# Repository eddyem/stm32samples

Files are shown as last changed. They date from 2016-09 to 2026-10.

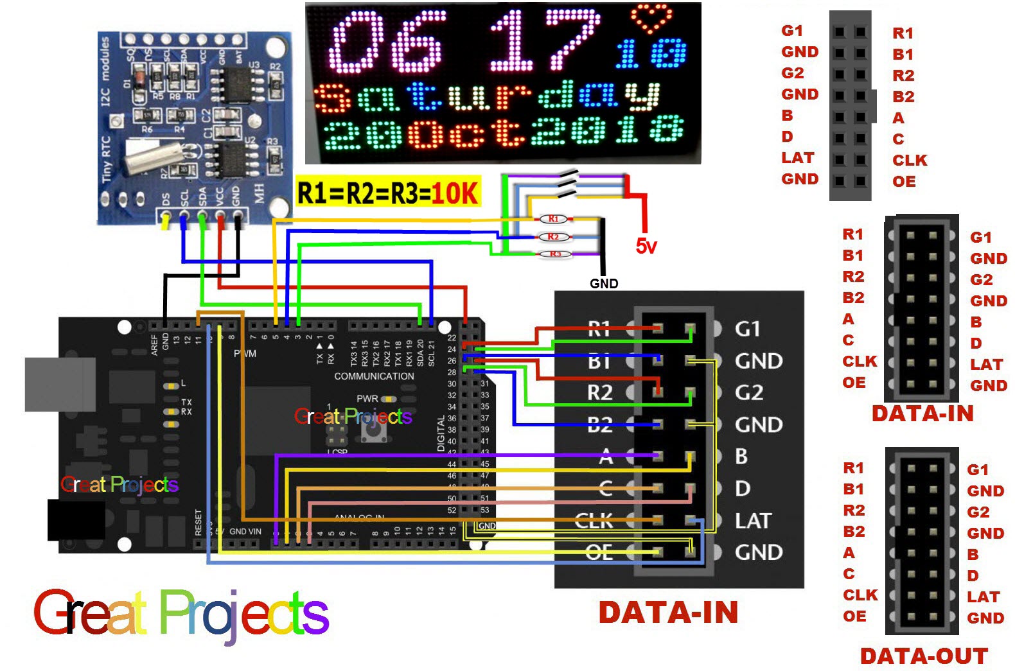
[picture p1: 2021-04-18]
F1:F103/RGB_LED_Screen/img/P4RGBmatrix.jpg

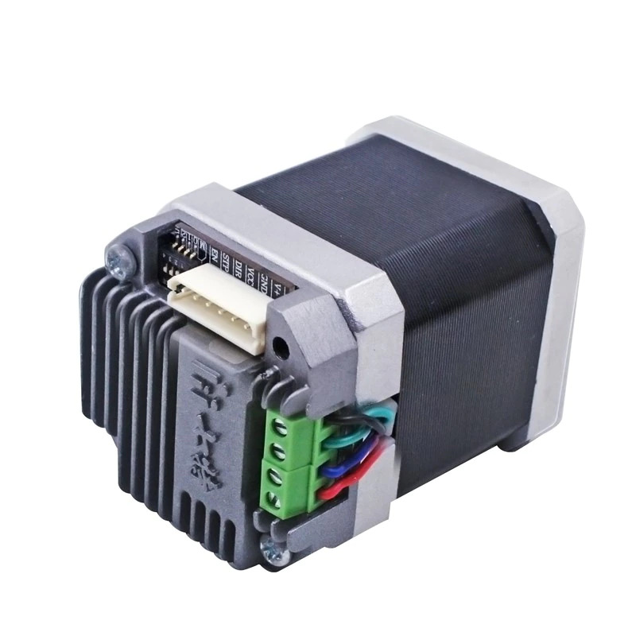
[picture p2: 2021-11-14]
F0:F030,F042,F072/3steppersLB/stepper_driver/08.jpg

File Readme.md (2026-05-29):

# Repository Overview

The `stm32samples` repository is a collection of low-level, bare-metal code examples and complete
projects for various STM32 microcontroller series (F0, F1, F3, F4, G0). It uses CMSIS header files
from `modm-io/cmsis-header-stm32` for register definitions.

## Project Structure by MCU Series

### STM32F0 (F030, F042, F072)
- **3steppersLB** – Controls 3 stepper motors with encoders via USB/CAN bus
- **blink** – Simple LED toggling
- **CANbus4BTA** – CAN replacement for PEP-CAN
- **CANBUS_SSI** – Works with BTA SSI azimuth encoder
- **Chiller** – Basic chiller temperature controller
- **F0_testbrd** – Tests STM32F0x2 on custom board
- **htu21d_nucleo** – Reads HTU-21D sensor on Nucleo-F042K
- **morze** – Echoes USART1 data as Morse code on TIM3CH1 (PA6)
- **NUCLEO_SPI** – SSI over SPI on Nucleo-F042K
- **PL2303_ringbuffer** – USB CDC ACM with ring buffers
- **QuadEncoder** – Quadrature encoder via timer
- **Servo** – Controls SG-90 style servos
- **Socket_fans** – Manages multiple fans
- **TM1637** – Drives 7‑segment displays
- **tsys01_nucleo** – Reads two TSYS01 sensors
- **uart_blink & uart_blink_dma** – USART echo with DMA
- **usbcan_relay** – Relay board over CAN bus
- **usbcan_ringbuffer** – USB‑CAN adapter with ring buffers
- **USBHID** – USB HID keyboard + mouse

### STM32F1 (F103) 
- **BMP180, BMP280** – I²C temperature/pressure sensors
- **Canon_managing_device** – Controls Canon lenses
- **canUART** – UART‑CAN bridge
- **DHT22_DHT11** – Humidity sensors using timer+DMA
- **DS18** – DS18x20 temperature sensors
- **F1_testbrd** – Test board for LQFP48 packages
- **I2Cscan** – I²C scanner with register R/W
- **LED_Screen** – Drives 32×16 LED matrices (P10)
- **MAX7219_screen** – Controls 8×8 LED matrices
- **RGB_LED_Screen** – HUB75E RGB panel with 8.8.4 color
- **SevenCDCs** – Seven USB‑CDC ACM instances on one MCU (joke project)
- **shutter** – Bistable shutter via USB/external signal
- **Tetris** – Tetris on HUB75E panel
- **USB_HID** – USB HID mouse+keyboard
- **ws2815** – Rainbow effect on WS2815 strips

### STM32F3 (F303)
- **ADC** – Works with ADC peripheral
- **blink** – Toggles LEDs on PB0/PB1
- **CANusb** – USB‑CAN adapter
- **floatPrintf** – Converts floats to strings
- **Multistepper** – Controls up to 64 multiplexed steppers
- **NitrogenFlooding** – Automatic nitrogen flooding
- **PL2303** – PL2303 emulator (old)
- **Seven_CDCs** – Seven USB CDC ACM interfaces
- **usart1fullDMA** – USART1 Rx/Tx DMA with match detection
- **USB_template_CDC** – USB‑CDC template

### STM32F4 (F401)
- **blink** – Simple LED toggling

### STM32G0 (G070, G0B1)
- **blink** – Basic LED blink
- **RTC** – Real‑time clock
- **flash** – Flash memory operations
- **g0b1** – USB‑CDC working on G0B1
- **i2c** – I²C operations
- **usart** – USART communication

### Other Directories
- **deprecated** – Archive of older, no‑longer‑maintained code
- **snippets** – Small reusable code fragments
- **testboard** – KiCad 8 design files

## Development Environment

- **Toolchain**: arm-none-eabi‑gcc with `-flto` optimisations
- **Build**: Structured Makefiles per series
- **Debug**: OpenOCD configuration files provided
- **Libraries**: No third‑party libraries; only CMSIS‑SVD headers

## Project Maturity

- **Alpha**: USB template for F303, MLX90640 all‑sky camera
- **Stable**: LED blink, UART echo, sensor interfaces, USB‑CDC
- **Draft**: CANbus4BTA, MLX90640multi
- **Deprecated**: Older code in `deprecated/`

## Summary

This repository is a valuable resource for learning low‑level STM32 programming without vendor
libraries. It covers practical applications:
- **Industrial control**: Stepper motors, CAN bus, relay boards
- **Sensor interfacing**: Temperature, pressure, humidity, encoders
- **Human‑machine interfaces**: LED matrices, 7‑segment displays, USB HID
- **Communication**: UART, SPI, I²C, USB‑CDC, USB‑HID, CAN
- **Prototyping**: Test boards for F0, F1, F3, G0

For the latest updates, check the repository on GitHub.

## License

This repository is provided under the GNU General Public License v3 or later.
Full text of the GPLv3 is available at <https://www.gnu.org/licenses/gpl-3.0.html>.

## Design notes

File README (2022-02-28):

These are my simple snippets for STM32 (compiled with libopencm3)
Be carefull: due to API changes these projects will compile only with opencm3 from archive libopencm3.ori.tgz

F0 - for STM32F042 and STM32F030
F1 - for STM32F103
F303 - for STM32F303

WARNING!!!
arm-none-eabi-gcc from gentoo have a bug with division on F0. 
Use toolchain from https://developer.arm.com/open-source/gnu-toolchain/gnu-rm/downloads instead!

CMSIS-headers:
https://github.com/modm-io/cmsis-header-stm32

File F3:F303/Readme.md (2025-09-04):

Samples for STM32F303 
=================================

Some simplest of these samples works with [my non-solder devboard](https://github.com/eddyem/stm32samples/tree/master/F0_F1_F3-LQFP48_testboard)

- **ADC** - work with ADC
- **blink** - simple LEDs blink on PB0 and PB1
- **CANusb** - USB-CAN adapter
- **floatPrintf** - work with floats, convert floating point number into a string
- **I2C_scan** - simple I2C scanner
- **Multistepper** - stepper motor controller (8 independend motors or up to 64 multiplexed)
- **NitrogenFlooding** - automatic nitrogen flooding
- **PL2303** - emulates PL2303 (old concept)
- **Seven_CDCs** - 7 CDCs in one device
- **usart1** - read data from USART1 and send it back (blocking sending)
- **usart1fullDMA** - USART1 Rx and Tx DMA access (Rx terminated by character match of '\n' or buffer overflow).
- **usarts** - work with all three USARTs with Tx DMA, send to USART1 data read from other, you can send "2\n" or "3\n" to USART1 for tests of USART2/USART3
- **USB_template** - old USB PL2303 template
- **USB_template_CDC** - new USB-CDC template

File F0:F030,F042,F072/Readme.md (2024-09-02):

Samples for STM32F042-nucleo and chinese STM32F030-based devboard
=================================

This directory contains examples for F0 without any library

- **3steppersLB** - control independent moving of 3 stepper motors with encoders (by USB and CAN bus)
- **blink** - simple LED blink
- **CANbus4BTA** - (under development) device to replace old PEP-CAN @BTA
- **CANBUS_SSI** - work with BTA SSI azimutal encoder
- **Chiller** - simplest chiller controller
- **F0_testbrd** - sample code for STM32F0x2 checking via test board
- **htu21d_nucleo** - operaing with HTU-21D in STM32F042-nucleo
- **inc** - all encludes need
- **morze** - for STM32F030, echo data from USART1 on TIM3CH1 (PA6) as Morze code
- **NUCLEO_SPI** - tests of SSI over SPI
- **PL2303_ringbuffer** - emulation of PL2303 with ring buffers on USB Rx/Tx 
- **QuadEncoder** - sample code for working with quadrature encoder (via timer)
- **Servo** - simple servo (like SG-90) controller
- **Snippets** - some small code snippets
- **Socket_fans** - fan manager
- **TM1637** - work with 7-segment LED indicators based on TM1637
- **tsys01_nucleo** - read two TSYS01 sensors using STM32F042
- **uart_blink** - code for STM32F030F4, echo data on USART1 and blink LEDS on PA4 and PA5
- **uart_blink_dma** - USART over DMA
- **uart_nucleo** - USART over DMA for STM32F042-nucleo
- **usbcan_relay** - relay and some other management board over CAN bus
- **usbcan_ringbuffer** - USB--CAN adapter
- **USBHID** - USB HID keyboard + mouse

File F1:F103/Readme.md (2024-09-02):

- **BMP180** - I2C temperature/pressure sensor BMP180
- **BMP280** - I2C temperature/pressure sensor BMP280 and temp/pres/humidity sensor BME280
- **Canon_managing_device** - device for independent managing of some Canon lens
- **canUART** - UART-CAN bridge
- **chronometer_v3** - chrono-3
- **DHT22_DHT11** - DHT11 and DHT22 humidity/temperature sensors management based on timer+DMA
- **DS18** - DS18x20 temperature sensor management
- **F1_testbrd** - code for universal testboard for STM32 in LQFP48 package
- **I2Cscan** - simplest I2C scanner, can read and write registers
- **inc** - base includes
- **led_blink** - simple blink
- **LED_Screen** - management with matrixes of LED screens 32x16 (or another size) pixels (P10)
- **MAX7219_screen** - work with N LED matrices 8x8
- **PL2303_rb_strip** - "naked" PL2303 (without UART)
- **PL2303_ringbuffer** - PL2303 with ringbuffer 
- **pwmdmatest** - generate signals on PA8 by PWM through DMA @ TIM1_CC1 (awfull code)
- **pwmtest** - generate signals on PA8 by PWM @ TIM1_CC1
- **RGB_LED_Screen** - HUB75E-based RGB LED panel management, 8.8.4 color (RRRGGGBB)
- **SevenCDCs** - a joke - 7 CDCs @ one STM32F103
- **shutter** - bistable shutter management (via USB and external signal)
- **SI7005_HTU21D** - work with I2C humidity/temperature sensors SI7005 & HTU21D
- **SPI** - SPI over DMA for "bluepill"
- **Tetris** - some games @ HUB75E-based RGB LED panel: snake, balls and tetris
- **uart** - simplest UART snippet
- **USB_HID** - USB HID (mouse + keyboard)
- **USB_SPI** - work with SPI over USB
- **ws2815** - running rainbow on LED strip WS2815

- **STM32F103C.md** - markdown table for 48-pin STM32F103, use it as template in Readme.md, to format 
pretty looking table [use](https://josh.fail/2022/pure-bash-markdown-table-generator/) `markdown-table -5 -s"|" < STM32F103C.md >> Readme.md` 
after filling it with your data.

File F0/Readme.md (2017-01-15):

Samples for STM32F042-nucleo and chinese STM32F030-based devboard
=================================

- blink - simple LED blink
- uart - USART over DMA with hardware end-of-string detection

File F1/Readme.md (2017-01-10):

These are my simple snippets for STM32F103-based chinese devboards

- 1_wire - pseudo-hardware realisation of 1-wire protocol
- canon_lens - Canon EF lens management
- client-term is terminal client used instead of "com"
- distance_meters - Distance meter based on ultrasonic sensor HC-SR04 & Sharp 2Y0A02 IR sensor
- DMA_GPIO - simple 8-bit FSMC emulation with DMA
- GPIO_TIM - simple FSMC emulation by timer interrupts
- GPS - first approximation to GPS clock
- GPS+ultrasonic - GPS-based timelapse tool allows to get precision (milliseconds) time for four types of sensors 
- hid_mouse_keyboard - a very simple example of simultaneous STM32 work as compound USB-HID device: usb & mouse
- Jeep_generator - krancshaft signal emulator for Jeep
- keyboard_snippet - This snippet allows to emulate USB keyboard
- matrix_keyboard - connect simple matrix keyboard 3x3 or 4x4 to computer as regular USB keyboard
- nokia5110 - print on a nokia5110 display text sent by terminal  
- simple_cdc - simplest USB-CDC working in char-mode, press H for help (another commands are for LEDs switching and test of integer input)
- stepper_motion - move stepper motor 
- Timelapse_keyboard - USB-keyboard emulator that prints precision time of different sensors and switches (for sport competitions)
- ultrasonic - Distance meter based on ultrasonic sensor HC-SR04 & Sharp 2Y0A02 IR sensor
- USBCDC_template - Template of USB-CDC

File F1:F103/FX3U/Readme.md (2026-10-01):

# A useful thing made of a Chinese FX3U clone

Device works over RS-232 (default 115200 8N1), CAN bus (default 250 kbit/s), or MODBUS-RTU (default
9600 8N1).

Full pinout table is available in `hardware.c`.

The firmware help output also prints the build number and build date from `version.inc`.

## Startup diagnostics

On power-up or reset the firmware prints a startup banner over USART1:

```
START
IWDGRSTF=1    # reset occurred due to independent watchdog
SFTRSTF=1     # software reset (NVIC_SystemReset)
PORRSTF=1     # power-on / power-down reset
PINRSTF=1     # reset via NRST pin
```

Only the flags that were actually set are printed. After printing, all reset flags are cleared.

## Hardware notes

### Inputs (X)

X8 is not a screw terminal — it is the on-board "Prog" pushbutton (PB2).
X9 is absent. Bits of the `inchannels` mask correspond to these positions.

| Ch  | Pin  | Notes |
|-----|---|---|
| X0  | PB13 | |
| X1  | PB14 | |
| X2  | PB11 | |
| X3  | PB12 | |
| X4  | PE15 | |
| X5  | PB10 | |
| X6  | PE13 | |
| X7  | PE14 | |
| X8  | PB2  | on-board "Prog" button |
| X9  | — | absent |
| X10 | PE11 | |
| X11 | PE12 | |
| X12 | PE9  | |
| X13 | PE10 | |
| X14 | PE7  | |
| X15 | PE8  | |

### Outputs (Y)

Y8 and Y9 are absent.

| Ch  | Pin  |
|-----|---|
| Y0  | PC9  |
| Y1  | PC8  |
| Y2  | PA8  |
| Y3  | PA0  |
| Y4  | PB3  |
| Y5  | PD12 |
| Y6  | PB15 |
| Y7  | PA7  |
| Y8  | — |
| Y9  | — |
| Y10 | PA6  |
| Y11 | PA2  |

### On-board LED

"RUN" LED is on PD10. **Active low**: `led` returns the logical state (`1` when the LED is on,
`0` when off).

### ADC channels

| № | Enum | Pin / source | Meaning |
|---|---|---|---|
| 0 | `ADC_CH_0` | PA1 / adc1 | voltage input, up to 11 V |
| 1 | `ADC_CH_1` | PA3 / adc3 | voltage input, up to 11 V |
| 2 | `ADC_CH_2` | PC4 / adc14  | voltage input |
| 3 | `ADC_CH_3` | PC5 / adc15  | current input |
| 4 | `ADC_CH_4` | PC0 / adc10  | current input, 0..20 mA |
| 5 | `ADC_CH_5` | PC1 / adc11  | current input |
| 6 | `ADC_POT0` | PC2 / adc12  | right on-board potentiometer |
| 7 | `ADC_POT1` | PC3 / adc13  | left on-board potentiometer |
| 8 | `ADC_CH_TSEN`| internal | MCU temperature sensor |
| 9 | `ADC_CH_VDD` | internal | Vdd reference |

Each channel is sampled continuously in scan mode via DMA into a circular buffer of `9 ×
ADC_CHANNELS` values. The getter returns the median of the last 9 samples per channel. Reported raw
values are 12-bit (0..4095).

The `mcutemp` command returns MCU temperature in `°C × 10` (as `int32_t`).

## Runtime parameters

### Watchdog

IWDG prescaler `/4` (LSI ≈ 40 kHz) with reload 1250 → about **125 ms** watchdog timeout. Refreshed
in every main-loop iteration, in DMA/send wait loops and during flash writes. Any hang longer than
that triggers a reset.

### CAN timeouts

- Mailbox wait inside `CAN_send()`: `SEND_TIMEOUT_MS / 10` = **10 ms**.
- High-level send loops (command reply, ESW notifications): up to `SEND_TIMEOUT_MS` = **100 ms**.
If a message cannot be queued, `error=canbusy` is printed to USART.

### Buffer sizes

| Subsystem | Macro | Value | Notes |
|---|---|---|---|
| USART input  | `UARTBUFSZI` | 196 | longer lines are dropped; firmware prints `USART IN buffer overflow!` |
| USART output | `UARTBUFSZO` | 256 | |
| CAN RX queue | `CAN_INMESSAGE_SIZE` | 8 | extra messages are dropped silently |
| Modbus RX | `MODBUSBUFSZI` | 68 | |
| Modbus TX | `MODBUSBUFSZO` | 64 | |

## Serial protocol

Every command is a string terminated by `\n`. General syntax:

```
command[number][=value]
```

- `command` — command name (letters/digits);
- `number` — optional parameter number, 0..127;
- `=value` — optional setter value.

Numbers are parsed by `getnum()` and accept decimal (`123`), hexadecimal (`0x7B`), octal (`0173`)
and binary (`0b1111011`). Signed values (`getint()`) allow a leading `-`.

Values in parentheses after a flag command is its bit number in the whole `uint32_t`. E.g. to reset
flag `f_relay_inverted` you can call `f_relay_inverted=0` or `flags2=0`.

```
commands format: parameter[number][=setter]
parameter [CAN idx] - help
--------------------------

CAN bus commands:
canbuserr - print all CAN bus errors (a lot of if not connected)
cansniff - switch CAN sniffer mode
s - send CAN message: ID 0..8 data bytes

Configuration:
bounce [14] - set/get anti-bounce timeout (ms, max: 1000)
canid [6] - set both (in/out) CAN ID / get in CAN ID
canidin [7] - get/set input CAN ID
canidout [8] - get/set output CAN ID
canspeed [5] - get/set CAN speed (bps)
dumpconf - dump current configuration
eraseflash [10] - erase all flash storage
f_relay_inverted (2) - inverted state between relay and inputs
f_send_esw_can (0) - change of IN will send status over CAN with `canidin`
f_send_relay_can (1) - change of IN will send also CAN command to change OUT with `canidout`
f_send_relay_modbus (3) - change of IN will send also MODBUS command to change OUT with `modbusidout` (only for master!)
flags [17] - set/get configuration flags (as one U32 without parameter or Nth bit with)
modbusid [20] - set/get modbus slave ID (1..247) or set it master (0)
modbusidout [21] - set/get modbus slave ID (0..247) to send relay commands
modbusspeed [22] - set/get modbus speed (1200..115200)
saveconf [9] - save configuration
usartspeed [15] - get/set USART1 speed

IN/OUT:
adc [4] - get raw ADC value for the given channel (0..9)
esw [12] - anti-bounce read inputs
eswnow [13] - read current inputs' state
led [16] - work with onboard LED
relay [11] - get/set relay state (0 - off, 1 - on)

Other commands:
inchannels [18] - get u32 with bits set on supported IN channels
mcutemp [3] - get MCU temperature (*10degrC)
modbus - send modbus request with format "slaveID fcode regaddr nregs [N data]", to send zeros you can omit rest of 'data'
modbusraw - send RAW modbus request (will send up to 62 bytes + calculated CRC)
outchannels [19] - get u32 with bits set on supported OUT channels
reset [1] - reset MCU
time [2] - get/set time (1ms, 32bit)
wdtest - test watchdog
```

Value in square brackets is the CAN bus command code (see below).

### Notes on specific commands

#### `bounce`

`bouncetime` (default 50 ms) is not a classical debounce delay — it is the **per-input sampling
interval**. Once an input has been sampled, it will not be re-read until `bouncetime` milliseconds
have elapsed. Worst-case reaction time for an input change is therefore up to `bouncetime` ms;
changes within that window are ignored (which is the debounce behaviour itself).

#### `s`

Send a CAN message. All numbers are space-separated; the first is the CAN ID (0..0x7FF), the
remaining 0..8 numbers are data bytes. Numbers may be given in any format accepted by `getnum()`.

```
s 0x123 0x11 0x22 0x33
s 291 1 2 3 4
```

On invalid arguments the firmware prints `error=badpar` / `error=badval` / `error=wronglen` and
sends nothing.

#### `cansniff`

When enabled, every received CAN frame is printed to USART in the format:

```
<time_ms> #<ID> <b0> <b1> ...
```

All fields are hexadecimal except `<time_ms>`. While messages are being received, the regular
periodic USART keep-alive is suppressed.

#### `adc`

Accepts a parameter number 0..9 (`ADC_CHANNELS - 1`). Numbers outside this range return
`error=badpar`.

#### `flags`

With a parameter number (0..`MAX_FLAG_BITNO` = 0..3): sets/reads the Nth bit only. Without a
parameter ("no par", 0x7F): operates on the whole `uint32_t`. Bits above `MAX_FLAG_BITNO` return
`error=badpar`.

### Default configuration

Flash storage is empty after flashing; on first boot `flashstorage_init()` returns `currentconfidx
= -1` and the firmware uses `USERCONF_INITIALIZER` from `flash.c`:

```
CANspeed    = 250000
CANIDin     = 1
CANIDout    = 2
usartspeed  = 115200
bouncetime  = 50
modbusID    = 1
modbusIDout = 2
modbusspeed = 9600
flags       = { sw_send_relay_inv = 1 }
```

After the first `saveconf`, these defaults are replaced by the stored record.

## CAN bus protocol

Default speed is 250 kbit/s. Default CAN IDs are 1 (input) and 2 (output) for a slave. **All
multi-byte data is little-endian.**

| Byte(s) | Meaning |
|---|---|
| 0, 1 | `uint16_t` command code (see table below) |
| 2 | `uint8_t` parameter number: 0..126, ORed with 0x80 for setter, 127 = "no parameter" |
| 3 | `uint8_t` error code (only in device answers) |
| 4..7 | `int32_t` data |

When the device receives a CAN packet addressed to its own ID or to ID = 0 ("broadcast"), it
performs the requested action and sends an answer (usually a getter reply). If the command cannot
be executed or carries bad data, the device returns the same packet with the error code inserted
into byte 3.

Getters may be requested by a 3-byte packet (command code + parameter). "No parameter" (0x7F) in
some commands means "all data" — e.g. get/set all relays or get all inputs.

### CAN bus error codes (byte 3 of the answer)

| Code | Name | Meaning |
|---|---|---|
| 0 | `ERR_OK` | all OK |
| 1 | `ERR_BADPAR` | wrong parameter |
| 2 | `ERR_BADVAL` | value out of range |
| 3 | `ERR_WRONGLEN` | wrong message length (for setter or where a parameter is required) |
| 4 | `ERR_BADCMD` | unknown command code |
| 5 | `ERR_CANTRUN` | cannot run the command (bad parameters or other reason) |

Bus-level errors (stuff/form/ack/bit/CRC, bus-off, error-passive, error-warning) are not reported
in byte 3. They are printed over USART by `CAN_printerr()` when the `canbuserr` printer is enabled:

```
Receive error counter: <n>
Transmit error counter: <n>
Last error code: <name>
[Bus off] [Passive error limit] [Error counter limit]
```

### CAN command codes

| Code | Enum | Text command |
|---|---|---|
| 0  | `CMD_PING` | (ping) |
| 1  | `CMD_RESET` | `reset` |
| 2  | `CMD_TIME` | `time` |
| 3  | `CMD_MCUTEMP` | `mcutemp` |
| 4  | `CMD_ADCRAW` | `adc` |
| 5  | `CMD_CANSPEED` | `canspeed` |
| 6  | `CMD_CANID` | `canid` |
| 7  | `CMD_CANIDin` | `canidin` |
| 8  | `CMD_CANIDout` | `canidout` |
| 9  | `CMD_SAVECONF` | `saveconf` |
| 10 | `CMD_ERASESTOR` | `eraseflash` |
| 11 | `CMD_RELAY` | `relay` |
| 12 | `CMD_GETESW` | `esw` |
| 13 | `CMD_GETESWNOW` | `eswnow` |
| 14 | `CMD_BOUNCE` | `bounce` |
| 15 | `CMD_USARTSPEED` | `usartspeed` |
| 16 | `CMD_LED` | `led` |
| 17 | `CMD_FLAGS` | `flags` |
| 18 | `CMD_INCHNLS` | `inchannels` |
| 19 | `CMD_OUTCHNLS` | `outchannels` |
| 20 | `CMD_MODBUSID` | `modbusid` |
| 21 | `CMD_MODBUSIDOUT`  | `modbusidout` |
| 22 | `CMD_MODBUSSPEED`  | `modbusspeed` |

### Examples

All data in hex. Slave ID is omitted.

Get current time:
- request: `02 00 00`
- answer: `02 00 00 00 de ad be ef` — last four bytes are time in ms since power-up.

Set relay number 5:
- request: `0b 00 85 00 01 00 00 00`
- answer: `0b 00 05 00 01 00 00 00`

Set relays 0..3, reset the rest:
- request: `0b 00 ff 00 07 00 00 00`
- answer: `0b 00 7f 00 07 00 00 00`

Changing flags works like the text command: with a parameter number the Nth bit is changed, without
a parameter the whole `uint32_t` is replaced.

## MODBUS-RTU protocol

The device can operate as master or slave. Default format is 9600-8N1. **Big-endian**, as the
standard requires. Default slave ID is 1, and the "relay command" target ID is 2.

Set `modbusid=0` to enter master mode. In master mode the device no longer answers incoming modbus
requests, but instead parses incoming **responses** and prints them to USART.

The `modbus` command sends a formal modbus request in the format:

```
modbus = slaveID fcode regaddr nregs [N data]
```

All numbers are space-separated and parsed by `getnum()` (decimal / hex / octal / binary).
`slaveID` and `fcode` are one byte each; `regaddr` and `nregs` are two bytes little-endian; `N` is
one byte; `data` is N bytes. Optional data bytes are allowed only for "multiple" functions (0x0F,
0x10). For simple setters (0x05, 0x06) `nregs` is the two-byte value written to the slave.

```
modbus = 1 6 2 1             # slave 1, write register, register 2 (MR_LED), value 1
modbus = 1 0x0f 0 8 1 0xff   # slave 1, write coils, 8 coils, 1 byte of data
```

`modbusraw` does not validate the fields; it just sends the data (user should add CRC by himself).
Useful for testing unusual requests.

In master mode, flag `f_send_relay_modbus` makes the device send an "write coils" command with ID =
`modbusidout` every time the IN state changes. This lets you bind several devices: inputs of one
drive the outputs of another. If `modbusidout` is zero, a broadcast is sent (slaves do not reply to
broadcasts, they just perform the action).

### Implementation notes

- Modbus uses UART4 with DMA for both RX and TX. End of frame is detected by the IDLE interrupt.
- There is no 3.5-character silent-interval handling — any IDLE marks the end of a packet.
- Input buffer is 68 bytes (up to 67 data bytes), output buffer is 64 bytes (up to 64 bytes).
Enlarge `MODBUSBUFSZI` / `MODBUSBUFSZO` in `modbusrtu.h` if needed.
- Maximal modbus slave ID is 247.
- The device does **not reply** to broadcast requests (ID = 0).

### Slave registers

Holding registers: `[R]` = read-only, `[W]` = write-only, `[RW]` = read/write.

| № | Symbol | Access | Meaning |
|---|---|---|---|
| 0 | `MR_RESET` | W | reset MCU |
| 1 | `MR_TIME` | RW | MCU time in ms (`uint32_t`) |
| 2 | `MR_LED` | RW | on-board LED state |
| 3 | `MR_INCHANNELS` | R | `uint32_t` of available IN channels |
| 4 | `MR_OUTCHANNELS`  | R | `uint32_t` of available OUT channels |

### Supported function codes

#### 01 — read coils
Read state of all relays. `regaddr` must be 0, `nregs` must be a multiple of 8 (in this hardware: 8 or 16). Answer contains `nregs / 8` bytes; bit 0 of the first data byte is relay 0.

Example — read all relays; only relay 10 active:
- request: `01 01 00 00 00 10`
- answer: `01 01 02 00 04`

Errors: `02` — non-zero `regaddr`; `03` — `nregs` not a multiple of 8 or too large.

#### 02 — read discrete inputs
Same semantics as "read coils", but for the IN channels.

Example — read first 8 INs; all 4 low-order inputs active:
- request: `01 02 00 00 00 08`
- answer: `01 02 01 0f`

#### 03 — read holding register
Reads one register at a time.

Example — read time:
- request: `01 03 00 01 00 01`
- answer: `01 03 04 01 53 15 00` — value `0x00155301` = 1397505 ms ≈ 1397.5 s.

Errors: `02` — bad `regaddr`; `03` — `regno != 1`.

#### 04 — read input register
Read `nregs` ADC channels starting at `regaddr`.

Example — read channels 5..8:
- request: `01 04 00 05 00 04`
- answer: `01 04 08 6c 08 21 00 33 00 41 00` — `0x086c` (2156) for channel 5, etc.

Errors: `02` — bad start channel; `03` — bad amount (zero or beyond last channel).

#### 05 — write coil
Changes a single relay state. `regaddr` — relay number, `nregs` — value (0 = off, non-zero = on).

Example - turn on coil 3:
- request: `01 05 00 03 00 01`
- answer: `01 05 00 03 00 01`

Errors: `02` — bad relay number.

#### 06 — write holding register
Writes to one register (`MR_RESET`, `MR_TIME` or `MR_LED`).

Example — turn LED on:
- request: `01 06 00 02 00 01`
- answer: `01 06 00 02 00 01`

Errors: `02` — bad register.

#### 0F — write multiple coils
Changes all relays at once. `regaddr` must be 0, `nregs` a multiple of 8, `N` = `(nregs + 7) / 8`.
Each data bit is a relay state.

Example — turn on relays 0..7:
- request: `01 0f 00 00 00 08 01 ff`
- answer: `01 0f 00 00 00 08`

Turn on all relays (0..7 and 10, 11):
- request: `01 0f 00 00 00 10 02 ff 0f`
- answer: `01 0f 00 00 00 10 56 c2`

Errors: `02` — non-zero `regaddr`; `03` — wrong amount; `07` — cannot change relays.

#### 10 — write multiple registers
Only `MR_TIME` can be written this way; `nregs` must be 1 and the data length 4 bytes.

Example — clear `Tms`:
- request: `01 10 00 01 00 01 04 00 00 00 00`
- answer: `01 10 00 01 00 01`

Errors: `02` — wrong register.

### Modbus exception codes

| Code | Name | Meaning |
|---|---|---|
| 01 | `ME_ILLEGAL_FUNCION` | function code is not authorized for the slave |
| 02 | `ME_ILLEGAL_ADDRESS` | data address is not authorized |
| 03 | `ME_ILLEGAL_VALUE` | data field value is not authorized |
| 04 | `ME_SLAVE_FAILURE` | unrecoverable error |
| 05 | `ME_ACK` | accepted, but processing takes a long time |
| 06 | `ME_SLAVE_BUSY` | slave is busy |
| 07 | `ME_NACK` | programming request cannot be performed |
| 08 | `ME_PARITY_ERROR` | memory parity error |

## Limitations

- CAN RX queue holds 8 messages; extras are dropped silently.
- USART RX buffer holds 196 bytes; longer lines are discarded with an error message.
- Modbus does not implement the 3.5-character silent interval. Buffers are 67/64 bytes.
- The Modbus master does not implement retries, timeouts or a transaction queue — it just prints
incoming responses. Reliable exchange should be arranged by the host.
- CAN filters accept only the configured `CANIDin` plus ID 0 (broadcast); the "monitor" mode adds a
second, match-all filter.
- The IWDG is enabled in release builds. Any hang longer than ~125 ms triggers a reset.
- The `EBUG` build disables the IWDG and enables verbose `DBG(...)` messages.

## Short programming guide

### Adding a new value to flash storage

All stored values are described in `struct user_conf` (`flash.h`). You can add new fields, but keep
32-bit alignment in mind. Bit flags live in `union confflags_t`, which combines 32-bit and per-bit
access.

After adding a field:
1. Add a setter/getter (usually via `u32setget` or `flagsetget`).
2. Add a line in `dumpconf()` (`proto.c`).

The text protocol allows working with flags by their semantic name. To add a flag, edit `proto.c`:
- add a `static const char* S_f_...` constant with the flag name;
- add its address to the `bitfields[]` array **in the same order as the bits are defined in
`confflags_t`** (critical: `dumpconf` and `confflags` index this array by bit number);
- add an entry to the `text_cmd` enum;
- add a `funcdescr` entry to `funclist`;
- modify `confflags()` for setter/getter handling.

### Adding a new command

Base commands are processed in `canproto.c` and `proto.c`. `modbusproto.c` handles modbus-specific
commands.

To add a CAN/serial command:

1. Add an enum member in `canproto.h` (`CMD_...`). **This value is the numeric command code** on
the wire.
2. Add a string constant with the text command name in `proto.c`.
3. Add a `funcdescr` entry to `funclist`.
4. Implement the handler in `canproto.c` (returns one of `errcodes`, receives a `CAN_message *`).

**Important:** the `funclist[]` array in `canproto.c` is indexed by enum value — the entry for
`CMD_X` must be at array position `CMD_X`. Use designated initializers (`[CMD_X] = {...}`) as the
existing code does.

The `commonfunction` struct has fields `{fn, minval, maxval, datalen}`:
- `minval == maxval` disables range checking of the value (bytes 4..7) for setter commands;
- `datalen` is the minimal packet length in bytes that the handler requires.

The handler only sees a `CAN_message *`. The serial parser builds an equivalent packet from user
input: `[C C P 0 V0 V1 V2 V3]`, where `C` = command code (little-endian); `P` = parameter number
(or 0x7F if not specified), ORed with 0x80 in case of a setter; `Vx` = bytes of the user value
(little-endian).

For `uint32_t` configuration values use `u32setget`; for bit flags — `flagsetget`.

### Adding a serial-only command

If the command has no CAN equivalent, work purely in `proto.c`:
- add an entry to the `text_cmd` enum (negative indices are used in `funclist`);
- add a string constant and a `funcdescr` entry;
- implement the handler with signature `errcodes fn(const char *str, text_cmd cmd)`;
- register it in the `textfunctions[]` array.

### Working with modbus

Modbus-specific enums (`modbus_fcode`, `modbus_exceptions`) and structs (`modbus_request`,
`modbus_response`) are declared in `modbusrtu.h`. `data` fields hold bytes in wire order. For
requests without data (Fcode ≤ 6), `data` may be `NULL`.

High-level modbus slave handlers live in `modbusproto.c`. To add a new register, extend the
`modbus_registers` enum in `modbusproto.h` and handle the new value in `readreg()`, `writereg()` or
`writeregs()`. The main dispatch point is `parse_modbus_request()`.

---

## License

All source files are licensed under **GNU General Public License v3.0** unless stated otherwise.

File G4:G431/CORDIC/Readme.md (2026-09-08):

# STM32 Astronomy & CORDIC Test Project

## Introduction

This project is designed for **STM32G4** microcontrollers (specifically the STM32G431) and provides a
framework for:

- **Astronomical coordinate transformations** (Alt-Az vs HA-Dec, RA/HA, Local Sidereal Time).
- **Atmospheric refraction** modelling using a single-precision adaptation of SOFA/ERFA algorithms.
- **Performance comparison** between standard `math.h` functions and the hardware-accelerated **CORDIC** unit 
  built into the STM32G4.
- **Interactive control** via a serial (UART) command interface.
- **Precise timing** measurements using a 32-bit timer.

All calculations are performed in **single-precision floating-point** for speed on microcontrollers without 
hardware double-precision support.

---

## Hardware Platform

- **MCU**: STM32G431 (or any STM32G4 with CORDIC).
- **Clock**: HSE oscillator, system frequency defined by `SysFreq` (usually 170 MHz).
- **GPIO**:
  - **PC6** - LED (active high).
  - **PC13** - User button (pull-down, pressed = high).
- **USART1**:
  - **PA9** - TX (alternate function 7).
  - **PA10** - RX (alternate function 7).
- **Timers**:
  - **SysTick** - 1-ms system tick (`Tms`).
  - **TIM2** - 32-bit counter running at 1-MHz for microsecond measurements.

---

## Building and Flashing

The project is intended for use with **GCC ARM** toolchain. Key build definitions:

- `SysFreq` - system clock frequency in Hz (e.g., 170000000).
- `BUILD_NUMBER` and `BUILD_DATE` are defined in `version.inc` (generated by `make`).

Flashing can be done via SWD using st-link (`make flash`), via DFU (`make dfuboot`) or via USART1 bootloader
(`make boot`).

---

## Software Architecture

The system runs an infinite loop in `main()` that:
- Services the UART (receiving and sending data).
- Parses incoming commands via `parse_cmd()`.
- Blinks the LED every 500 ms.
- Detects button presses and measures press/release duration using TIM2.

---

## Module Descriptions

### 1. `hardware.c/h` - Low-level initialisation

- `gpio_setup()`: configures GPIOs, enables SysTick (1 ms interrupt), and initialises TIM2 for microsecond counting.
- Provides macros for LED and key handling:
  - `LED_ON()`, `LED_OFF()`, `LED_TOGG()`
  - `KEY_PRESSED()` - returns true if PC13 is high.
- `timer_start()`, `timer_stop()`, `timer_read()` - control TIM2 for precise time measurements.

### 2. `usart.c/h` - UART1 with DMA and ring buffers

- Uses **circular DMA** for RX and **normal DMA** for TX.
- RX buffer size: 256 bytes (DMA) + 512 bytes (ring buffer).
- TX buffer size: 512 bytes (ring buffer) + 256 bytes (DMA).
- Interrupts:
  - USART1 interrupt - detects end-of-line (`\n`) and triggers line processing.
  - DMA1 Channel 1 (RX) - handles receive error (buffer overflow).
  - DMA1 Channel 2 (TX) - signals transmit completion.
- Functions:
  - `usart_setup(uint32_t baud)` - initialises UART at the given baud rate.
  - `usart_sendstr(const char*)` - queues a string for transmission.
  - `usart_getline()` - returns a pointer to a null-terminated buffer containing one line (ends with `\n`), or `NULL` if no complete line.
  - `usart_process()` - must be called frequently to feed the TX buffer and move RX data from DMA to the ring buffer; returns status flags.

### 3. `commproto.cpp` - Command protocol

- Parses commands of the form:
  ```
  command [args] [= value]
  ```
- Built-in commands and variables (see **Usage** below).
- Uses a **hash table** (compile-time hashing) to dispatch commands efficiently.
- Supports **getter** and **setter** for floating-point variables (az, dec, ha, ra, zd, humid, press, temp).
- Command results are sent back via the UART send function.
- Error codes are defined in `commproto.h`.

### 4. `astro.c/h` - Astronomical calculations

All angles are in **degrees** unless otherwise noted.

- **Time**:
  - `MJD_from_unix(uint32_t t)` - converts Unix time (seconds since 1970-01-01) to Modified Julian Date (MJD).
  - `LST_from_unix(uint32_t t)` - computes Local Sidereal Time (in hours) for the observer's longitude (`long_hrs`).
- **Coordinate transformations**:
  - `altaz_to_hadec()` - convert Alt-Az to HA-Dec.
  - `hadec_to_altaz()` - convert HA-Dec to Alt-Az.
  - `ha_to_ra()` and `ra_to_ha()` - convert between Hour Angle and Right Ascension given LST.
- **Refraction** (single-precision adaptation of ERFA `eraRefco`):
  - `refco_f32(float P, float T, float RH, float wavelength, float *refa, float *refb)` - computes A and B coefficients for the refraction model:  
    `dz = A*tan(z) + B*tan(z)^3` (z = zenith distance).
  - `refraction(float P, float T, float RH, float zd)` - returns the refraction correction in degrees.
- The observer's **latitude** and **longitude** are fixed in the code (`lat_rad` and `long_hrs`). They may be changed by editing `astro.c`.

### 5. `cordic.c/h` - Hardware CORDIC wrappers

- Interfaces with the STM32G4 CORDIC coprocessor.
- Functions:
  - `cordic_sincos(float angle, float *sin, float *cos)` - computes sine and cosine in one call.
  - `cordic_sin(float angle)`, `cordic_cos(float angle)` - individual functions.
  - `cordic_atan(float x)` - returns atan(x), x in [-1,1].
  - `cordic_sqrt(float x)` - returns sqrt(x) for x > 0.
  - `cordic_log(float x)` - returns natural logarithm of x (x > 0).
- **Precision**: Q1.31 fixed-point (32-bit) with 5 iterations (`CORDIC_CSR_PRECISION = 5`).
- Input scaling and normalisation are handled inside each function.

### 6. `strfunc.c/h` - String utilities

- Number formatting:
  - `u2str()`, `i2str()`, `uhex2str()` - convert integers to strings.
  - `float2str(float x, uint8_t prec)` - convert float to a compact string with optional scientific notation.
- Number parsing:
  - `getnum()`, `getint()`, `getfloat()` - parse numbers (decimal, hex, binary, signed, floating with exponent).
- `omit_spaces()` - skip leading whitespace.

### 7. `ringbuffer.c/h` - Circular buffer

- Generic ring buffer for arbitrary data.
- Functions:
  - `RB_write()`, `RB_read()`, `RB_readto()` (read until a delimiter), `RB_hasbyte()`, `RB_datalen()`, `RB_clearbuf()`.

### 8. `test.c/h` - Performance tests

- Runs a fixed number of iterations (`N_TESTS = 1000`) on random data.
- Measures execution time using TIM2 (microseconds).
- Tests available:
  - `math` functions: `sinf`, `cosf`, `atanf`, `sqrtf`, `logf`.
  - `CORDIC` functions: `sincos`, `sin`, `cos`, `atan`, `sqrt`, `log`.
  - **Astronomy** tests:
    - Coordinate transformations (Alt-Az vs HA-Dec) - measures time per conversion.
    - Refraction cycle (ha-dec to alt-az, apply refraction and convert back) - includes `refraction()`.
    - LST calculation - measures time per LST computation.

---

## Usage: UART Commands

Connect to the USART1 (default baud rate **115200**, 8N1) using a terminal program. The device echoes
responses to commands.

General syntax:
```
command [args] [= value]
```
- Without `= value`, the command acts as a **getter** (prints current value) or command that don't needs
  argument.
- With `= value`, it acts as a **setter**.

All floating-point values are printed with 7 decimal places.

### Available Commands

| Command | Description |
|---|---|
| `help` | Show this help message. |
| `testtimer` | Test the microsecond timer for 1 second (prints elapsed us). |
| `testc = <func>` | Test CORDIC function: `sincos`, `sin`, `cos`, `atan`, `sqrt`, `log`. Prints time in us. |
| `testm = <func>` | Test `math.h` function: `sin`, `cos`, `atan`, `sqrt`, `log`. Prints time in us. |
| `sincos = <angle>` | Compute sin/cos for given angle (degrees) using both `math.h` and CORDIC, print results. |
| `testastro = <func>` | Test astronomy functions: `coords` (transform cycle), `lst` (LST calculation), `refr` (refraction cycle). Prints time in us and ms. |
| `sets [= 0/1]` | Choose sine/cos implementation: `0` = `math.h`, `1` = CORDIC. |
| `time [= unix_sec]` | Show current Unix time, MJD, and LST. If `= unix_sec` is given, sets the system time. |
| `az [= value]` | Azimuth (degrees, -180..180). |
| `dec [= value]` | Declination (degrees, -90..90). |
| `ha [= value]` | Hour Angle (degrees, -180..180). |
| `ra [= value]` | Right Ascension (degrees, 0..360). |
| `zd [= value]` | Zenith Distance (degrees, 0..90). |
| `humid [= value]` | Relative humidity (0..1). |
| `press [= value]` | Atmospheric pressure (hPa, 0..1200). |
| `temp [= value]` | Temperature (degC, -273.15..100). |
| `hara = 0/1` | Convert HA to RA (`0`) or RA to HA (`1`) using current LST. Updates the corresponding variable. |
| `azhd = 0/1` | Convert Alt-Az to HA-Dec (`0`) or HA-Dec to Alt-Az (`1`). Updates relevant variables (az, zd or ha, dec, ra). |
| `refr` | Compute refraction (arcseconds) for current `zd`, pressure, temperature, humidity. Also prints A/B coefficients. |

**Note**: The `azhd` and `hara` commands automatically use the current system time (from the last `time` setter) to compute LST.

---

## Testing and Performance

The test commands (`testc`, `testm`, `testastro`) measure execution time over 1000 iterations on random input
data. This allows you to compare the speed of hardware CORDIC against software `math.h` and evaluate the
overall efficiency of the astronomical pipeline.

Example outputs (typical for STM32G4 @ 170 MHz):

```
testc = sincos
TIMEus=425
```

```
testm = sin
TIMEus=884
```

```
testastro = coords
TIMEus=159680
TIMEms=159
```

These numbers help in optimising real-time applications such as telescope control.

---

## Notes and Customisation

- **Observer coordinates**: The latitude (43.6535278deg) and longitude (41.44143375deg) are hard-coded in
  `astro.c` as `lat_rad` and `long_hrs`. Modify these for your location.
- **CORDIC precision**: The number of iterations is set to 5 (`CORDIC_CSR_DEF`). You can increase it for 
  better accuracy at the cost of speed.
- **Refraction model**: The model works best for zenith distances up to ~80deg. It uses a wavelength of 
  0.55um (optical) by default.
- **Baud rate**: Default is 115200. Change the argument to `usart_setup()` in `main()` if needed.
- **DMA buffers**: Sizes are defined in `usart.h`. Adjust if you experience overruns.

---

## License

This project is released under the **GNU General Public License v3**. See the header of each source file for 
details.

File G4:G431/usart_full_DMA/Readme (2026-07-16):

Simplest example of working with USART1 fully by DMA (both Rx and Tx).
To detect end of line I use interrupt by symbol '\n' in RXD.
Events of pressing/releasing button on PC13 are written onto terminal.

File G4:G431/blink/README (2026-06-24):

Toggle LED on STM32G431-pill depending on user button:
- pressed - 'SOS' in Morze
- not pressed - blink with period of 1 second

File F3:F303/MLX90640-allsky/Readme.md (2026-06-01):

# IR All-Sky Camera Documentation

## Project Overview

This firmware implements an **infrared all-sky camera system** based on up to five **MLX90640**
thermal imaging sensors (32×24 pixels each), designed for **cloud monitoring** at the Special
Astrophysical Observatory of the Russian Academy of Sciences. The system automates sky quality
assessment for 0.5-meter telescopes of the "Astro-M" complex.

The device continuously captures thermal images from multiple sensors (Zenith, East, South, West,
North), processes environmental data from a **BMP280** pressure/humidity/temperature sensor, and
controls **PWM heaters** to prevent dew formation on optics.

**Repository:** [https://github.com/eddyem/stm32samples/tree/master/F3%3AF303/MLX90640-allsky](https://github.com/eddyem/stm32samples/tree/master/F3%3AF303/MLX90640-allsky)

---

## Hardware Requirements

### Microcontroller
- **STM32F303** series (tested on F303)
- 72 MHz system clock (HSE) or 48 MHz (HSI)

### Sensors
| Sensor | Interface | Purpose |
|---|---|---|
| MLX90640 (up to 5) | I²C (400 kHz) | Thermal imaging (32×24 pixels, -40..+300°C) |
| BMP280 / BME280 | SPI | Ambient temperature, pressure, humidity |
| NTC thermistors (4) | ADC (12-bit) | Heater feedback / backup temperature |

### Outputs
- **DAC output** (PA5) – Onboard heater control (0–3.3V)
- **PWM channels** (TIM3) – External heaters (PA6, PA7, PB0, PB1)
- **UART1** – Main debug/auxiliary interface
- **USB** (CDC class) – Secondary interface

### Pin Assignment (STM32F303)

| Pin | Function | Notes |
|-----|---|---|
| PA0–PA3 | NTC1–NTC4 | ADC inputs |
| PA4 | DAC_OUT1 | Onboard heater |
| PA5 | ADC_IN2 | DAC feedback |
| PA6, PA7 | PWM CH1, CH2 | TIM3_CH1, TIM3_CH2 (external heaters) |
| PA9, PA10 | UART1 TX/RX | Controlling interface |
| PA11, PA12 | USB DP/DM | CDC virtual COM |
| PA13, PA14 | SWD | Programming/debug |
| PA15 | USB DP pullup | USB pullup management for development board |
| PB0, PB1 | PWM CH3, CH4 | TIM3_CH3, CH4 (sky-quality + T-proportional) |
| PB3, PB4, PB5 | SPI SCK, MISO, MOSI | BMP280 interface |
| PB6, PB7 | I²C1 SCL/SDA | MLX90640 bus |
| PB9 | SPI CS | BMP280 chip select |

---

## Firmware Architecture

The firmware is **event-driven** with a **state machine** for MLX90640 data acquisition and a
**command parser** for bidirectional communication over USB and UART.

### Core Modules

| File | Responsibility |
|---|---|
| `main.c` | Main loop, SysTick, initialization, state machine orchestration |
| `adc.c/h` | ADC setup (DMA, median filtering), NTC reading, Vdd measurement |
| `i2c.c/h` | I²C low-level + DMA, multi-word transfers, bus scanning |
| `mlxproc.c/h` | MLX90640 state machine (5 sensors), parameter caching, image processing |
| `mlx90640.c/h` | MLX90640 calibration math (from Melexis datasheet) |
| `BMP280.c/h` | SPI-based BMP280/BME280 driver |
| `heater.c/h` | PWM heater control, dew-point avoidance logic |
| `commproto.cpp/h` | Command parser (USB/UART), ASCII maps, binary image export |
| `usb_dev.c/h` | USB CDC stack (bulk endpoints, ring buffers) |
| `usart.c/h` | UART driver with DMA and ring buffers |
| `spi.c/h` | SPI driver for BMP280 |
| `ringbuffer.c/h` | Circular buffers |
| `strfunc.c/h` | Number/string conversions, hexdumps |

### Data Flow

```
MLX90640 sensors (I²C DMA)
       ↓
mlxproc.c (state machine, 5× parameter loading)
       ↓
mlx90640.c (pixel-by-pixel temperature calculation)
       ↓
user requests via USB/UART (ASCII map, binary, temperature map)

BMP280 (SPI)
       ↓
Temperature, Pressure, Humidity, Dew point
       ↓
Heater logic (auto or setpoint) → PWM outputs

ADC (DMA + median filter)
       ↓
NTC temperatures, MCU temperature, Vdd
```

---

## MLX90640 Processing

### State Machine (`mlxproc.c`)

The firmware manages up to **5 sensors** (addresses 0x10..0x14 left-shifted for I²C). The state
machine cycles through:

1. **NOTINIT** – Read calibration parameters (832 words) from each sensor over I²C DMA.
2. **WAITPARAMS** – Wait for DMA completion, calculate parameters via `get_parameters()`.
3. **WAITSUBPAGE** – Poll `REG_STATUS` for `NEWDATA` flag, skip subpage 0.
4. **READSUBPAGE** – Read image data (832 words) via DMA, process with `process_image()`.

**Key features:**
- Automatic sensor exclusion after `MLX_MAX_ERRORS` (default 11) consecutive errors.
- `Tlastimage[]` timestamps for each sensor (used by "cartoon mode" and timeout recovery).
- Supports changing sensor I²C addresses at runtime (`mlx_sethwaddr()`).

### Temperature Calculation (`mlx90640.c`)

Implementation follows **Melexis MLX90640 Datasheet (Section 11)**:
- Supply voltage compensation (`kVdd`, `vdd25`)
- Ambient temperature (`KvPTAT`, `KtPTAT`, `vPTAT25`)
- Gain normalization
- Offset correction (per-pixel `offset[]`, `kta[]`, `kv[]`)
- TGC (temperature gradient compensation)
- Pixel sensitivity (`alpha[]`) + KsTa, KsTo, range detection (CT3, CT4)
- **Extended temperature range** (up to 400°C) via `alphacorr[]`

Output: **float array of 768 temperatures** (°C) per sensor.

---

## Environmental & Heater Control

### BMP280/BME280 Readings
- **Temperature** (°C)
- **Pressure** (Pa, also converted to hPa and mmHg)
- **Humidity** (%)
- **Dew point** (°C) – calculated via Magnus formula.

Measurements are triggered every `ENV_MEAS_PERIOD` (10 seconds) in forced mode.

### Heater Modes

| Mode | Activation | Behavior |
|---|---|---|
| **Auto** (`autoheater=1`) | Humidity > 90% | Sets holding temperature = ambient + dew_over_delta (7°C) + 0.5°C (min 5°C) |
| **Hold** (`setheater N`) | Manual command | Maintains N°C ±5°C hysteresis using PWM |
| **Off** | Default | All heaters disabled |

**PWM channels:**
- `ch0`, `ch1` – External heaters (controlled identically for symmetry)
- `ch2` – Proportional to ambient temperature: `(T_ambient + 20) × 2` %, clamped 0–100
- `ch3` – Proportional to `(35°C – T_ambient + T_sky) × 2.5` %, clamped 0–100

**Anti-overheating:** If any NTC exceeds setpoint by >5°C, PWM is reduced to `PWM_HOLD_VAL` (10%).

---

## Command Protocol

The device presents a **virtual COM port** (CDC) over USB and a second UART interface. Both share
the same command set.

### Command Syntax
```
<command> [parameter] [= value]
```
- Commands are **case-sensitive** (lowercase).
- Parameters are **decimal** (or hex with `0x`, binary with `b`).
- Use `help` for full list.
- Lines end with `\n` (newline).

### Core Commands

#### MLX90640 Image Commands

| Command | Description | Example |
|---|---|---|
| `ascii n` | Draw ASCII-art thermal map (16 grayscale levels) | `ascii 0` |
| `tempmap n` | Print numeric temperature grid (°C) | `tempmap 1` |
| `binary n` | Dump raw float array (768×4 bytes) | `binary 2` |
| `acqtime n` | Show last image acquisition timestamp (ms) | `acqtime 3` |
| `cartoon` | Toggle live ASCII animation over USB | `cartoon` |

#### Sensor Management

| Command | Description | Example |
|---|---|---|
| `listids` | List active I²C addresses of all sensors | `listids` |
| `mlxaddr n [= addr]` | Get/set I²C address for sensor n (0–4) | `mlxaddr 2 = 0x15` |
| `mlxdump n` | Dump all calibration parameters for sensor n | `mlxdump 0` |
| `state` | Show MLX90640 state machine status | `state` |
| `mlxpause` / `mlxcont` / `mlxstop` | Control acquisition | – |

#### Environment

| Command | Description | Example |
|---|---|---|
| `environ` | Print T, P, H, dew point, Tsky | `environ` |
| `bmereinit` | Reinitialize BMP280 | – |
| `ntc [n]` | Get NTC temperature (°C) for channel n (0–3) | `ntc 1` |

#### Heater Control

| Command | Description | Example |
|---|---|---|
| `autoheater [= 0/1]` | Enable/disable automatic dew avoidance | `autoheater = 1` |
| `setheater [= N]` | Set holding temperature (°C) | `setheater = 25` |
| `clearheater` | Disable holding, turn off heaters | – |
| `pwm [n] [= val]` | Get/set PWM duty cycle (0–100%) for channel n | `pwm 0 = 50` |

#### System & Debug

| Command | Description | Example |
|---|---|---|
| `adc [n]` | Get raw ADC value (0–4095) for channel n | `adc 4` |
| `dac [= val]` | Get/set DAC output (0–4095) | `dac = 2048` |
| `mcutemp` | Show MCU internal temperature (°C) | – |
| `mcuvdd` | Show Vdd (V) | – |
| `time` | Show SysTick counter (ms) | – |
| `reset` | Software reset | – |
| `sendstr = text` | Forward string to other interface | `sendstr = "hello"` |

#### Raw I²C (for debugging)

| Command | Description | Example |
|---|---|---|
| `iicscan` | Scan I²C bus, report found addresses | – |
| `iicaddr [= addr]` | Get/set current I²C target address (non-shifted) | `iicaddr = 0x33` |
| `iicspeed [= n]` | Set I²C speed: 0=10k,1=100k,2=400k,3=1M,4=2M | – |
| `readreg reg [= n]` | Read n 16-bit registers | `readreg 0x8000` |
| `writedata = v1 v2 ...` | Write 16-bit values | `writedata = 0x1234 0x5678` |
| `hwaddr addr` | Change hardware I²C address of MLX90640 (non-shifted) | `hwaddr 0x15` |

### Output Formats

#### ASCII Thermal Map (`ascii`)
```
RANGE=12.345
MIN=-5.67
MAX=6.78
 .':;+*oxX#&%B$@
 .':;+*oxX#&%B$@
 ...
```
Uses 16‑character grayscale ramp: space (coldest) → `@` (hottest).

#### Numeric Map (`tempmap`)
```
-2.3 1.2 3.4 ...
 5.6 7.8 9.0 ...
...
```

#### Binary Image (`binary n`)
```
BINARY0=<768×4 bytes raw float array>ENDIMAGE\n
```
Little-endian IEEE 754 `float` values. Exact size: 3072 bytes per image.

#### Environment Output
```
TEMPERATURE=22.34
SKYTEMPERATURE=-15.67
PRESSURE_HPA=1013.25
PRESSURE_MM=759.98
HUMIDITY=65.20
TEMP_DEW=15.60
T_MEASUREMENT=12345678
```

### Sensors location

| N | ID | Cardinal direction |
|---|---|---|
| 0 | 0x10 | Zenith |
| 1 | 0x11 | East |
| 2 | 0x12 | South |
| 3 | 0x13 | West |
| 4 | 0x14 | North |
---------------------------------

---

## Building & Flashing

### Prerequisites
- ARM GCC toolchain (`arm-none-eabi-gcc`)
- Make
- [st-flash](https://github.com/texane/stlink),
       [stm32flash](https://sourceforge.net/projects/stm32flash/) or
       [OpenOCD](https://openocd.sourceforge.io) (for flashing MCU)

### Build
```bash
git clone --depth=1 https://github.com/eddyem/stm32samples.git
cd stm32samples/F3:F303/MLX90640-allsky
make
```

### Configuration
- `EBUG` flag in Makefile enables debug output (slower, but verbose).
- `NOCAN` – define if CAN peripheral not used (increases USB buffer).
- `BUILD_NUMBER` and `BUILD_DATE` in `version.inc` are auto-generated.

### Flashing
```bash
make flash # for flashing over st-link
# make boot - for flashing over USART1 bootloader
# make dfuboot - for flashing over USB-DFU
```
or manually (over st-link):
```bash
openocd -f interface/stlink.cfg -f target/stm32f3x.cfg -c "program build/firmware.elf verify reset exit"
```

### udev Rule (Linux)
Create `/etc/udev/rules.d/99-USBiinterface.rules`:
```
ACTION=="add", ENV{USB_IDS}=="0483:5740", ATTRS{interface}=="?*", PROGRAM="/bin/bash -c \"ls /dev | grep $attr{interface} | wc -l \"", SYMLINK+="$attr{interface}%c", MODE="0666", GROUP="tty"
```
After replug, device appears as `/dev/ir-allsky0`.

---

## Calibration & Tuning

### NTC Thermistors
The firmware includes a **lookup table (LUT)** for NTC with B=3950, R25=1000Ω, covering -10..+59°C.
If a sensor reads `<5 ADC` → short circuit; `>4090 ADC` → open circuit.

To calibrate your NTCs, modify `Rlut[]` in `adc.c`.

### MLX90640
Calibration data is **per-sensor** and stored in EEPROM. The firmware reads it automatically on
startup.
No user calibration is required – the factory data is used.

### Vdd Measurement
Internal Vrefint (1.2V typical) and factory calibration value `*VREFINT_CAL_ADDR` are used:
```
Vdd = (VREFINT_CAL * 3.3) / ADC_VREF
```

### MCU Temperature
Internal sensor (ADC1_IN16) uses factory calibration `TEMP30_CAL_ADDR` and `TEMP110_CAL_ADDR`.

---

## Troubleshooting

### No USB device detected
- Check `USBPU_ON()` in `main.c` – some boards need pull-up control, others constant.
- Verify PA11/PA12 are configured as AF14.
- Try different USB cable / port.

### I²C communication errors
- Reduce speed: `iicspeed = 1` (100 kHz).
- Check pull-up resistors (2.2k–10kΩ on SCL/SDA).
- Use `iicscan` to verify sensor addresses.

### BMP280 not responding
- Check SPI wiring (PB3–PB5, PB9 CS).
- Try software reset: `bmereinit`.
- Verify chip ID: should be 0x58 (BMP280) or 0x60 (BME280).

### Heater not working
- Check `autoheater` status: `autoheater`.
- Verify NTC readings: `ntc`.
- For manual mode: `setheater = 25`, observe `pwm`.

### Cartoon mode stops updating
- Cartoon mode works **only over USB**, not UART.
- If no new images, check `state` – may be paused or in error.

### Watchdog resets
- IWDG period is 2 seconds. Long operations (e.g., full calibration dump) may trigger reset.  
- Disable in debug builds (remove `IWDG_REFRESH` calls or undefine `EBUG`).

---

## Performance & Limitations

| Parameter | Value |
|---|---|
| Image update rate (5 sensors) | ~1–2 Hz (depends on I²C speed) |
| RAM usage | ~39 kB (image buffers + parameters) |
| Flash usage | ~26 kB |
| Maximum sensors | 5 (limited by I²C address space 0x10–0x14) |
| Temperature range | -40..+300°C (MLX90640) |
| Accuracy | ±1°C (typical after calibration) |

---

## License

All source files are licensed under **GNU General Public License v3.0** unless stated otherwise.  
The BMP280 driver includes MIT-licensed code from sheinz (2016).

---

## Credits & References

- **Author:** Edward V. Emelianov <edward.emelianoff@gmail.com>
- **MLX90640 Datasheet:** Melexis (Document REV 10)
- **BMP280 Datasheet:** Bosch Sensortec
- **STM32F303 Reference Manual:** STMicroelectronics (RM0316)

For questions, bug reports, or contributions, please use the GitHub issue tracker.

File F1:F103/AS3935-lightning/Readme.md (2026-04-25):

# AS3935-based Lightning Detector

## Overview

This project implements a lightning detection system using two AS3935 Franklin Lightning Sensors interfaced
with an STM32F103 microcontroller. The device communicates over USB CDC (virtual serial port) and exposes a
text-based command protocol for configuration, monitoring, and data extraction.
In the next version it is possible to add RS-232 or RS-485 as an alternative to USB.

Key features:
- Dual AS3935 sensors on single SPI channel.
- On-chip ADC for internal MCU temperature and voltage supply monitoring (more features may be added in the
  future).
- Persistent configuration storage in internal Flash memory.
- USB CDC interface with automatic detection of lightning events.
- Extensive command set for real-time tuning and status readout.

---

## Hardware Connections

| Pin | Configuration | Function |
|---|---|---|
| PA0 | GPIO | INT0 - External interrupt from sensor 0 (pull-down) |
| PA1 | GPIO | INT1 - External interrupt from sensor 1 (pull-down) |
| PA2 | GPIO | CS0 - SPI chip select for sensor 0 |
| PA3 | GPIO | CS1 - SPI chip select for sensor 1 |
| PA5 | SPI1 SCK  | SPI clock |
| PA6 | SPI1 MISO | SPI Master In / Slave Out |
| PA7 | SPI1 MOSI | SPI Master Out / Slave In |
| PA9 | USART1 Tx | (unused in this version) |
| PA10 | USART1 Rx | (unused) |
| PA15 | GPIO | USB D+ pull-up control (1.5 kΩ) |
| PC13 | GPIO | On-board LED (active low) |

The two AS3935 sensors share the SPI bus but have separate chip select lines and interrupt pins.
If necessary, it can be expanded to include more sensors.

---

## USB CDC Communication

The device appears as a virtual COM port when connected to a host computer. Communication parameters (baud
rate, parity, etc.) are ignored — the underlying USB bulk transport guarantees reliable delivery.

- **Line coding**: default sent by host (e.g., 115200 8N1) is accepted but not used.
- **Ring buffers**: 1024 bytes each for TX and RX.
- **Command terminator**: every command must end with a newline (`\n`). The response is also terminated by a
  newline, except for multi-line outputs (help, dumpconf, SPI).

When the host opens the virtual COM port (DTR asserted), the device becomes ready. If the port is closed, the
`CDCready` flag is cleared and any outgoing data is discarded.

---

## Command Protocol

### General Syntax

```
<command> [<channel>] [ = <value> ]
```

- **command** — case-sensitive name (exactly as listed, all lowercase).
- **channel** — numeric index of the sensor (0 or 1). Required for sensor-specific commands; omitted for
global commands.
- **value** — decimal integer, hexadecimal (`0x` prefix), binary (`0b` prefix), or a string (for commands
like `setiface`). For the `SPI` command, the value is a sequence of hex bytes and/or quoted text.
- **whitespaces** around `=` and between tokens is ignored.

There are two modes:

1. **Getter** — if `=` is absent, the current value is returned:
   ```
   command<channel> = <current_value>
   ```
   No `OK` response follows.

2. **Command** — also don't need `=`, but returns `OK` or error code.

3. **Setter** — if `=` is present, the value after `=` is assigned. The returned value is text describing
   error code (`OK` etc.). A getter-style response is **not** returned after a successful set; only `OK`
   appears.

For channel-dependent commands the response includes the channel number, e.g.:
```
gain0 = 5
```

Global commands (no channel) use the same format without a number:
```
restonstart = 1
```

Commands that are purely actions (e.g., `clearstat`, `resetdef`) only take a channel number and do not accept
an `=` sign. On success they reply `OK`.

### Error Codes

If a command cannot be executed, one of the following error strings is returned instead of `OK`:

| Error String | Meaning |
|---|---|
| `BADCMD` | Unknown command |
| `BADPAR` | Invalid channel number |
| `BADVAL` | Invalid value for the setter (out of range or malformed) |
| `WRONGLEN` | Buffer overflow or line too long |
| `CANTRUN` | SPI communication failure, sensor not responding, or illegal state |
| `BUSY` | SPI or ring buffer busy - retry later |
| `OVERFLOW` | Input string exceeded maximum length (256 characters) |

### Command Reference

All commands are defined in the source file `commproto.cpp` using macro `COMMAND_TABLE`.

#### Sensor Configuration Commands

These commands read or write parameters of a specific AS3935 sensor. They require the channel number as the
first argument. For details, please refer to the sensor's technical documentation.

| Command | Description | Value Range | Default |
|---|---|---|---|
| `displco` | Display on IRQ pin: 0=nothing, 1=TRCO, 2=SRCO, 3=LCO | 0 - 3 | 0 |
| `gain` | Amplifier gain (AFE_GB) | 0 - 31 | 18 |
| `lco_fdiv` | Antenna LCO frequency divider | 0 - 3 | 0 |
| `maskdist` | Mask disturbers (1 = mask, 0 = allow) | 0 or 1 | 0 |
| `minnumlig`  | Minimum lightning number (0→1, 1→5, 2→9, 3→16) | 0 - 3 | 0 |
| `nflev` | Noise floor level | 0 - 7 | 2 |
| `srej` | Spike rejection | 0 - 15 | 2 |
| `tuncap` | Tune capacitor setting (n·8 pF) | 0 - 15 | 0 |
| `wdthres` | Watchdog threshold | 0 - 15 | 2 |

**Syntax examples:**

```
gain 0 = 12          set gain of sensor 0 to 12
gain 1               read gain of sensor 1 → gain1 = 5
displco 0 = 1        configure sensor 0 IRQ pin to output TRCO clock
displco 0            read display mode → displco0 = 1
```

#### Sensor Action & Status Commands

These commands do not take a value after `=`, only a channel number.

| Command | Description |
|---|---|
| `clearstat`  | Clear the lightning statistics (last 15 min) |
| `distance` | Read estimated distance to the lightning in km (0-63, 63=out of range) |
| `energy` | Read energy of the last lightning (24-bit value) |
| `intcode` | Read the last interrupt code: 1=Noise, 4=Disturber, 8=Lightning |
| `iscalib` | Check if both RCO and TRCO calibrations are done (returns 1 if done) |
| `resetdef` | Reset the sensor to factory default settings |
| `wakeup` | Wake up the sensor and run RCO calibration |

**Examples:**

```
wakeup 0            wake up sensor 0, auto-calibrate → OK
iscalib 0           read calibration status → iscalib0 = 1
energy 0            read energy → energy0 = 123456
distance 1          read distance → distance1 = 12
intcode 0           read interrupt flags → intcode0 = 8
clearstat 0         clear statistics → OK
resetdef 0          reset to defaults → OK
```

#### Global (Non-Sensor) Commands

These commands do not require a channel number.

| Command | Description |
|---|---|
| `dumpconf` | Dump the full current configuration (stored in RAM until saved) |
| `eraseflash` | Erase the entire Flash configuration storage |
| `help`  | Print list of all commands and a repository URL |
| `mcureset` | Software reset of the MCU |
| `mcutemp` | MCU internal temperature in tenths of °C (e.g., 287 = 28.7℃) |
| `readconf` | Read sensor configuration from the chip and update RAM for given channel |
| `restonstart` | Restore sensor parameters at start-up (0 or 1) |
| `saveconf` | Save the current RAM configuration to Flash |
| `setiface` | Get/set the USB interface name string (max 16 characters) |
| `time`  | Current uptime in milliseconds |
| `vdd` | Supply voltage VDD in hundredths of a volt (e.g., 330 = 3.30 V) |

**Examples:**

```
mcutemp               → mcutemp = 287
vdd                   → vdd = 330
setiface = MyDetector   set interface name to "MyDetector"
setiface              → setiface = MyDetector
restonstart = 1         enable automatic restore at power-up
saveconf                save current configuration to Flash
dumpconf                print all stored and current parameters
readconf 0              read sensor 0 parameters into RAM (for later save)
```

#### SPI Low-Level Command

The `SPI` command allows arbitrary bidirectional SPI transactions to a selected sensor.

**Syntax:**
```
SPI <channel> = <hexdata>
```

`<hexdata>` is a sequence of bytes expressed as space- or comma-separated hexadecimal numbers (without `0x`
prefix), optionally with quoted text strings. Anything inside double quotes is transmitted as raw ASCII.

**Example:**
```
SPI 0 = 00 01 "hello" 02
```
This sends the bytes `0x00, 0x01, 'h','e','l','l','o', 0x02` to sensor 0 and returns the received bytes as a
hex dump.

**Response format:**
```
SPI0 = 
00 01 68 65 6c 6c 6f 02
```

---

## Lightning Interrupts

The main loop continuously monitors the INT pins (PA0, PA1). When a rising edge is detected and the
corresponding `DISPLCO` setting is `0` (not used as clock output), the code reads the interrupt register:

- Disturber and noise events are reported as:

  ```
  INTERRUPT0=NOICE,DISTURBER
  ```
- A lightning event additionally triggers `lightning_info()`, which prints the energy and distance:

  ```
  INTERRUPT0=LIGHTNING
  energy0 = 123456
  distance0 = 12
  ```

If the pin is configured as a clock output (`displco` != 0), no interrupt processing occurs. You can mask
disturber interrupts by command `maskdist n = 0`, in this case only `NOICE` and `LIGHTNING` will be
monitored.

---

## Configuration Storage

User settings are stored in the internal Flash of the STM32F103. The Flash area reserved for configuration
starts at a fixed address (defined in the linker script) and has a limited capacity. The structure
`user_conf` contains:

- `userconf_sz` — magic cookie (size of the structure).
- `iInterface` + `iIlength` — USB interface name (stored as two bytes per character for Unicode).
- `spars[]` — per-sensor parameters (gain, WDTH, NF_LEV, SREJ, MIN_NUM_LIG, MASK_DIST, LCO_FDIV, TUN_CAP).
- `flags.restore` — if 1, all parameters are automatically applied after reset.

**Mechanism:**

- Each time `saveconf` is issued, a new copy of the configuration is appended to the Flash storage. A binary
  search at boot finds the last valid entry.
- If the storage becomes full, the next `saveconf` will first erase the entire storage and then write the
  current configuration.
- `eraseflash` erases the whole configuration area; `restonstart` controls whether the stored configuration
  is uploaded to sensors at start-up.

**Capacity:** 

Approximately `(FLASH_SIZE * 1024 - offset) / sizeof(user_conf)` configurations can be stored. For a typical
64 KB device, this is hundreds of entries.

---

## ADC and Internal Sensors

The STM32’s ADC continuously samples the internal temperature sensor (channel 16) and the internal reference
voltage (channel 17) in scan mode with DMA circular buffer. A median filter of 9 samples is applied to each
channel.

- **`mcutemp`** returns temperature in tenths of °C, computed as:  

  `T = 25 + (V_25 - Vsense)/Avg_Slope`, with `V_25=1.45 V` and `Avg_Slope=4.3 mV/°C`.
- **`vdd`** calculates the supply voltage using the internal 1.2 V reference:  

  `Vdd = 1.2 * 4096 / (ADC reading of Vrefint)`.

These commands do not require a sensor channel.

---

## Examples

### Typical Workflow

1. Connect the device to a USB port and open a terminal at any baud rate.
2. Type `help` to see the available commands.
3. Wake up the sensors and calibrate:

   ```
   wakeup 0
   wakeup 1
   ```
4. Configure gains, thresholds and other values if need:

   ```
   gain 0 = 10
   wdthres 1 = 3
   ```
5. Verify settings:

   ```
   dumpconf
   ```
6. Enable persistent configuration:

   ```
   restonstart = 1
   saveconf
   ```

7. Monitor lightning events — the device will print `INTERRUPT...` messages automatically. If need, you can
   clear statistics periodically or call other setters/getters; for example, reduce the sensitivity or
   lightning strike threshold during a severe thunderstorm and restore these values after it ends

### Reading Sensor Status
Any time you can read sensor status (to get noice information or other data):

```
intcode 0
energy 0
distance 0
```

### Saving and Restoring Configuration

```
dumpconf        # see current settings
saveconf        # write to flash
mcureset        # reboot (only if something goes wrong)
```

After reset, the configuration is automatically loaded (if `restonstart` was 1).

---

## How to distinguish between identical device

The device uses standard USB VID/PID, which are shared for free use by ST. Therefore, it may be difficult to
determine which `/dev/ttyACMx` this particular device corresponds to.

You can set custom interface name (`setiface=...`). After storing in flash, reconnect or reset device and
run `lsusb -v` for given device. At `iInterface` field you will see stored name. This field can be used to
create human-readable symlinks in `/dev`.

For automatical creation of symlink in `/dev` to your `/dev/ttyACMx`, add this udev-script to
`/etc/udev/rules.d/99-usbids.rules`

```
ACTION=="add", DRIVERS=="usb", ENV{USB_IDS}="%s{idVendor}:%s{idProduct}"
ACTION=="add", ENV{USB_IDS}=="0483:5740", ATTRS{interface}=="?*", PROGRAM="/bin/bash -c \"ls /dev | grep $attr{interface} | wc -l \"", SYMLINK+="$attr{interface}%c", MODE="0666", GROUP="tty"
```

---

## Build Information

Typing `help` you will see project repository URL, build number and build date at first string.

The code is distributed under GPLv3.

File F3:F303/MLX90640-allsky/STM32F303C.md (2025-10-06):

| Pin # | Pin name | function | settings | comment |
| --- | --- | --- | --- | --- |
| 1 | VBAT | | | |
| 2 | PC13 | | | |
| 3 | PC14 | | | |
| 4 | PC15 | | | |
| 5 | OCS_IN | | | |
| 6 | OSC_OUT | | | |
| 7 | NRST | | | |
| 8 | VSSA | | | |
| 9 | VDDA | | | |
| 10 | PA0 | ADC1 IN1 | AIN | Text1 |
| 11 | PA1 | ADC1 IN2 | AIN | Text2 |
| 12 | PA2 | | | |
| 13 | PA3 | | | |
| 14 | PA4 | DAC OUT1 | AIN | int. heater  |
| 15 | PA5 | ADC2 IN2 | AIN | DAC control  |
| 16 | PA6 | PWM1 /TIM3.1 | AF2 | ext. heater  |
| 17 | PA7 | PWM2 | AF2 | propto humid |
| 18 | PB0 | PWM3 | AF2 | propto Text  |
| 19 | PB1 | PWM4 /TIM3.4 | AF2 | propto tsky  |
| 20 | PB2 | SPI CS | PP | BME select |
| 21 | PB10 | | | |
| 22 | PB11 | | | |
| 23 | VSS1 | | | |
| 24 | VDD1 | | | |
| 25 | PB12 | | | |
| 26 | PB13 | | | |
| 27 | PB14 | | | |
| 28 | PB15 | | | |
| 29 | PA8 | | | |
| 30 | PA9 | USART1 TX | AF7 | USART for |
| 31 | PA10 | USART1 RX | AF7 | optical conn.|
| 32 | PA11 | USBDM | AF14 | |
| 33 | PA12 | USBDP | AF14 | |
| 34 | PA13 | SWDIO | AF0 | |
| 35 | VSS2 | | | |
| 36 | VDD2 | | | |
| 37 | PA14 | SWCLK | AF0 | |
| 38 | PA15 | USB PULLUP | PP | |
| 39 | PB3 | SPI SCK | AF5 | SPI for |
| 40 | PB4 | SPI MISO | AF5 | BME280 |
| 41 | PB5 | SPI MOSI | AF5 | sensor  |
| 42 | PB6 | I2C SCL | AF4 | I2C for |
| 43 | PB7 | I2C SDA | AF4 | MLX90640  |
| 44 | BOOT0 | | | |
| 45 | PB8 | | | |
| 46 | PB9 | | | |
| 47 | VSS3 | | | |
| 48 | VDD3 | | | |

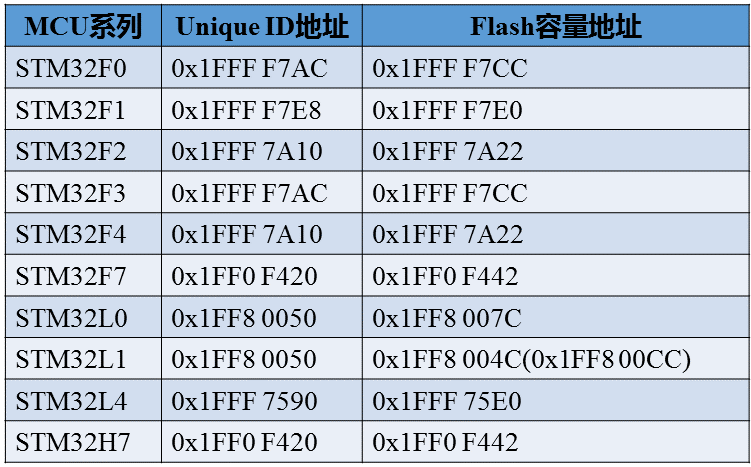
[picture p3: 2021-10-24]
stm32reg.png

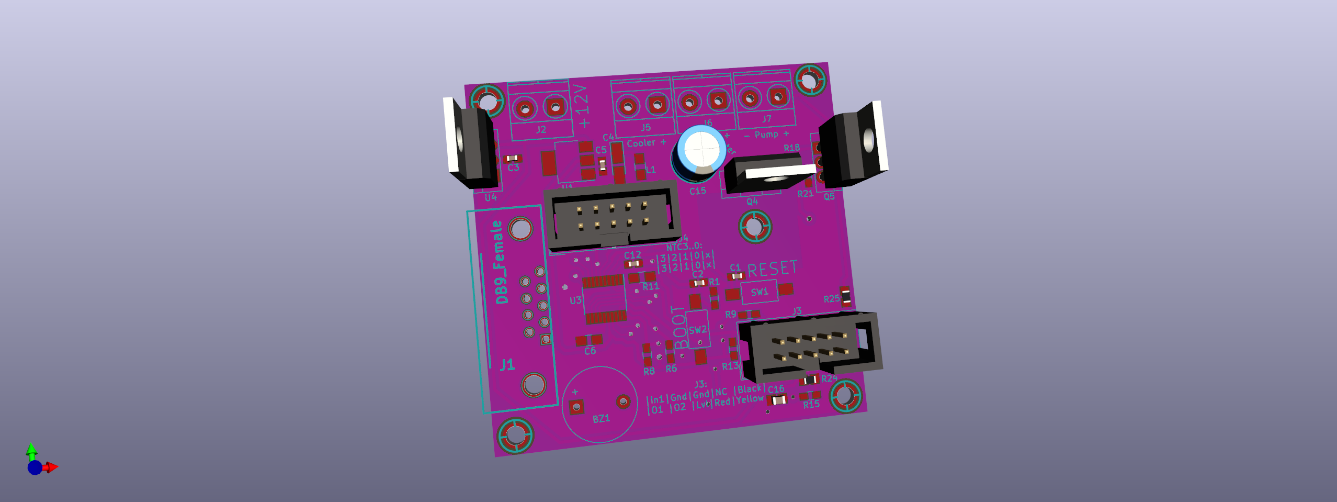
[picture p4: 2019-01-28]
F0:F030,F042,F072/Chiller/kicad/Chiller_controlf.png

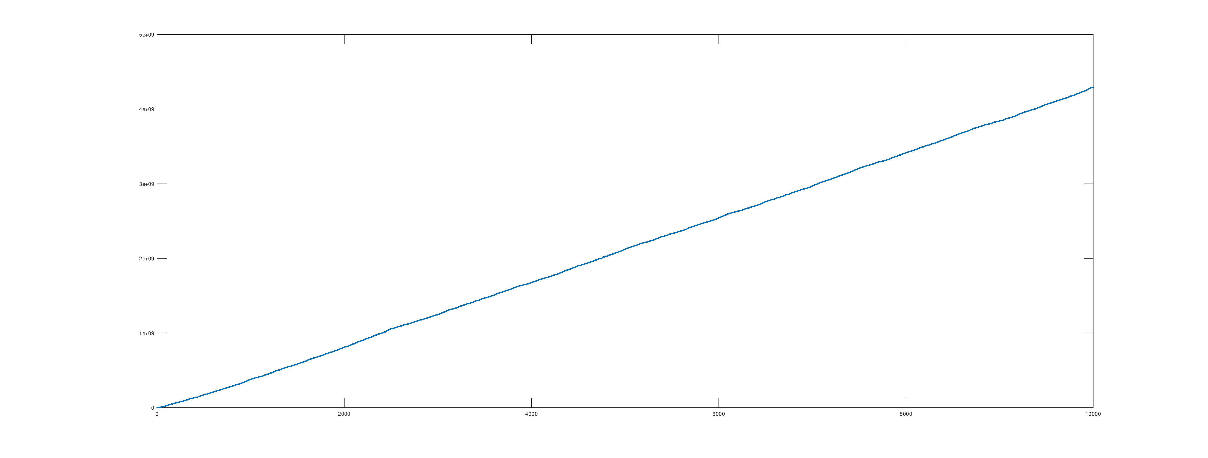
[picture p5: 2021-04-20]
F1:F103/RGB_LED_Screen/F.png

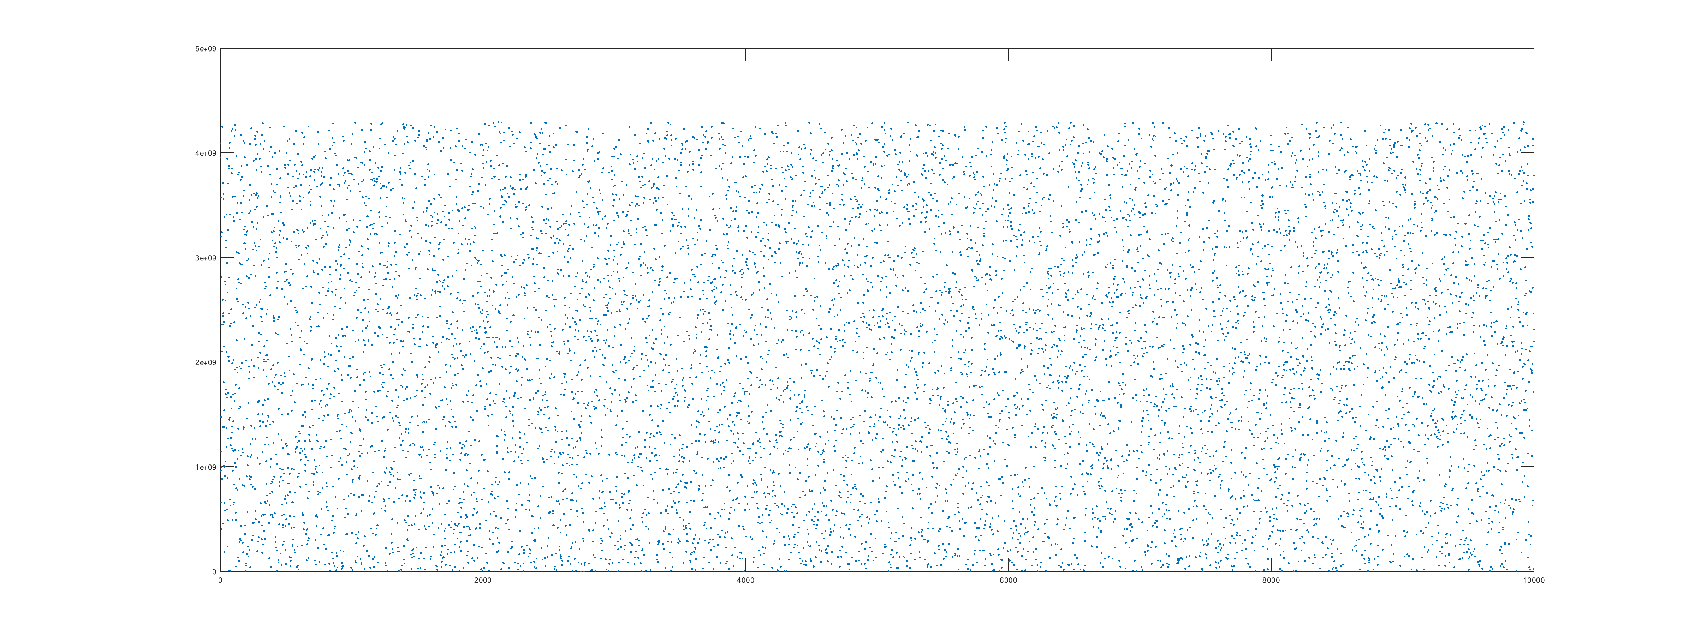
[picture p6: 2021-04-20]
F1:F103/RGB_LED_Screen/f.png

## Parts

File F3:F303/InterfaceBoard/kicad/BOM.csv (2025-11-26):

Reference | Value | Footprint | Qty | DNP
C1,C6,C8 | 0.47 | 0805 | 3
C2,C9,C14,C15 | 1u | 0805 | 4
C3,C4,C5,C7,C10,C11,C13,C16,C17,C18,C21,C22,C23,C24,C25,C26,C27,C28,C29,C30,C31,C32 | 0.1 | 0603 | 22
C12 | 22u | 0805 | 1
C19,C20 | 12 | 0306 | 2
D1 | PESD1CAN | SOT-23 | 1
D2,D3,D4,D5 | SMAJ15CA | SMA | 4
D6,D8,D10,D11,D12 | SM712_SOT23 | SOT-23 | 5
D7,D9 | 1N5817 | SMA/SMB | 2
F1,F2,F3,F4,F5,F6 | 0.5A | 1206 | 6
J6,J7,J8,J12,J13,J14 | Term_3 | 3x5mm | 6
J9 | Screw_Terminal_01x02 | 2x5mm | 1
J10 | SSI/422 | DSUB9 | 1
J11 | USB_B | USB B | 1
Q1 | AO3401 | SOT-23 | 1
Q2,Q3,Q5,Q6,Q7 | B0505S-1W |  | 5
Q4 | B0505S-2W |  | 1
R1 | 120 | 1210 | 1
R2,R3,R4,R5,R6,R7,R8,R9 | 510 | 0603 | 8
R10,R14,R16 | 10k | 0603 | 3
R11,R13,R15 | 22 | 0603 | 3
R12 | 1k5 | 0603 | 1
R17 | 330 | 0603 | 1
R18 | 1k | 0603 | 1
SW1 | SW_DIP_x01 |  | 1
SW2,SW3,SW4 | SW_Push |  | 3
U1 | ISO1050DUB | SOP8 | 1
U2 | MAX3232 | SOIC16W | 1
U3 | ISO3086 | SOIC16W | 1
U4 | LM1117MP-3.3 | SOT-223-3 | 1
U5 | USBLC6-2SC6 | SOT-23-6 | 1
U6 | STM32F303RBT6 | LQFP64 | 1
U7,U8,U9 | ISO3088DW | SOIC16W | 3
U10,U11,U12,U13 | H11L1 | DIP-6 | 4
Y1 | 8MHz | HC49-U | 1

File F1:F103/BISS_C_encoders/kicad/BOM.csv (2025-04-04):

Reference | Value | Datasheet | Footprint | Qty | DNP
C1,C2,C6,C7,C8,C9,C10,C11,C12,C15,C16,C20,C21 | 0.1 | ~ | Capacitor_SMD:C_0603_1608Metric_Pad1.08x0.95mm_HandSolder | 13
C3 | 22u | ~ | Capacitor_SMD:C_0805_2012Metric_Pad1.18x1.45mm_HandSolder | 1
C4,C5 | 12 | ~ | Capacitor_SMD:C_0603_1608Metric_Pad1.08x0.95mm_HandSolder | 2
C13,C14,C22,C23 | 1u | ~ | Capacitor_SMD:C_0805_2012Metric_Pad1.18x1.45mm_HandSolder | 4
C17,C18,C19 | 0.47 | ~ | Capacitor_SMD:C_0805_2012Metric_Pad1.18x1.45mm_HandSolder | 3
D1,D2,D7 | 1N5817 | ~ | Diode_SMD:D_SMA-SMB_Universal_Handsoldering | 3
D3,D4,D8,D9 | SM712_SOT23 | https://www.littelfuse.com/~/media/electronics/datasheets/tvs_diode_arrays/littelfuse_tvs_diode_array_sm712_datasheet.pdf.pdf | Package_TO_SOT_SMD:SOT-23 | 4
D5,D6 | SMAJ15CA | https://www.littelfuse.com/media?itemid=75e32973-b177-4ee3-a0ff-cedaf1abdb93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 | Diode_SMD:D_SMA | 2
F1,F2 | 0.5A | ~ | Fuse:Fuse_1206_3216Metric | 2
J1 | Screw_Terminal_01x02 | ~ | TerminalBlock_Phoenix:TerminalBlock_Phoenix_MKDS-1,5-2_1x02_P5.00mm_Horizontal | 1
J2 | USB_B | ~ | Connector_USB:USB_B_OST_USB-B1HSxx_Horizontal | 1
J5,J6,J7,J11 | HOLE | ~ | MountingHole:MountingHole_3.2mm_M3 | 4
J8,J10 | SSI/422 | ~ | my_footprints:DSUB-9_Female_Horizontal_P2.77x2.84mm_EdgePinOffset4.94mm_Housed_MountingHolesOffset7.48mm | 2
J9 | 4P4C | ~ | Connector_RJ:RJ9_Evercom_5301-440xxx_Horizontal | 1
Q1 | DTA114Y |  | Package_TO_SOT_SMD:SOT-323_SC-70_Handsoldering | 1
Q2,Q3 | B0505S-2W |  | my_footprints:B0505S-2W | 2
R1,R2,R3 | 22 | ~ | Resistor_SMD:R_0603_1608Metric_Pad0.98x0.95mm_HandSolder | 3
R4 | 1k5 | ~ | Resistor_SMD:R_0603_1608Metric_Pad0.98x0.95mm_HandSolder | 1
R5 | 1k | ~ | Resistor_SMD:R_0603_1608Metric_Pad0.98x0.95mm_HandSolder | 1
R6 | 10k | ~ | Resistor_SMD:R_0603_1608Metric_Pad0.98x0.95mm_HandSolder | 1
U1 | LM1117MP-3.3 | http://www.ti.com/lit/ds/symlink/lm1117.pdf | Package_TO_SOT_SMD:SOT-223-3_TabPin2 | 1
U2 | USBLC6-2SC6 | https://www.st.com/resource/en/datasheet/usblc6-2.pdf | Package_TO_SOT_SMD:SOT-23-6 | 1
U3 | STM32F103C8Tx | https://www.st.com/resource/en/datasheet/stm32f103c8.pdf | Package_QFP:LQFP-48_7x7mm_P0.5mm | 1
U4,U6 | ISO3086 |  | Package_SO:SOIC-16W_7.5x10.3mm_P1.27mm | 2
U5 | MAX3232 | https://datasheets.maximintegrated.com/en/ds/MAX3222-MAX3241.pdf | Package_SO:SOIC-16_3.9x9.9mm_P1.27mm | 1
Y1 | 8MHz | ~ | Crystal:Crystal_HC49-U_Vertical | 1

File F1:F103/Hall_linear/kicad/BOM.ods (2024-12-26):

Reference | Value | Footprint | Qty | DNP
C1,C2 | 6 | Capacitor_SMD:C_0603_1608Metric_Pad1.08x0.95mm_HandSolder | 2
C3 | 1u | Capacitor_SMD:C_0805_2012Metric_Pad1.18x1.45mm_HandSolder | 1
C4,C5,C6,C7,C8 | 0.1 | Capacitor_SMD:C_0603_1608Metric_Pad1.08x0.95mm_HandSolder | 5
C9 | 22u | Capacitor_SMD:C_1206_3216Metric_Pad1.33x1.80mm_HandSolder | 1
D1 | SS14 | Diode_SMD:D_SOD-323_HandSoldering | 1
D2 | PESD1CAN | Package_TO_SOT_SMD:SOT-23 | 1
D3 | SMAJ5.0A | Diode_SMD:D_SMA | 1
J6 | USB_C_Receptacle_USB2.0_16P | Connector_USB:USB_C_Receptacle_HRO_TYPE-C-31-M-12 | 1
Q1 | DTA114Y | Package_TO_SOT_SMD:SOT-323_SC-70_Handsoldering | 1
R1,R2,R3 | 10k | Resistor_SMD:R_0603_1608Metric_Pad0.98x0.95mm_HandSolder | 3
R4,R5 | 22 | Resistor_SMD:R_0603_1608Metric_Pad0.98x0.95mm_HandSolder | 2
R6 | 1k5 | Resistor_SMD:R_0603_1608Metric_Pad0.98x0.95mm_HandSolder | 1
R7 | 120 | Resistor_SMD:R_1210_3225Metric_Pad1.30x2.65mm_HandSolder | 1 | DNP
R8,R9,R10 | 4k7 | Resistor_SMD:R_0603_1608Metric_Pad0.98x0.95mm_HandSolder | 3
U1 | STM32F103C6Tx | Package_QFP:LQFP-48_7x7mm_P0.5mm | 1
U2 | LM1117-3.3 | Package_TO_SOT_SMD:SOT-223-3_TabPin2 | 1
U3 | USBLC6-2SC6 | Package_TO_SOT_SMD:SOT-23-6_Handsoldering | 1
U4 | MCP2551-I-SN | Package_SO:SOIC-8_3.9x4.9mm_P1.27mm | 1
Y1 | NX5032GA-8MHz | Crystal:Crystal_SMD_5032-2Pin_5.0x3.2mm | 1

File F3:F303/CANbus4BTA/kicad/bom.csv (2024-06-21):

Reference | Value | Qty | Footprint
BZ1 | Buzzer 3.3V | 1 | Buzzer_Beeper:Buzzer_12x9.5RM7.6
C1,C2,C4,C6,C7,C8,C11,C26,C27,C28,C30,C31,C32,C33,C34,C35,C37,C38,C39,C40,C43,C45 | 0.1 | 22 | Capacitor_SMD:C_0603_1608Metric_Pad1.08x0.95mm_HandSolder
C3,C5 | 12 | 2 | Capacitor_SMD:C_0603_1608Metric_Pad1.08x0.95mm_HandSolder
C9,C10,C17,C20,C23,C25,C41,C42,C44,C46 | 1u | 10 | Capacitor_SMD:C_0805_2012Metric_Pad1.18x1.45mm_HandSolder
C12 | 100u 35V | 1 | Capacitor_THT:CP_Radial_D8.0mm_P3.50mm
C13,C14,C15,C16,C18,C19,C21,C22 | 1n | 8 | Capacitor_SMD:C_0603_1608Metric_Pad1.08x0.95mm_HandSolder
C24 | 100u 16V | 1 | Capacitor_THT:CP_Radial_D8.0mm_P3.50mm
C29 | SE-5R5-D105VYV3C | 1 | Capacitor_THT:DX_5R5VxxxxU_D19.0mm_P5.00mm
C36 | 47u 6V | 1 | Capacitor_Tantalum_SMD:CP_EIA-3216-18_Kemet-A_Pad1.58x1.35mm_HandSolder
D1,D2,D3,D4,D5,D6,D7,D8 | LED SMD | 8 | LED_SMD:LED_0805_2012Metric_Pad1.15x1.40mm_HandSolder
D9 | SMBJ30A | 1 | Diode_SMD:D_SMB-SMC_Universal_Handsoldering
D10 | PESD1CAN | 1 | Package_TO_SOT_SMD:SOT-23
D11 | 1N5822 | 1 | Diode_THT:D_DO-201_P3.81mm_Vertical_AnodeUp
D12,D13 | B340A | 2 | Diode_SMD:D_SMA-SMB_Universal_Handsoldering
D14,D15,D17 | SM712_SOT23 | 3 | Package_TO_SOT_SMD:SOT-23
D16 | SS14 | 1 | Diode_SMD:D_SMA-SMB_Universal_Handsoldering
F1,F3,F4,F5 | 0.5A | 4 | Fuse:Fuse_1206_3216Metric
F2 | 5A | 1 | Fuse:Fuse_1206_3216Metric
J1 | Vin | 1 | TerminalBlock_Phoenix:TerminalBlock_Phoenix_MKDS-1,5-2_1x02_P5.00mm_Horizontal
J2 | EXT_IN | 1 | Connector_Phoenix_MC_HighVoltage:PhoenixContact_MC_1,5_10-GF-5.08_1x10_P5.08mm_Horizontal_ThreadedFlange
J3 | CAN | 1 | Connector_Dsub:DSUB-9_Female_Horizontal_P2.77x2.84mm_EdgePinOffset4.94mm_Housed_MountingHolesOffset7.48mm
J4 | Ain | 1 | TerminalBlock_Phoenix:TerminalBlock_Phoenix_MKDS-1,5-4_1x04_P5.00mm_Horizontal
J5 | USB_B | 1 | Connector_USB:USB_B_OST_USB-B1HSxx_Horizontal
J6 | Prog | 1 | Connector_PinSocket_1.27mm:PinSocket_1x06_P1.27mm_Vertical
J7 | SSI{slash}422 | 1 | Connector_Dsub:DSUB-9_Female_Horizontal_P2.77x2.84mm_EdgePinOffset4.94mm_Housed_MountingHolesOffset7.48mm
J8 | Relay | 1 | TerminalBlock_Phoenix:TerminalBlock_Phoenix_MKDS-1,5-3_1x03_P5.00mm_Horizontal
J9 | RS-485 | 1 | TerminalBlock_Phoenix:TerminalBlock_Phoenix_MKDS-1,5-3_1x03_P5.00mm_Horizontal
JP1,JP2,JP3,JP4,JP5,JP6,JP7,JP10,JP11 | SolderJumper_2_Open | 9 | Jumper:SolderJumper-2_P1.3mm_Open_TrianglePad1.0x1.5mm
JP8,JP9 | 3 | 2 | Jumper:SolderJumper-3_P2.0mm_Open_TrianglePad1.0x1.5mm
K1 | G5LE-1-5VDC | 1 | Relay_THT:Relay_SPDT_Omron-G5LE-1
L1 | 100u | 1 | Inductor_THT:L_Toroid_Horizontal_D6.5mm_P10.00mm_Diameter7-5mm_Amidon-T25
P1,P2,P3,P4,P5,P6 | Hole | 6 | my_footprints:Hole_3mm
Q1 | B0505S-1W | 1 | my_footprints:B0x0xS
Q2 | B0509S-1W | 1 | my_footprints:B0x0xS
Q3 | SI2308 | 1 | Package_TO_SOT_SMD:SOT-23_Handsoldering
Q4 | B2424S-2W | 1 | my_footprints:B0505S-2W
Q5 | B0505S-2W | 1 | my_footprints:B0505S-2W
Q6 | SI2300 | 1 | Package_TO_SOT_SMD:SOT-23_Handsoldering
R1,R41,R42,R43,R44,R47,R48,R53,R55,R58 | 10k | 10 | Resistor_SMD:R_0603_1608Metric_Pad0.98x0.95mm_HandSolder
R2,R12 | 4k7 | 2 | Resistor_SMD:R_0603_1608Metric_Pad0.98x0.95mm_HandSolder
R3,R4,R5,R6,R7,R8,R9,R10,R11,R56,R57 | 330 | 11 | Resistor_SMD:R_0603_1608Metric_Pad0.98x0.95mm_HandSolder
R13,R14,R15,R16,R17,R18,R19,R20 | 3k3 | 8 | Resistor_SMD:R_2010_5025Metric_Pad1.40x2.65mm_HandSolder
R21,R22,R24,R25,R26,R27,R28,R29 | 560 | 8 | Resistor_SMD:R_0603_1608Metric_Pad0.98x0.95mm_HandSolder
R23 | 120 | 1 | Resistor_SMD:R_1210_3225Metric_Pad1.30x2.65mm_HandSolder
R30 | 1k5 | 1 | Resistor_SMD:R_0603_1608Metric_Pad0.98x0.95mm_HandSolder
R31,R32,R45,R46,R54 | 22 | 5 | Resistor_SMD:R_0603_1608Metric_Pad0.98x0.95mm_HandSolder
R33 | 10M | 1 | Resistor_SMD:R_0603_1608Metric_Pad0.98x0.95mm_HandSolder
R34,R35,R36,R37,R38,R39 | 7.5 | 6 | Resistor_SMD:R_2010_5025Metric_Pad1.40x2.65mm_HandSolder
R40 | 91k | 1 | Resistor_SMD:R_0603_1608Metric_Pad0.98x0.95mm_HandSolder
R49,R50,R51,R52 | 110 | 4 | Resistor_SMD:R_0603_1608Metric_Pad0.98x0.95mm_HandSolder
RV1,RV2,RV3 | 50k | 3 | Potentiometer_THT:Potentiometer_Bourns_3296W_Vertical
SW1 | SW_DIP_x01 | 1 | Button_Switch_THT:SW_DIP_SPSTx01_Slide_6.7x4.1mm_W7.62mm_P2.54mm_LowProfile
SW2 | SW_DIP_x04 | 1 | Button_Switch_THT:SW_DIP_SPSTx04_Slide_9.78x12.34mm_W7.62mm_P2.54mm
SW3,SW4,SW5 | SW_Push | 3 | Button_Switch_SMD:SW_SPST_FSMSM
TP1,TP2,TP3 | Gnd | 3 | Connector_PinSocket_2.54mm:PinSocket_1x01_P2.54mm_Vertical
TP4 | 24V | 1 | Connector_PinSocket_2.54mm:PinSocket_1x01_P2.54mm_Vertical
TP5 | 5V | 1 | Connector_PinSocket_2.54mm:PinSocket_1x01_P2.54mm_Vertical
TP6 | 4.6V | 1 | Connector_PinSocket_2.54mm:PinSocket_1x01_P2.54mm_Vertical
TP7 | 3.3V | 1 | Connector_PinSocket_2.54mm:PinSocket_1x01_P2.54mm_Vertical
U1 | BME280 | 1 | Package_LGA:Bosch_LGA-8_2.5x2.5mm_P0.65mm_ClockwisePinNumbering
U2 | STM32F303CBT6 | 1 | Package_QFP:LQFP-48_7x7mm_P0.5mm
U3 | ISO1050DUB | 1 | Package_SO:SOP-8_6.62x9.15mm_P2.54mm
U4,U5 | 74HC4051 | 2 | Package_SO:SOIC-16_3.9x9.9mm_P1.27mm
U6,U7 | PC844 | 2 | Package_DIP:DIP-16_W7.62mm
U8 | LM2576HVS-5 | 1 | Package_TO_SOT_SMD:TO-263-5_TabPin3
U9 | ADUM4160 | 1 | Package_SO:SOIC-16W_7.5x10.3mm_P1.27mm
U10 | USBLC6-2SC6 | 1 | Package_TO_SOT_SMD:SOT-23-6
U11 | LM1117MP-3.3 | 1 | Package_TO_SOT_SMD:SOT-223-3_TabPin2
U12 | IP4220CZ6 | 1 | Package_TO_SOT_SMD:SOT-23-6
U13 | ISO3086 | 1 | Package_SO:SOIC-16W_7.5x10.3mm_P1.27mm
U14 | ISO3088DW | 1 | Package_SO:SOIC-16W_7.5x10.3mm_P1.27mm
Y1 | 8MHz | 1 | Crystal:Crystal_HC49-U_Vertical

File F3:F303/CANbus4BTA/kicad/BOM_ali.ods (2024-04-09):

 |  |  | aliexpress |  | radiotech / chipdip
# | Component | Qty | link | price | link | price | total ali | total rt | total
1 | Active buzzer 3.3V, 12x9.5mm | 20 | https://aliexpress.ru/item/1005002074733370.html | 9.7 |  |  | 194 | 0 | 194
2 | Cap 0603, 12pF, 25V | 100 | https://aliexpress.ru/item/1005005778687163.html | 2 |  |  | 200 | 0 | 200
3 | Cap 0805, 1uF, 25V | 300 | https://aliexpress.ru/item/1005002976625533.html | 4 | https://www.rct.ru/catalog/mlcc-chip-capacitors/0805b105k250nt.html | 1 | 1200 | 300 | 300
4 | Cap 0805, 2.2uF, 50V | 200 | https://aliexpress.ru/item/1005006730909827.html | 3.5 | https://www.rct.ru/warehouse/80003379/10-00025861.html | 3.5 | 700 | 700 | 700
5 | Cap 0805, 10uF, 50V | 100 | https://aliexpress.ru/item/1005006730909827.html | 3.8 |  |  | 380 | 0 | 380
6 | Cap 0805, 22uF, 50V | 100 | https://aliexpress.ru/item/1005006730909827.html | 6.8 |  |  | 680 | 0 | 680
7 | low ESR cap 8x3.5mm, 100uF, 35V | 300 | https://aliexpress.ru/item/33049456328.html | 5 | https://www.rct.ru/warehouse/420/UT-00132642.html | 1.65 | 1500 | 495 | 495
8 | Cap 0603 1nF, 50V | 300 | https://aliexpress.ru/item/1005003278973028.html | 1 | https://www.rct.ru/warehouse/80003378/UT-00117266.html | 0.47 | 300 | 141 | 141
9 | SE-5R5-D105VYV3C — supercap 1F, 5mm | 10 | https://aliexpress.ru/item/1005005780693654.html | 140 | https://www.chipdip.ru/product0/8024376915 | 65 | 1400 | 650 | 650
10 | tantalum cap 3216 (A), 47uF, 6V | 20 | https://aliexpress.ru/item/1005006079491879.html | 27 | https://www.rct.ru/warehouse/other/5307964.html | 12.15 | 540 | 243 | 243
11 | MM3Z7V5, SOD323 (0805) | 100 | https://aliexpress.ru/item/1005005046477037.html | 3 | https://www.rct.ru/warehouse/80001484/UT-00123378.html | 6.34 | 300 | 634 | 300
12 | MM3Z12, SOD323 (0805) | 100 | https://aliexpress.ru/item/1005005046477037.html | 3 |  |  | 300 | 0 | 300
13 | PESD1CAN, SOT-23 | 50 | https://aliexpress.ru/item/1005005593134698.html | 13.3 | https://www.rct.ru/warehouse/other/5557878.html | 2.87 | 665 | 143.5 | 143.5
14 | 1N5822, DO-201 | 40 | https://aliexpress.ru/item/1005004605507231.html | 3.3 | https://www.rct.ru/warehouse/80000259/10080061914.html | 8.11 | 132 | 324.4 | 132
15 | B340A, SMA | 50 | https://aliexpress.ru/item/32458434919.html | 3 | https://www.rct.ru/warehouse/80000259/UT-00099906.html | 3.78 | 150 | 189 | 150
16 | USBLC6-2SC6, SOT23-6 | 50 | https://aliexpress.ru/item/4001170272668.html | 12 | https://www.rct.ru/warehouse/other/3934950.html | 3.96 | 600 | 198 | 198
17 | SM712.TCT, TVS diode, SOT-23 | 50 | https://aliexpress.ru/item/1005006221595871.html | 4 | https://www.rct.ru/warehouse/80001633/UT-00092495.html | 7.35 | 200 | 367.5 | 200
18 | SS14 (1N5819), shottky, SMA | 300 | https://aliexpress.ru/item/32871123427.html | 1.1 | https://www.rct.ru/warehouse/80000259/10080015992.html | 1.38 | 330 | 414 | 330
19 | BAT54S, SOT-23 | 100 | https://aliexpress.ru/item/1005002921256318.html | 1.2 | https://www.rct.ru/warehouse/3802/10080026093.html | 1.1 | 120 | 110 | 110
20 | One-time fuse 1206, 25V, 0.5A | 50 | https://aliexpress.ru/item/32901034711.html | 5.8 | https://www.chipdip.ru/product0/8029212925 | 12 | 290 | 600 | 290
21 | One-time fuse 1206, 32V, 5.0A | 20 | https://aliexpress.ru/item/32901034711.html | 5.3 | https://www.rct.ru/warehouse/543/10080064358.html | 5.11 | 106 | 102.2 | 102.2
22 | 15EDGK-5.08- 10P-14-00A(H) | 20 | https://aliexpress.ru/item/1005005511990041.html | 60 | https://www.chipdip.ru/product0/8681716822 | 89 | 1200 | 1780 | 1200
23 | 15EDGRC-5.08- 10P-14-00A(H) | 20 | https://aliexpress.ru/item/1005005511990041.html | 40 | https://www.chipdip.ru/product0/8309636445 | 41 | 800 | 820 | 800
24 | DSUB-9 female, PCB mount (DB9F) | 20 | https://aliexpress.ru/item/33032596922.html | 36 |  |  | 720 | 0 | 720
25 | USB B PCB mount, horizontal (L-KLS1-151-W) | 20 | https://aliexpress.ru/item/32849078009.html | 11 | https://www.rct.ru/warehouse/13451/10080035181.html | 12.5 | 220 | 250 | 220
26 | Terminal block 1x3 pin, p5.0mm (KF301-5.0-3P) | 30 | https://aliexpress.ru/item/1005001341408014.html | 7.5 |  |  | 225 | 0 | 225
27 | Relay SRD-05VDC-SL-C (G5LE-1-5VDC) | 10 | https://aliexpress.ru/item/10000275815686.html | 34 | https://www.rct.ru/warehouse/other/1288595.html | 54 | 340 | 540 | 340
28 | Toroid inductor 100uH, 3A, P10mm | 20 | https://aliexpress.ru/item/32953988879.html | 28 |  |  | 560 | 0 | 560
29 | DC-DC B0505S-1W | 30 | https://aliexpress.ru/item/1005005001758822.html | 63 | https://www.rct.ru/warehouse/other/3975058.html | 59 | 1890 | 1770 | 1770
30 | DC-DC B0509S-1W | 20 | https://aliexpress.ru/item/1005006021019783.html | 123 | https://www.rct.ru/warehouse/other/3151548.html | 142 | 2460 | 2840 | 2460
31 | DC-DC B0505S-2W | 10 | https://aliexpress.ru/item/1005006021019783.html | 123 | https://www.rct.ru/warehouse/other/3980204.html | 226 | 1230 | 2260 | 1230
32 | DC-DC B2424S-2W | 10 | https://aliexpress.ru/item/4000874620107.html | 148 | https://www.rct.ru/warehouse/other/3935778.html | 237 | 1480 | 2370 | 1480
33 | SI2308, SOT-23 | 300 | https://aliexpress.ru/item/1005006263648705.html | 2.7 | https://www.rct.ru/warehouse/other/5026418.html | 3.9 | 810 | 1170 | 810
34 | IRF9310, SO-8 | 30 | https://aliexpress.ru/item/4000048623497.html | 12.6 | https://www.rct.ru/warehouse/other/5377975.html | 26.52 | 378 | 795.6 | 378
35 | AO3402, SOT-23 | 100 | https://aliexpress.ru/item/1005006751662807.html | 1.2 | https://www.rct.ru/warehouse/other/5029634.html | 2.56 | 120 | 256 | 120
36 | AO3407, SOT-23 | 100 | https://aliexpress.ru/item/1005006751662807.html | 1.35 | https://www.rct.ru/warehouse/other/3929524.html | 3.45 | 135 | 345 | 135
37 | SMD resistor 0603, 10k, 5%, 50V | 500 | https://aliexpress.ru/item/32864336129.html | 0.4 | https://www.rct.ru/warehouse/other/562124.html | 0.083 | 200 | 41.5 | 41.5
38 | SMD resistor 0603, 4k7, 5%, 50V | 200 | https://aliexpress.ru/item/32864336129.html | 0.4 | https://www.rct.ru/warehouse/other/540975.html | 0.089 | 80 | 17.8 | 17.8
39 | SMD resistor 0603, 330R, 5%, 50V | 300 | https://aliexpress.ru/item/32864336129.html | 0.4 | https://www.rct.ru/warehouse/other/572977.html | 0.082 | 120 | 24.6 | 24.6
40 | SMD resistor 2010, 3k3, 5%, 50V | 300 | https://aliexpress.ru/item/1005001809043834.html | 1.5 | https://www.rct.ru/catalog/chip-resistor/2010-----3.3--kom--5-rc2010jk-073k3l-cr-0ajl4-3k3.html | 1.18 | 450 | 354 | 354
41 | SMD resistor 0603, 560R, 5%, 50V | 200 | https://aliexpress.ru/item/32864336129.html | 0.4 | https://www.rct.ru/catalog/chip-resistor/0603------560--om--5-rc0603jr-07560rl-cr-03jl7-560r-1.html | 0.096 | 80 | 19.2 | 19.2
42 | SMD resistor 1210, 120R, 5%, 50V | 100 | https://aliexpress.ru/item/1005004613228739.html | 1.1 | https://www.rct.ru/catalog/chip-resistor/1210------120--om--5-rc1210jr-07120rl-cr-10jl7-120r.html | 0.66 | 110 | 66 | 66
43 | SMD resistor 0603, 1k5, 5%, 50V | 100 | https://aliexpress.ru/item/32864336129.html | 0.4 | https://www.rct.ru/catalog/chip-resistor/0603-----1.5--kom--5-rc0603jr-071k5l-cr-03jl7-1k5.html | 0.096 | 40 | 9.6 | 9.6
44 | SMD resistor 0603, 22R, 5%, 50V | 300 | https://aliexpress.ru/item/32864336129.html | 0.4 | https://www.rct.ru/catalog/chip-resistor/0603--------22--om--1-rc0603fr-0722rl-cr-03fl7-22r.html | 0.073 | 120 | 21.9 | 21.9
45 | SMD resistor 0603, 10M, 5%, 50V | 100 | https://aliexpress.ru/item/32864336129.html | 0.4 | https://www.rct.ru/warehouse/80003231/10-00062364.html | 0.17 | 40 | 17 | 17
46 | SMD resistor 2010, 7.5R, 5%, 50V | 200 | https://aliexpress.ru/item/1005001809043834.html | 1.5 |  |  | 300 | 14.6 | 14.6
47 | SMD resistor 0603, 91k, 5%, 50V | 100 | https://aliexpress.ru/item/32864336129.html | 0.4 | https://www.rct.ru/warehouse/other/871516.html | 0.073 | 40 | 7.3 | 7.3
48 | SMD resistor 2512, 1k, 5%, 50V | 200 | https://aliexpress.ru/item/1005003411200420.html | 3.7 | https://www.rct.ru/catalog/chip-resistor/2512-----1--kom--5-rc2512jk-071kl-cr-12jl4-1k.html | 1.78 | 740 | 356 | 356
49 | SMD resistor 0603, 110R, 5%, 50V | 200 | https://aliexpress.ru/item/32864336129.html | 0.4 | https://www.rct.ru/catalog/chip-resistor/0603------110--om--5-rc0603jr-07110rl.html | 0.096 | 80 | 19.2 | 19.2
50 | 3296W Potentiometer, 50k | 30 | https://aliexpress.ru/item/32918175309.html | 10.6 | https://www.rct.ru/warehouse/17026/10080040592.html | 20.79 | 318 | 623.7 | 318
51 | Dip switch, 1way, 2.54mm | 20 | https://aliexpress.ru/item/4001079900061.html | 6.1 | https://www.rct.ru/warehouse/18109/10080052356.html | 18.53 | 122 | 370.6 | 122
52 | Dip switch, 4 way, 2.54mm | 20 | https://aliexpress.ru/item/4001079900061.html | 8.5 | https://www.rct.ru/warehouse/18109/10000006219.html | 27.4 | 170 | 548 | 170
53 | SMD tactile push button, 3x6x2.5mm | 50 | https://aliexpress.ru/item/32804523270.html | 1.4 |  |  | 70 | 0 | 70
54 | BME280 sensor, LGA-8 | 20 | https://aliexpress.ru/item/4001044028310.html | 222 | https://www.rct.ru/warehouse/19346/10-00002449.html | 346.93 | 4440 | 6938.6 | 4440
55 | STM32F303CBT6, LQFP-48 | 20 | https://aliexpress.ru/item/1005005047784788.html | 150 | https://www.rct.ru/warehouse/440/UT-00096122.html | 290 | 3000 | 5800 | 3000
56 | STM32F103C6T6, LQFP-48 | 60 | https://aliexpress.ru/item/1005002330869534.html | 35 |  |  | 2100 | 0 | 2100
57 | ISO1050DUB, SOP8 | 30 | https://aliexpress.ru/item/32848193054.html | 79.3 | https://www.rct.ru/warehouse/440/10080046664.html | 115.13 | 2379 | 3453.9 | 2379
58 | 74HC4051, SOIC16 | 40 | https://aliexpress.ru/item/1005002739051899.html | 15 | https://www.rct.ru/warehouse/146/10000016556.html | 15.12 | 600 | 604.8 | 600
59 | PC844, DIP16 | 20 | https://aliexpress.ru/item/1005001916418172.html | 38 |  |  | 760 | 0 | 760
60 | PC814, DIP4 | 100 | https://aliexpress.ru/item/1005002673533425.html | 17 | https://www.rct.ru/warehouse/other/249206.html | 43.64 | 1700 | 4364 | 1700
61 | LM2576S-5.0, TO263-5 | 20 | https://aliexpress.ru/item/1005006038765648.html | 28 | https://www.rct.ru/warehouse/other/3927462.html | 49.63 | 560 | 992.6 | 560
62 | DC-DC RT7272BGSP, SOP-8 | 30 | https://aliexpress.ru/item/4000531788253.html | 66 | https://www.rct.ru/warehouse/other/2274663.html | 44.33 | 1980 | 1329.9 | 1329.9
63 | DC-DC RT6365GSP, SOP-8 | 30 | https://aliexpress.ru/item/1005005676463785.html | 165 | https://www.rct.ru/warehouse/440/UT-00098769.html | 94.97 | 4950 | 2849.1 | 2849.1
64 | Schottky 30BQ040, SMC | 50 | https://aliexpress.ru/item/1005001576308934.html | 14.5 | https://www.rct.ru/warehouse/22483/UT-00129345.html | 12.4 | 725 | 620 | 620
65 | KLS18-PK0810-100M, inductance 10uH | 20 | https://aliexpress.ru/item/1005001612602098.html | 25 | https://www.rct.ru/warehouse/80027913/10080061770.html | 16.13 | 500 | 322.6 | 322.6
66 | SDB0650MT6R8, inductance 6.8uH | 20 | https://aliexpress.ru/item/1005001612602098.html | 25 | https://www.rct.ru/warehouse/80017388/10080071648.html | 26.6 | 500 | 532 | 500
67 | SMBJ30A, TVS diode | 50 | https://aliexpress.ru/item/1005002939861162.html | 3.2 | https://www.rct.ru/warehouse/80001633/UT-00092074.html | 7.2 | 160 | 360 | 160
68 | ADUM4160, SOIC16W | 10 | https://aliexpress.ru/item/1005006181491548.html | 398 | https://www.rct.ru/warehouse/4730/10080035337.html | 806 | 3980 | 8060 | 3980
69 | LM1117-3.3 / AMS1117-3.3, SOT223 | 50 | https://aliexpress.ru/item/1005004111459004.html | 8.5 | https://www.rct.ru/warehouse/other/3683885.html | 11.8 | 425 | 590 | 425
70 | IP4220CZ6, SOT23-6 | 20 | https://aliexpress.ru/item/1005003775341610.html | 7.3 | https://www.rct.ru/warehouse/other/3970752.html | 4.1 | 146 | 82 | 82
71 | SMF05CT1G, SOT-363 | 100 | https://aliexpress.ru/item/1005003943585730.html | 5.6 | https://www.rct.ru/warehouse/other/5501592.html | 4.12 | 560 | 412 | 412
72 | ISO3086, SOIC16W | 10 | https://aliexpress.ru/item/1005004326567565.html | 268 | https://www.rct.ru/warehouse/440/10080059358.html | 362 | 2680 | 3620 | 2680
73 | ISO3088DW, SOIC16W | 10 | https://aliexpress.ru/item/1005004326567565.html | 310 |  |  | 3100 | 0 | 3100
74 | Quarz 8MHz, HC49-U | 50 | https://aliexpress.ru/item/1005003568861015.html | 8.4 | https://www.rct.ru/warehouse/80013515/10-00010933.html | 9.8 | 420 | 490 | 420
 |  |  |  |  |  |  |  |  | 52755

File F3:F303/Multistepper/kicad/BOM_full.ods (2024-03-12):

Item | Qty | Reference(s) | Value | Footprint
1 | 2 | C1, C4 | 6 | C_0603
2 | 12 | C2, C3, C5, C6, C7, C8, C9, C13, C15, C18, C27, C29 | 0.1 | C_0603
3 | 3 | C10, C11, C12 | 1u | C_0603
4 | 1 | C14 | 47u 35V | CP_EIA-6032
5 | 2 | C16, C28 | 47u 6V | CP_EIA-3216
6 | 1 | C17 | 47u 10V | CP_EIA-6032
7 | 8 | C19, C20, C21, C22, C23, C24, C25, C26 | 100u 35V | CP_Radial_D8.0mm_P3.50mm
8 | 8 | D1, D2, D3, D4, D5, D6, D7, D8 | SP0505BAHT | SOT-23-6
9 | 14 | D9, D10, D11, D12, D13, D14, D15, D16, D17, D18, D19, D20, D21, D23 | SS14 | SOD-323
10 | 2 | D22, D27 | MBRS130L | SMB
11 | 1 | D24 | PESD1CAN | SOT-23
12 | 1 | D25 | MM3Z7V5 | D_0805
13 | 1 | D26 | 1N5822 | DO-201
14 | 2 | J2, J3 | Buttons/I2C, Screen | IDC-Header_2x05_P2.54mm_Vertical
15 | 3 | J4, J5, J7 | ADC1, ADC2, GPIO | JST_PH_B4B-PH-K_1x04_P2.00mm_Vertical
16 | 1 | J6 | MOT_MUL | JST_PH_B5B-PH-K_1x05_P2.00mm_Vertical
17 | 1 | J8 | USB_B | USB_B_OST_USB-B1HSxx_Horizontal
18 | 1 | J9 | Screw_Terminal_01x03 | MKDS-1,5-3_1x03_P5.00mm_Horizontal
19 | 1 | J10 | Screw_Terminal_01x02 | MKDS-1,5-2_1x02_P5.00mm_Horizontal
20 | 8 | J12, J15, J17, J19, J21, J23, J25, J27 | Stepper | JST_EH_B4B-EH-A_1x04_P2.50mm_Vertical
21 | 8 | J11, J14, J16, J18, J20, J22, J24, J26 | LimS | JST_PH_B4B-PH-K_1x04_P2.00mm_Vertical
22 | 1 | J13 | UART | JST_PH_B3B-PH-K_1x03_P2.00mm_Vertical
23 | 1 | L1 | 100u | Toroid, 1.5A
24 | 1 | Q1 | B0505S-1W
25 | 1 | Q2 | IRF9310 | SO-8_3.9x4.9mm_P1.27mm
26 | 1 | Q3 | AO3401 | SOT-23
27 | 3 | R1, R11, R35 | 10k | R_0603
28 | 6 | R2, R9, R16, R17, R24, R25 | 22 | R_0603
29 | 3 | R3, R4, R34 | 7.5 | R_0603
30 | 1 | R5 | 5.1 | R_0603
31 | 6 | R6, R7, R8, R14, R15, R36 | 330 | R_0603
32 | 1 | R10 | 91k | R_0603
33 | 2 | R12, R13 | 47k | R_0603
34 | 1 | R18 | 120 | R_1210
35 | 2 | R19, R20 | 4k7 | R_0603
36 | 10 | R21, R22, R23, R26, R27, R28, R29, R30, R31, R32 | 100 | R_0603
37 | 1 | R33 | 1k5 | R_0603
38 | 2 | R37, R38 | 1k5 | R_0603
39 | 15 | RN1, RN2, RN3, RN4, RN5, RN6, RN7, RN8, RN9, RN10, RN11, RN12, RN13, RN14, RN15 | 330 | R_Array_Convex_4x0603
40 | 2 | SW1, SW2 | Reset, Boot | SW_SPST_FSMSM
41 | 1 | SW3 | SW_DIP_x01 | SW_DIP_SPSTx01
42 | 1 | U1 | STM32F303VDTx | LQFP-100
43 | 1 | U2 | ISO1050DUB | SOP-8_6.62x9.15mm_P2.54mm
44 | 1 | U3 | USBLC6-2SC6 | SOT-23-6
45 | 1 | U4 | LM4050A(b)EX3-3.3 | SOT-323
46 | 1 | U5 | LM2576-5.0 | TO-220-5
47 | 2 | U6, U8 | LM1117-3.3 | SOT-223-3
48 | 1 | U7 | 74HC4051 | SOIC-16_3.9x9.9mm_P1.27mm
49 | 1 | Y1 | NX5032GA-8MHz | Crystal_SMD_5032-2Pin_5.0x3.2mm
50 | 8 | X1-X8 | Pin header F 1x02 | Female pin header pitch 2.54mm, 1x2 pins
51 | 16 | X1-X8 | Pin header F 1x08 | Female pin header pitch 2.54mm, 1x8 pins

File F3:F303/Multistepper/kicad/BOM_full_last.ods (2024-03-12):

Item | Qty | Reference(s) | Value | Footprint
1 | 2 | C1, C4 | 6 | C 0603
2 | 12 | C2, C3, C5, C6, C7, C8, C9, C13, C15, C18, C27, C29 | 0.1 | C 0603
3 | 3 | C10, C11, C12 | 1u | C 0603
4 | 1 | C14 | 47u 35V | CP 6032
5 | 2 | C16, C28 | 47u 6V | CP 3216
6 | 1 | C17 | 47u 10V | CP 6032
7 | 8 | C19, C20, C21, C22, C23, C24, C25, C26 | 100u 35V | Capacitor_THT:CP_Radial_D8.0mm_P3.50mm
8 | 8 | D1, D2, D3, D4, D5, D6, D7, D8 | SP0505BAHT | SOT-23-6
9 | 14 | D9, D10, D11, D12, D13, D14, D15, D16, D17, D18, D19, D20, D21, D23 | SS14 | SOD-323
10 | 2 | D22, D27 | MBRS130L | D SMB
11 | 1 | D24 | PESD1CAN | SOT-23
12 | 1 | D25 | MM3Z7V5 | D 0805
13 | 1 | D26 | 1N5822 | DO-201
14 | 1 | J2 | Buttons/I2C | IDC 2x05p2.54 vertical
15 | 1 | J3 | Screen | IDC 2x05p2.54 vertical
16 | 11 | J4, J5, J7, J11, J14, J16, J18, J20, J22, J24, J26 | ADC2 | JST PH B4B 1x04 p2 vertical
17 | 1 | J6 | MOT_MUL | JST PH B5B 1x05 p2 vertical
18 | 1 | J8 | USB_B | USB B horizontal
19 | 1 | J9 | Screw_Terminal_01x03 | term 1x03p5.0 horiz
20 | 1 | J10 | Screw_Terminal_01x02 | term 1x02p5.0 horiz
21 | 8 | J12, J15, J17, J19, J21, J23, J25, J27 | Stepper | JST EH B4B 1x04 p2.5 vertical
22 | 1 | J13 | UART | JST PH B4B 1x03 p2.0 vertical
23 | 1 | L1 | 100u | Toroid P10.00mm_Diameter7-5mm
24 | 1 | Q1 | B0505S | B0x0xS
25 | 1 | Q2 | IRF9310 | SO-8
26 | 1 | Q3 | AO3401 | SOT-23
27 | 3 | R1, R11, R35 | 10k | R 0603
28 | 6 | R2, R9, R16, R17, R24, R25 | 22 | R 0603
29 | 3 | R3, R4, R34 | 7.5 | R 0603
30 | 1 | R5 | 5.1 | R 0603
31 | 6 | R6, R7, R8, R14, R15, R36 | 330 | R 0603
32 | 1 | R10 | 91k | R 0603
33 | 2 | R12, R13 | 47k | R 0603
34 | 1 | R18 | 120 | R 1210
35 | 2 | R19, R20 | 4k7 | R 0603
36 | 10 | R21, R22, R23, R26, R27, R28, R29, R30, R31, R32 | 100 | R 0603
37 | 1 | R33 | 1k5 | R 0603
38 | 2 | R37, R38 | 1k | R 0603
39 | 15 | RN1, RN2, RN3, RN4, RN5, RN6, RN7, RN8, RN9, RN10, RN11, RN12, RN13, RN14, RN15 | 330 | R 4x0603
40 | 1 | SW1 | Reset | Button_Switch_SMD:SW_SPST_FSMSM
41 | 1 | SW2 | Boot | Button_Switch_SMD:SW_SPST_FSMSM
42 | 1 | SW3 | SW_DIP_x01 | SPSTx01_Slide_6.7x4.1mm_W7.62mm_P2.54mm_LowProfile
43 | 1 | U1 | STM32F303VDTx | LQFP100
44 | 1 | U2 | ISO1050DUB | SOP-8
45 | 1 | U3 | USBLC6-2SC6 | SOT-23-6
46 | 1 | U4 | LM4050A(b)EX3-3.3 | SOT-323
47 | 1 | U5 | LM2576-5.0 | TO-220-5
48 | 2 | U6, U8 | LM1117-3.3 | SOT-223-3
49 | 1 | U7 | 74HC4051 | SOIC-16_3.9x9.9mm_P1.27mm
50 | 8 | XX1, XX2, XX3, XX4, XX5, XX6, XX7, XX8 | stepper_module | 2xPin_header_f_1x8 + 1xPin_header_f_1x2
51 | 1 | Y1 | NX5032GA-8MHz | SMD_5032-2Pin_5.0x3.2mm

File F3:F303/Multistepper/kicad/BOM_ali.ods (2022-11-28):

Item | Qty | Value | Footprint | link | price/pc. | price
1 | 100 | 6pF, 50V | C_0603 | https://aliexpress.ru/item/32956812359.html | 0.5322 | 53.22
2 | 100 | 100nF, 50V | C_0603 | https://aliexpress.ru/item/32956812359.html | 0.6361 | 63.61
3 | 100 | 1uF, 10V | C_0603 | https://aliexpress.ru/item/32956812359.html | 0.6361 | 63.61
4 | 10 | 47uF, 6.3V | CP_EIA-3216 (tantalum type A) | https://aliexpress.ru/item/1005003479811127.html | 7.659 | 76.59
5 | 100 | SP0505BAHT | SOT-23-6 | https://aliexpress.ru/item/4001287603652.html | 8.7622 | 876.22
6 | 100 | SS14 | SOD-323 (S4-0805) | https://aliexpress.ru/item/4001005015379.html | 0.6815 | 68.15
7 | 10 | MBRS130L | SMB | https://www.chipdip.ru/product/mbrs130lt3 | 28 | 280
8 | 30 | STPS1L30A | SMA | https://aliexpress.ru/item/4001242660880.html | 15.231 | 456.93
9 | 30 | PESD1CAN | SOT-23 | https://aliexpress.ru/item/1005003927949732.html | 5.841 | 175.23
10 | 1 | JST PH, 2mm (набор) | JST_PH_B4B-PH, P2.00mm, 1x2, 1x3, 1x4, 1x5, 1x6 | https://aliexpress.ru/item/1005004344115184.html | 725.74 | 725.74
11 | 10 | USB B | USB_B_OST_USB-B1HSxx 90degr. | https://aliexpress.ru/item/32834923469.html | 6.047 | 60.47
12 | 50 | Screw_Terminal_01x02 | MKDS-1,5-2_1x02_P5.00mm_Horizontal | https://aliexpress.ru/item/4000290521933.html | 3.6546 | 182.73
13 | 50 | JST XH, 2.5mm, 1x4 | JST_EH_B4B-EH-A_1x04_P2.50mm (XH2.5) | https://aliexpress.ru/item/1005003979785351.html | 11.3416 | 567.08
14 | 10 | 100uH | Toroid coil, 1.5A | https://aliexpress.ru/item/32840736610.html | 15.998 | 159.98
15 | 10 | B0505S-1W | B0505S-1W | https://aliexpress.ru/item/32840613546.html | 38.37 | 383.7
16 | 20 | IRF9310 | SO-8_3.9x4.9mm_P1.27mm | https://aliexpress.ru/item/4001271808483.html | 6.243 | 124.86
17 | 100 | 22R | R_0603 | https://aliexpress.ru/item/32858225842.html | 0.2666 | 26.66
18 | 100 | 7.5R | R_0603 | https://aliexpress.ru/item/32858225842.html | 0.2666 | 26.66
19 | 100 | 5.1R | R_0603 | https://aliexpress.ru/item/32858225842.html | 0.2666 | 26.66
20 | 100 | 91K | R_0603 | https://aliexpress.ru/item/32858225842.html | 0.2666 | 26.66
21 | 100 | 100R | R_0603 | https://aliexpress.ru/item/32858225842.html | 0.2666 | 26.66
22 | 100 | 330R | R_Array_Convex_4x0603 | https://aliexpress.ru/item/32918831775.html | 0.5539 | 55.39
23 | 20 | SW_DIP_x01 | SW_DIP_SPSTx01 | https://aliexpress.ru/item/4000143862047.html | 4.032 | 80.64
24 | 5 | STM32F303VDT6 | LQFP-100 | https://aliexpress.ru/item/1005003203257169.html | 952.71 | 4763.55
25 | 10 | LM4050BEX3-3.3 | SOT-323 | https://www.chipdip.ru/product/lm4050bex3-3.3-t | 200 | 2000
26 | 30 | LM2576-5.0WT | TO-220-5 | https://aliexpress.ru/item/32945428720.html | 12.356 | 370.68
27 | 40 | LM1117-3.3 (AMS1117) | SOT-223-3 | https://aliexpress.ru/item/1005004969134295.html | 4.3895 | 175.58
28 | 20 | 74HC4051 | SOIC-16_3.9x9.9mm_P1.27mm | https://aliexpress.ru/item/4000251923758.html | 6.243 | 124.86
29 | 50 | NX5032GA-8MHz | Crystal_SMD_5032-2Pin_5.0x3.2mm | https://aliexpress.ru/item/32912358855.html | 11.3544 | 567.72
30 | 50 | Pin header F 1x02 | Female pin header pitch 2.54mm, 1x2 pins | https://aliexpress.ru/item/1005003610378386.html | 4.9554 | 247.77
31 | 40 | Pin header F 1x08 | Female pin header pitch 2.54mm, 1x8 pins | https://aliexpress.ru/item/1005003610378386.html | 12.031 | 481.24
 |  |  |  | Total: |  | 13318.85

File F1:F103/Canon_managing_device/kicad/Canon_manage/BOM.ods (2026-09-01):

Item | Qty | Reference(s) | Value | Footprint
1 | 2 | C1, C2 | 6 | 0603
2 | 1 | C3 | 1u | 0805
3 | 5 | C4, C5, C6, C7, C8 | 0.1 | 0603
4 | 1 | C9 | 47u | 6032
5 | 1 | D1 | SP0504BAHT | SOT-23-5
6 | 1 | J37 | USB_C_Receptacle | USB_C_Receptacle_HRO_TYPE-C-31-M-12
7 | 1 | Q1 | DTA114Y | SOT-323
8 | 3 | Q2, Q3, Q4 | SI2302 | SOT-23
9 | 1 | R1 | 10k | 0603
10 | 4 | R2, R3, R4, R5 | 47 | 0603
11 | 7 | R6, R9, R11, R12, R14, R16, R18 | 4k7 | 0603
12 | 2 | R7, R8 | 22 | 0603
13 | 1 | R10 | 1k5 | 0603
14 | 3 | R13, R15, R17 | 330 | 0603
15 | 1 | U1 | STM32F103C6Tx | LQFP-48_7x7mm_P0.5mm
16 | 1 | U2 | LM1117-3.3 | SOT-223-3_TabPin2
17 | 1 | U3 | USBLC6-2SC6 | SOT-23-6
18 | 1 | U4 | MCP2551-I-SN | SOIC-8_3.9x4.9mm_P1.27mm
19 | 1 | Y1 | NX5032GA-8MHz | SMD_5032-2Pin_5.0x3.2mm

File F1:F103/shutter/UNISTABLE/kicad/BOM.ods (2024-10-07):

Reference | Value | Footprint | Qty
C1 | 1u | Capacitor_SMD:C_0805_2012Metric_Pad1.18x1.45mm_HandSolder | 1
C2,C4,C5,C6,C7 | 0.1 | Capacitor_SMD:C_0603_1608Metric_Pad1.08x0.95mm_HandSolder | 5
C3 | 47u | Capacitor_Tantalum_SMD:CP_EIA-6032-28_Kemet-C_Pad2.25x2.35mm_HandSolder | 1
C8,C9 | 6 | Capacitor_SMD:C_0603_1608Metric_Pad1.08x0.95mm_HandSolder | 2
D1 | CESD3V3 | Diode_SMD:D_0805_2012Metric_Pad1.15x1.40mm_HandSolder | 1
D2 | SMBJ30A | Diode_SMD:D_SMB-SMC_Universal_Handsoldering | 1
D3,D4,D5,D6 | SS14 | 3x323, 1xSMA | 4
J1 | ccd | Connector_JST:JST_PH_S2B-PH-K_1x02_P2.00mm_Horizontal | 1
J2 | hall | Connector_JST:JST_PH_S4B-PH-K_1x04_P2.00mm_Horizontal | 1
J3 | ShtrPower | TerminalBlock_Phoenix:TerminalBlock_Phoenix_MKDS-1,5-2-5.08_1x02_P5.08mm_Horizontal | 1
J4 | SWD | Connector_PinHeader_1.27mm:PinHeader_1x06_P1.27mm_Vertical | 1
J5 | 5Vext | Connector_JST:JST_PH_S2B-PH-K_1x02_P2.00mm_Horizontal | 1
J10 | shutter | Connector_JST:JST_PH_S2B-PH-K_1x02_P2.00mm_Horizontal | 1
J11 | USB_B | Connector_USB:USB_B_Lumberg_2411_02_Horizontal | 1
Q1 | IRL3303 | Package_TO_SOT_THT:TO-220-3_Horizontal_TabDown | 1
Q2 | DTA114Y | Package_TO_SOT_SMD:SOT-323_SC-70_Handsoldering | 1
R1 | 6.9 | Resistor_SMD:R_0603_1608Metric_Pad0.98x0.95mm_HandSolder | 1
R2,R9 | 100 | Resistor_SMD:R_0603_1608Metric_Pad0.98x0.95mm_HandSolder | 2
R3,R4 | 33 | Resistor_SMD:R_0603_1608Metric_Pad0.98x0.95mm_HandSolder | 2
R5 | 56k | Resistor_SMD:R_0603_1608Metric_Pad0.98x0.95mm_HandSolder | 1
R6,R8 | 4k7 | Resistor_SMD:R_0603_1608Metric_Pad0.98x0.95mm_HandSolder | 2
R7 | 10k | Resistor_SMD:R_0603_1608Metric_Pad0.98x0.95mm_HandSolder | 1
R10,R11 | 22 | Resistor_SMD:R_0603_1608Metric_Pad0.98x0.95mm_HandSolder | 2
R12 | 1k5 | Resistor_SMD:R_0603_1608Metric_Pad0.98x0.95mm_HandSolder | 1
U1 | LM1117-3.3 | Package_TO_SOT_SMD:SOT-223-3_TabPin2 | 1
U2 | STM32F103C6Tx | Package_QFP:LQFP-48_7x7mm_P0.5mm | 1
U3 | USBLC6-2SC6 | Package_TO_SOT_SMD:SOT-23-6_Handsoldering | 1
Y1 | NX5032GA-8MHz | Crystal:Crystal_SMD_5032-2Pin_5.0x3.2mm | 1

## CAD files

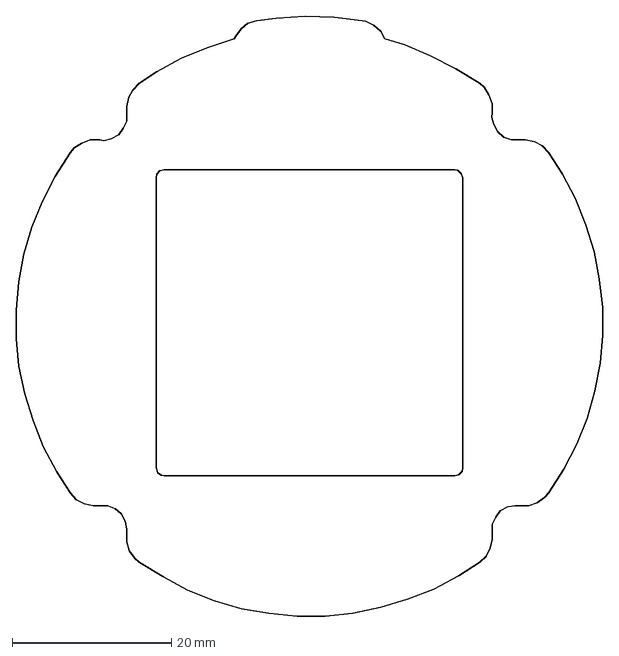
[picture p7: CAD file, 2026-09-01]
F1:F103/Canon_managing_device/kicad/outliers.dxf
73.7 x 75.4 mm

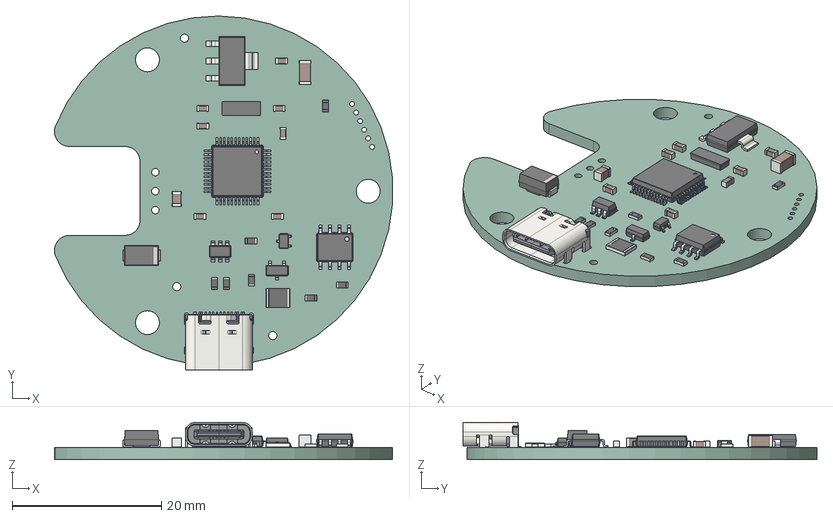
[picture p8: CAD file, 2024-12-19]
F1:F103/Hall_linear/kicad/Hall.step
45.2 x 47.4 x 4.96 mm
SOT_23
C_0603_1608Metric x 7
SOT_23_6
SOT_323_SC_70
R_0603_1608Metric x 7
C_0805_2012Metric
SOT_223
D_SMA
C_1206_3216Metric
USB_C_Receptacle_16P_TopMnt_Horizontal_GCT_USB4105-xx-A
MicroCrystal_CC4V_T1A
R_1210_3225Metric
LQFP_48_7x7mm_P05mm
SOIC_8_39x49mm_P127mm
Hall_PCB

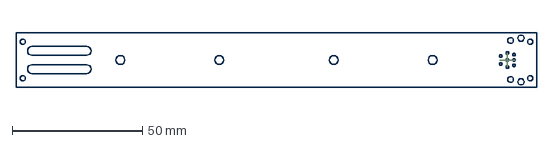
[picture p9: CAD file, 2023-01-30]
F3:F303/NitrogenFlooding/kicad/sensors/Heaters.dxf
200.0 x 21.0 mm

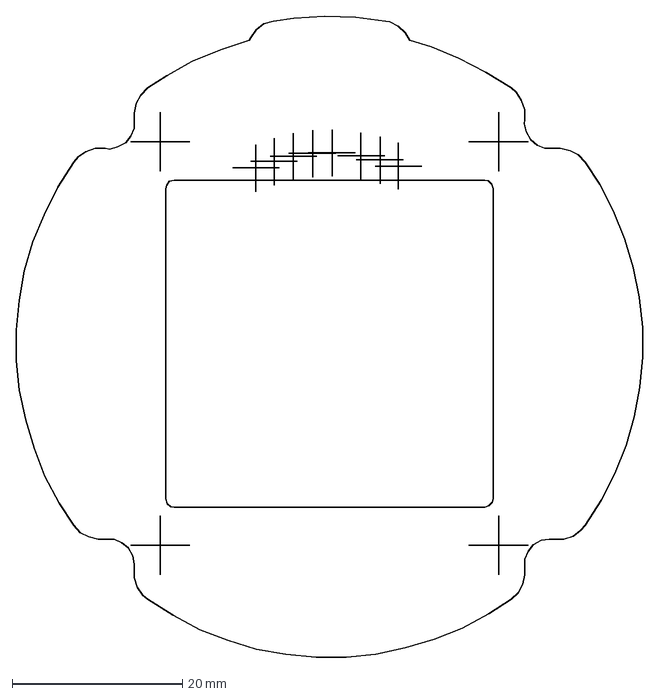
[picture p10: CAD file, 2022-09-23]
F1:F103/Canon_managing_device/kicad/silk.dxf
73.7 x 75.4 mm

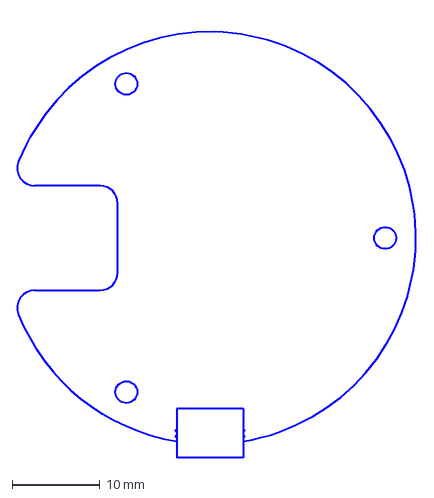
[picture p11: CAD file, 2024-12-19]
F1:F103/Hall_linear/kicad/PCB.dxf
45.8 x 50.3 mm

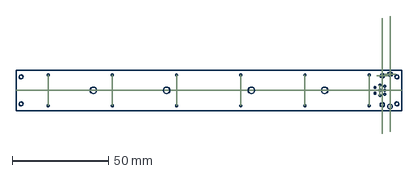
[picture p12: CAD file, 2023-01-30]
F3:F303/NitrogenFlooding/kicad/sensors/Sensors.dxf
200.0 x 60.9 mm

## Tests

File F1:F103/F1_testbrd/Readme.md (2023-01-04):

Simple test for STM32F103:
USART1
I2C1
USB
5 PWM channels
ADC1.0 & ADC1.5

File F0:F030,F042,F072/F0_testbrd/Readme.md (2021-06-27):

Simple test for STM32F0x2, PWM for all 4 channels of TIM3, USB (PL2303 emulator); USART1/2/3, SPI1/2, 
I2C1 tests, ADC1 IN0/1 connected to variable resistor.

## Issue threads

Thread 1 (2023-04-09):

Контакт

Sainero, 2023-04-09:
Здравствуйте, заинтриговал ваш ответ на https://www.cyberforum.ru/arm/thread3094714.html.
Не могли бы вы мне ответить на пару моментиков если не затруднит. Т.е. получается все параметры которые необходимо передавать, собирать и изменять будут находиться в EEPROM FLASH STM32 и их в любое время работы устройства, независимо от спящего режима ( в котором оно отмечено как опционально работает) можно будет изменить? Но как? Необходимо же для EEPROM прописать условия для терминала, т.е. ожидание команд (оформленных допустим в кейсах), правда не совсем понимаю как это будет пониматься в ПО. Получается написав приложение в visual studio, на стороне пользователя жмякается кнопка настройки параметра, а после выбора значения, отправляется например команда в hex формате, на которую МК отвечает изменением параметра работы устройства при этом не прерывая зашитый цикл работы?  Можете, пожалуйста отправить пример "У меня на всех железяках, требующих каких-то настроек, так и сделано." А то я уже потерялся в раздумьях, пересмотрев лекции и темы вашего сайта)

eddyem, 2023-04-09:
У меня множество примеров есть под F0, F1 и F3. Понятно, что нельзя писать в одно и то же место, используется все свободное место и каждая следующая запись делается в следующую свободную область, как место кончается - вся флеш-память, используемая для хранения, стирается, и пишется заново. EEPROM у F-серий нет, поэтому и приходится ее эмулировать во флеше (а там уже не миллионы, а десятки - в худшем случае даже единицы - тысяч циклов перезаписи).
Например, здесь: https://github.com/eddyem/stm32samples/blob/master/F3:F303/Multistepper/flash.c
Настройки меняются "на лету", а если нужно их сохранить, я даю комаду 'saveconf', и МК сохраняет текущую структуру с настройками во флеш-памяти. Протокол у меня всегда текстовый: это очень удобно на стадии отладки, пока еще нет высокоуровневого ПО для работы с железякой. Да и + ко всему у меня есть сокет-сервер, позволяющий выполнять неблокирующий доступ из приличного количества приложений к одной железяке. Да даже просто посмотреть, что там происходит с потоком команд и ответов на них: открываю терминал (мой tty_term) на нужном порту и смотрю (можно вообще netcat использовать, но он, к сожалению, не разделяет ввод и вывод, да и не имеет истории команд).

Closed 2023-05-10.

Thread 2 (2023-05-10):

Поддержка стандарта c99

Nikita-Presnov, 2023-05-10:
Возникли проблемы со стандартами си, ругается на u"COKPOWEHEU" и тому подобные контструкции
В мейкфайлах стандарт не зафиксирован, а между тем c99 применяетя сплошь и рядом.
Поддержка юникода появилась только с c11.

eddyem, 2023-05-10:
А что за компилятор? gcc все это съедает без каких-либо флагов.
В интернетах пишут, что по умолчанию стандарт эквивалентен опции `-std=gnu17` - так что, без указания `-std` все должно нормально работать.

Nikita-Presnov, 2023-05-10:
Вот хочется как раз без фитч c11, у меня просто ряд прошивок завязаны именно на c99

eddyem, 2023-05-10:
А какая разница? Пусть код будет C99, с опцией `-std=gnu23` он тоже соберется.

Nikita-Presnov, 2023-05-10:
Не всегда, c99 прощал очень многое, а стандарт становится всё строже
Ну да ладно, можно на int16 переписать потом

Closed 2023-05-10.

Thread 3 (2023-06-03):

i2c programmer

thirstyone, 2023-06-03:
(сорри, что в виде этикета)
Не попадалось, случаем, готовой прошивки программатора i2c под blue pill?

eddyem, 2023-07-16:
А зачем, если есть st-link и встроенный бутлоадер через USART? А у некоторых еще и DFU работает - вообще класс...
Не встречал готового - просто не нужно.

Closed 2023-07-16.

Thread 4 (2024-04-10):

nostartfiles?

thirstyone, 2024-04-10:
хочу собрать usb-hid для bluepill, ручками скопировал нужные файлы, затык на этом месте при сборке:

 LD      mk/usbhid103.elf
/usr/local/bin/arm-none-eabi-ld -nostartfiles --static -nostdlibs  -Linc/ld -L/usr/local/arm-none-eabi/lib -Tstm32f103x8.ld mk/keycodes.o mk/usart.o mk/usb.o mk/usb_lib.o mk/startup.o -lc /usr/local/Cellar/arm-none-eabi-gcc/10.3-2021.10/gcc/bin/../lib/gcc/arm-none-eabi/10.3.1/thumb/v7-m/nofp/libgcc.a -o mk/usbhid103.elf
/usr/local/bin/arm-none-eabi-ld: Error: unable to disambiguate: -nostartfiles (did you mean --nostartfiles ?)

eddyem, 2024-04-10:
Странно, что у меня без ошибок ld линкует (хотя должен был на эту опцию ругаться):

```
  LD      mk/usbhid103.elf
/opt/bin/arm-none-eabi-ld -nostartfiles --static -nostdlibs  -L../inc/ld -L/opt/arm-none-eabi/lib -Tstm32f103x8.ld mk/keycodes.o mk/main.o mk/usart.o mk/usb.o mk/usb_lib.o mk/startup.o -lc /opt/bin/../lib/gcc/arm-none-eabi/9.3.1/thumb/v7-m/nofp/libgcc.a -o mk/usbhid103.elf
```

Там старый Makefile, его надо убрать и вставить новый:

```
BINARY      := usbhid
# MCU code
MCU         ?= F103x6
# change this linking script depending on particular MCU model,
LDSCRIPT    ?= stm32f103x6.ld
DEFINES := -DUSB1_16 -DSTM32F10X_LD

include ../makefile.f1
include ../../makefile.stm32
```

Используя "каскадные" makefile'ы, как и в более свежих штуках.
Таких "древностей" у меня достаточно много, поэтому пока что не трогаю - нужно еще и проверить каждый на работоспособность..

Closed 2024-04-10.

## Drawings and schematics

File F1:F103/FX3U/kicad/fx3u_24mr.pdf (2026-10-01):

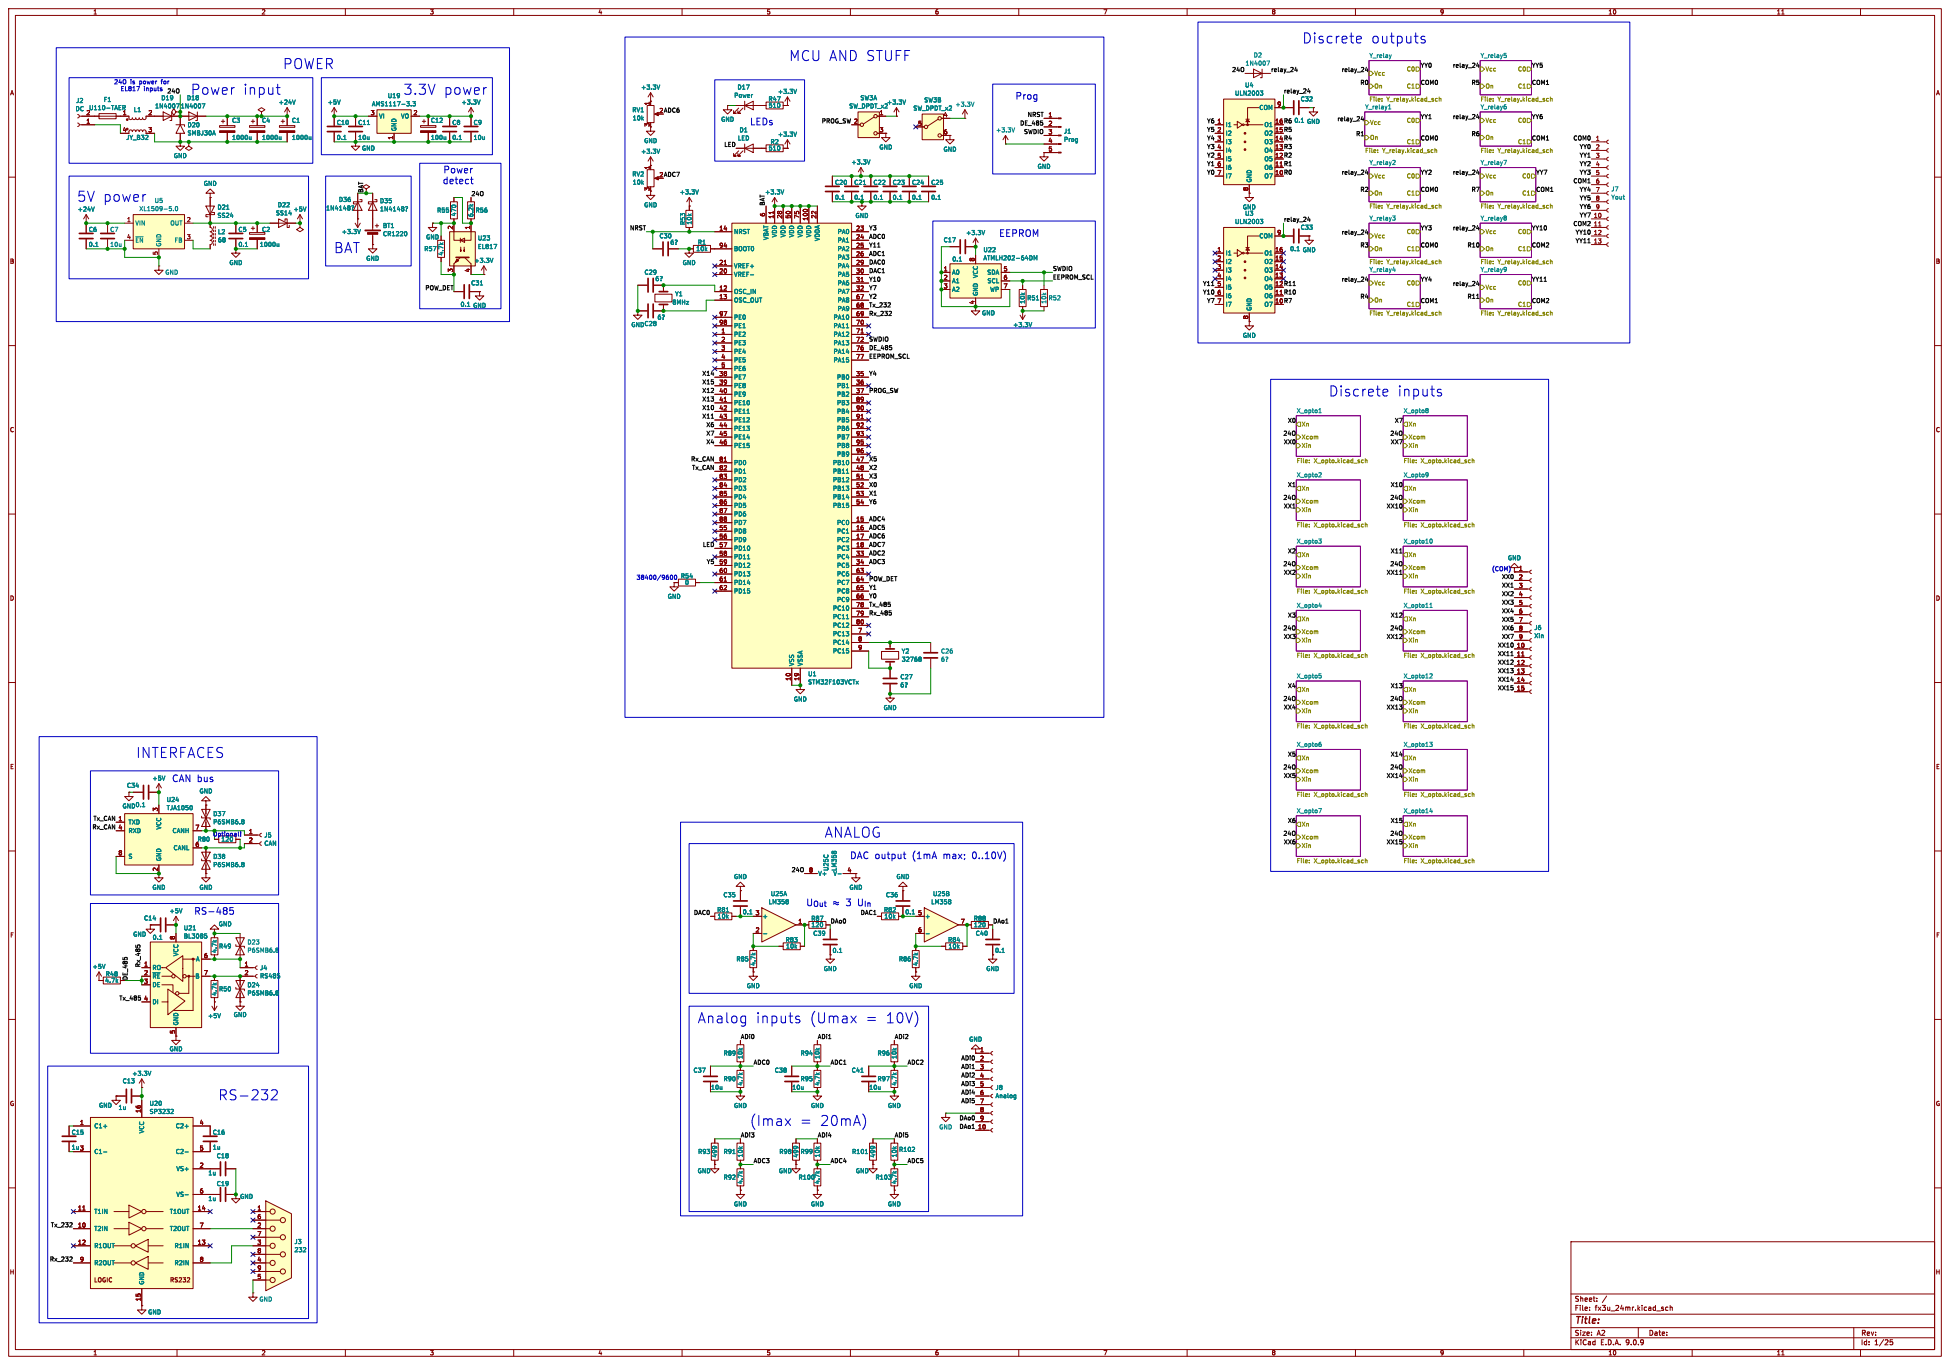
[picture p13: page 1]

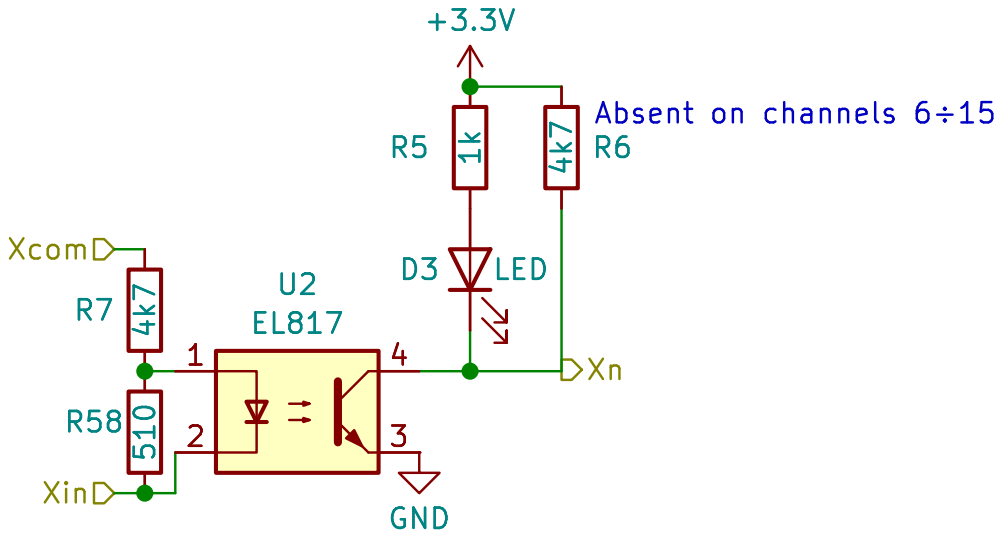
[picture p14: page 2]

Id: 2/25 Title: File: X_opto.kicad_sch Sheet: /X_opto1/

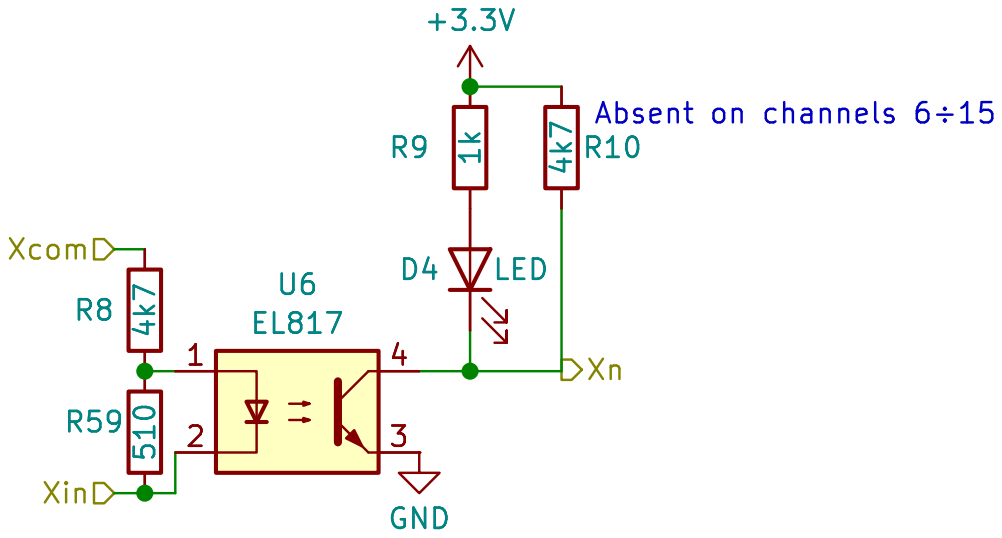
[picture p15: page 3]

Id: 3/25 Title: File: X_opto.kicad_sch Sheet: /X_opto2/

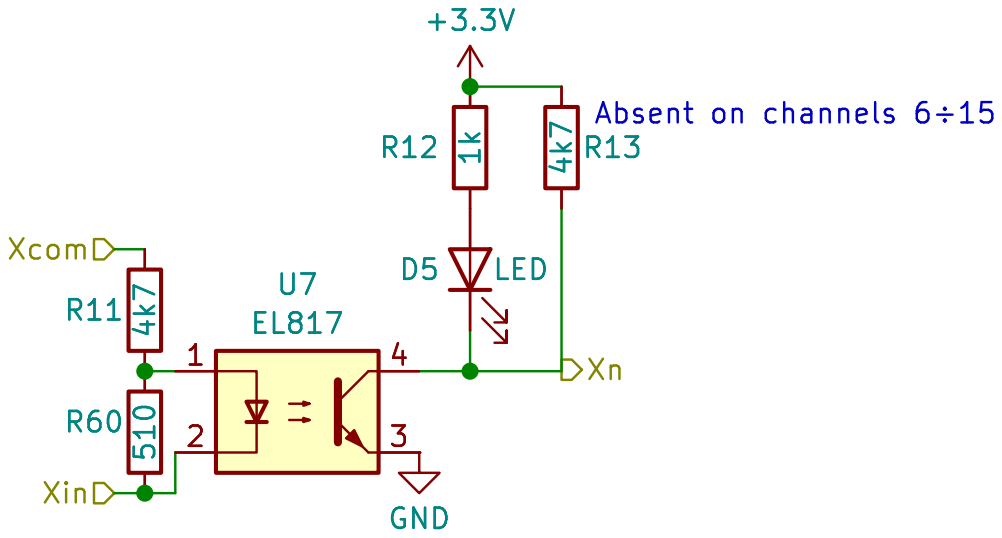
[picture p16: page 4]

Id: 4/25 Title: File: X_opto.kicad_sch Sheet: /X_opto3/

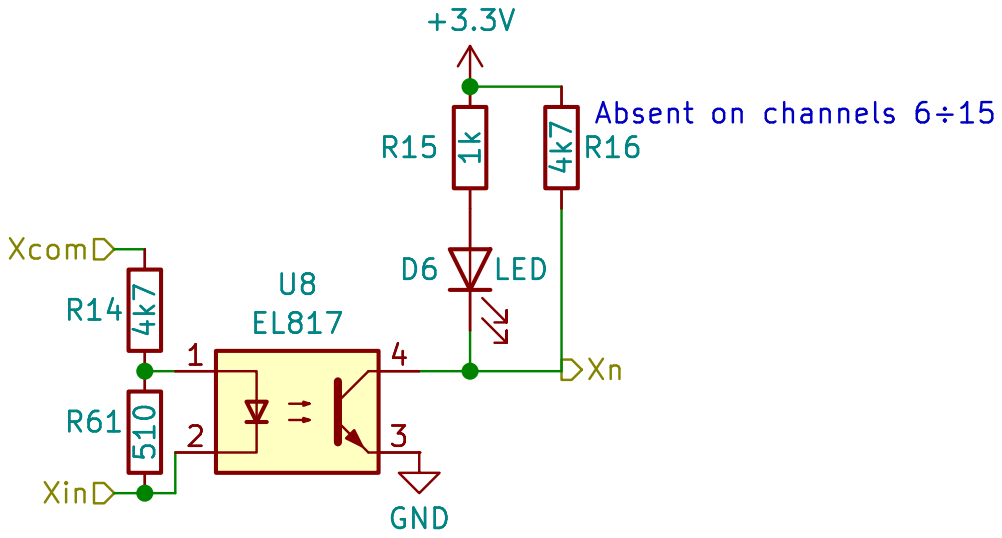
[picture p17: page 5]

Id: 5/25 Title: File: X_opto.kicad_sch Sheet: /X_opto4/

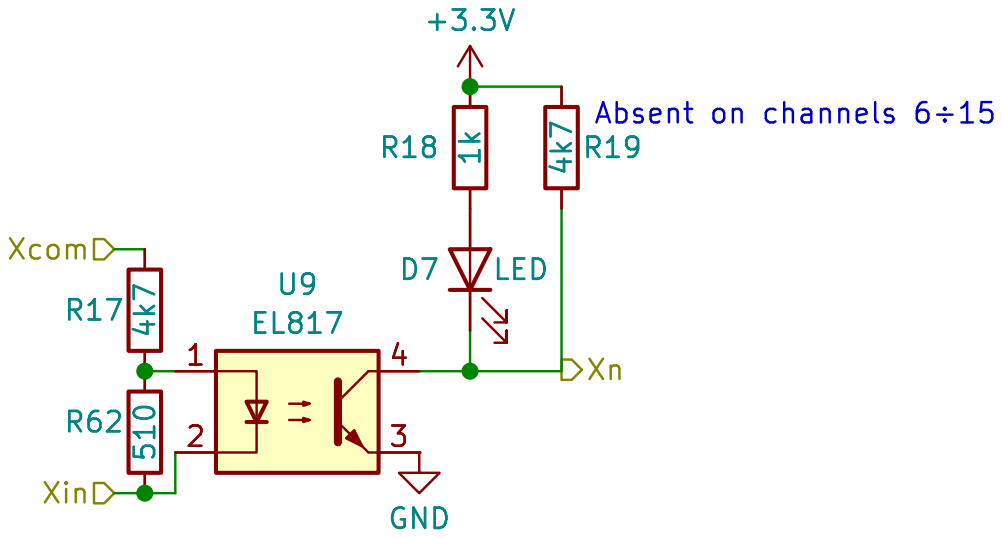
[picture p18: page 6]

Id: 6/25 Title: File: X_opto.kicad_sch Sheet: /X_opto5/

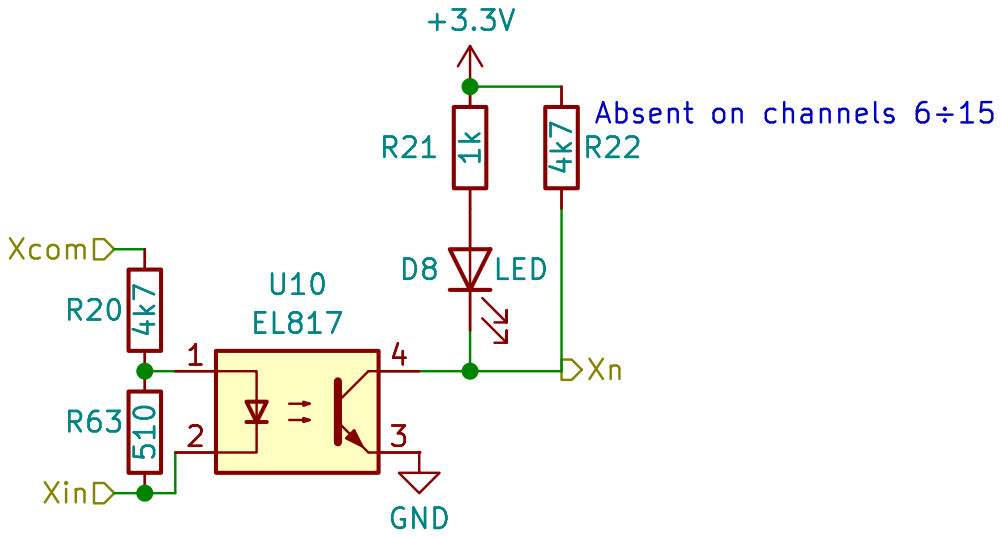
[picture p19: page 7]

Id: 7/25 Title: File: X_opto.kicad_sch Sheet: /X_opto6/

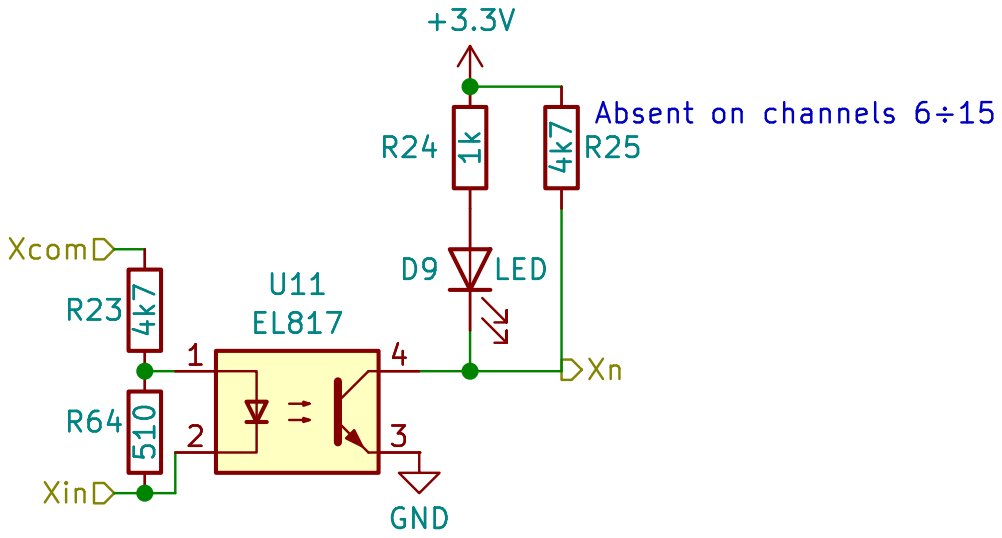
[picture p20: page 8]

Id: 8/25 Title: File: X_opto.kicad_sch Sheet: /X_opto7/

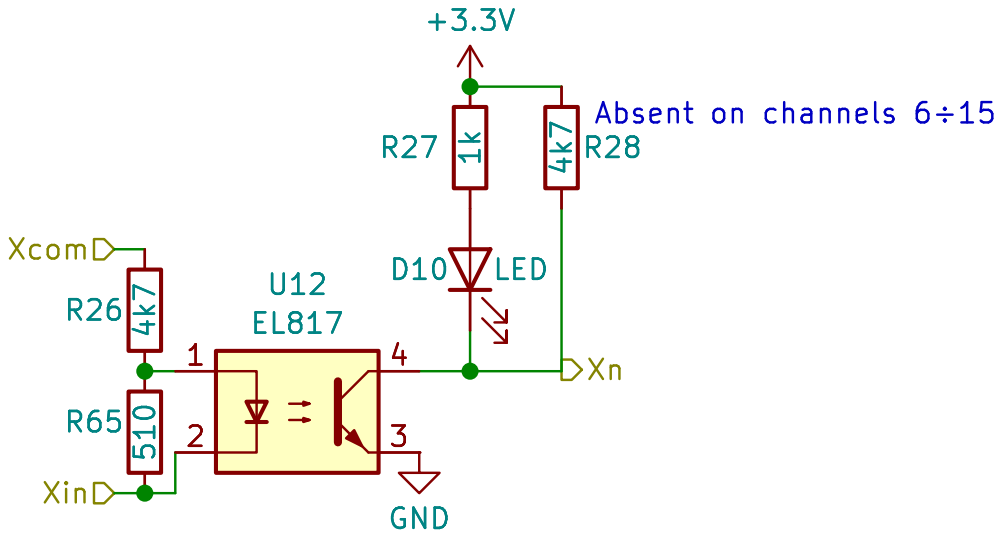
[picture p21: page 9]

Id: 9/25 Title: File: X_opto.kicad_sch Sheet: /X_opto8/

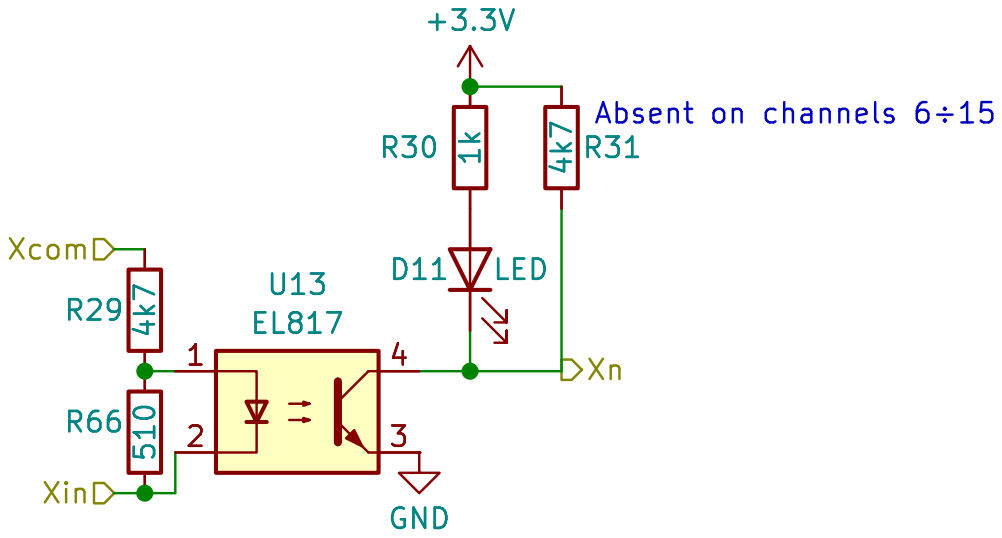
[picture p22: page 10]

Id: 10/25 Title: File: X_opto.kicad_sch Sheet: /X_opto9/

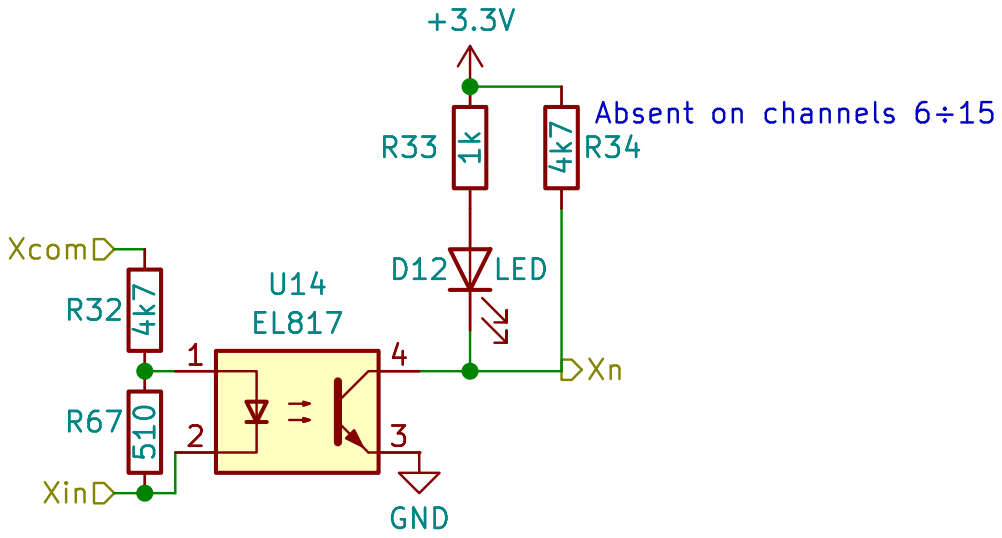
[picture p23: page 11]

Id: 11/25 Title: File: X_opto.kicad_sch Sheet: /X_opto10/

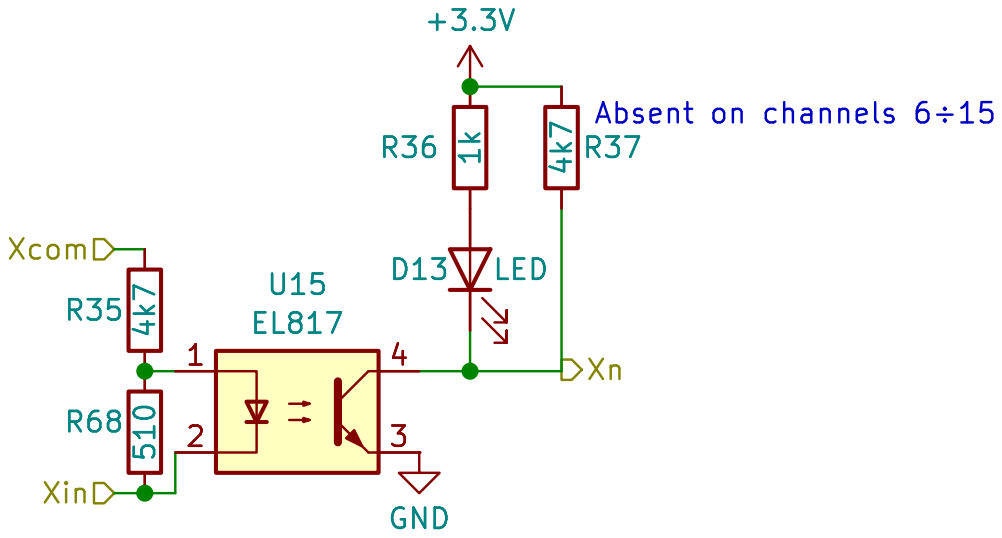
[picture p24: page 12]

Id: 12/25 Title: File: X_opto.kicad_sch Sheet: /X_opto11/

Id: 13/25 Title: File: X_opto.kicad_sch Sheet: /X_opto12/


Id: 14/25 Title: File: X_opto.kicad_sch Sheet: /X_opto13/


Id: 15/25 Title: File: X_opto.kicad_sch Sheet: /X_opto14/











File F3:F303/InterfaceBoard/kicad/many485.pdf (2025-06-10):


1 VDD 19 VDD 32 VSS 31 VDD 48 VSSA 12 VDD 64 VDDA 13 PA0 14 USART2_DE 15 USART2_TX 16 USART2_RX 17 PA4 20 SPI1_SCK 21 SPI1_MISO 22 PA7 23 PA8 41 PA9 42 PA10 43 USB_DM 44 USB_DP 45 SYS_JTMS-SWDIO 46 SYS_JTCK-SWCLK 49 PA15 50 PB0 26 PB1 27 PB2 28 PB3 55 PB4 56 PB5 57 PB6 58 PB7 59 PB8 61 PB9 62 USART3_TX 29 USART3_RX 30 PB12 33 PB13 34 USART3_DE 35 PB15 36 U6 STM32F303RBT6

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

þÿ$09;: isolated_232.kicad_schDE~{RE} TxRx
þÿ$09;: iso485.kicad_sch DE~{RE} TxRx

þÿ$09;: ssi_422.kicad_sch DE~{RE} TxRx


Id: 2/6 Title: File: iso485.kicad_sch Sheet: /Isolated_485_01/


Id: 3/6 Title: File: iso485.kicad_sch Sheet: /Isolated_485_2/


Id: 4/6 Title: File: iso485.kicad_sch Sheet: /Isolated_485_3/



Id: 6/6 Title: File: ssi_422.kicad_sch Sheet: /SSI_422/

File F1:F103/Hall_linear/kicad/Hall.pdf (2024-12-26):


1 PA0 10 PA1 11 PA2 12 PA3 13 PA4 14 PA5 15 PA6 16 PA7 17 PB0 18 PB1 19 PC13 2 PB2 20 PB10 21 PB11 22 VSS 23 VDD 24 PB12 25 PB13 26 PB14 27 PB15 28 PA8 29 PC14 3 PA9 30 PA10 31 PA11 32 PA12 33 PA13 34 VSS 35 VDD 36 PA14 37 PA15 38 PB3 39 PC15 4 PB4 40 PB5 41 PB6 42 PB7 43 BOOT0 44 PB8 45 PB9 46 VSS 47 VDD 48 PD0 5 PD1 6 NRST 7 VSSA

3 RXD 4 Vref 5 CANL 6 CANH 7 Rs 8 U4 MCP2551-I-SN VBAT

3 RXD 4 Vref 5 CANL 6 CANH 7 Rs 8 R9 4k7 GND GND

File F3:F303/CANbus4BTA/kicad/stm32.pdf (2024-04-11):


1 AIN0 10 AIN1 11 AIN2 12 AIN3 13 AIN4 14 PA5 15 PA6 16 PA7 17 PB0 18 PB1 19 PC13 2 PB2 20 PB10 21 PB11 22 VSS 23 VDD 24 PB12 25 PB13 26 PB14 27 PB15 28 PA8 29 PC14 3 USART1_Rx 30 USART1_Tx 31 PA11 32 PA12 33 PA13 34 VSS 35 VDDIO2 36 PA14 37 PA15 38 PB3 39 PC15 4 PB4 40 PB5 41 PB6 42 PB7 43 BOOT0 44 PB8 45 PB9 46 VSS 47 VDD 48 PF0 5 PF1 6 NRST 7 VSSA

Onboard switch
and external limit switches

1 CSB 2 SDI 3 SCK 4 SDO 5 VDDIO

1 DD+ 10 DD- 11 PIN 12 SPD 13 VDD2 14 GND2 15 VBUS2 16 GND1

2 VDD1 3 PDEN 4 SPU 5 UD- 6 UD+ 7 GND1

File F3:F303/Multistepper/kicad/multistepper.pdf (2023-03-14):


Terminal on/off CAN
connectors


7 7 | 2 2
6 6 | 3 3

1 5 5 | 6 6
2 7 7 | 8 8
3 9 | 10 10 | 1 1




stepper_M2
File: stepper_M.kicad_sch Vm
Diag
~{EN} STEP DIR MOSI MISO

stepper_M3

stepper_M4
SCK MOSI Vm

stepper_M5

stepper_M8









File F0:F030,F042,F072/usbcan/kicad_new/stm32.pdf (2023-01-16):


Nrst Boot0 Vcc Gnd SWDIO

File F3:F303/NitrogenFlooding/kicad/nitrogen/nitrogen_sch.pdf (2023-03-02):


Recommended PWM frequency < 2kHz. Vdrive GND


5 5 | 4 4
6 6 | 3 3

1 CSB 2 SDI 3 SCK 4 SDO 5 VDDIO

3 RXD 4 Vref 5 CANL 6 CANH 7 Rs 8 U1MCP2551-I-SN

3 RXD 4 Vref 5 CANL 6 CANH 7 Rs 8 R19



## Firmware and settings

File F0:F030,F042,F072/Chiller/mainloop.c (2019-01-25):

/*
 * This file is part of the Chiller project.
 * Copyright 2019 Edward V. Emelianov <edward.emelianoff@gmail.com>.
 *
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
 * You should have received a copy of the GNU General Public License
 * along with this program.  If not, see <http://www.gnu.org/licenses/>.
 */

#include "mainloop.h"
#include "hardware.h"
#include "adc.h"

int16_t Tset = 200; // temperature setpoint
int16_t NTCval[4] = {0,};

// common status for all functions from this file; pointer to this variable return @mainloop
static chiller_state retstatus = {
    .common_state = ST_OK,
    .heater_state = ST_OK,
    .cooler_state = ST_OK,
    .pump_state   = ST_OK
};

/* error bit fields: */
// chiller_error==0 - no errors
#define CE_NOERROR      (0)
// heater error (overheating)
#define CE_HEATER       (1<<0)
// output was too hot
#define CE_OUTHOT       (1<<1)
// output was too cool
#define CE_OUTCOOL      (1<<2)
// no flow sensor pulses detected
#define CE_NOFLOW       (1<<3)

// error code explaining why alarm is working
static uint8_t chiller_error;

static inline void increase_pump_pwm(){
    uint16_t pwm = GET_PUMP_PWM();
    if(pwm < 246){
        SET_PUMP_PWM(pwm+10);
        retstatus.pump_state = ST_FASTER;
    }
}
static inline void decrease_pump_pwm(){
    uint16_t pwm = GET_PUMP_PWM();
    if(pwm > MIN_PUMP_PWM+9){
        SET_PUMP_PWM(pwm-10);
        retstatus.pump_state = 0; // "ST_SLOWER"
    }
}

/**
 * @brief binsrch - binary search for new good value
 * @param oldval  - previuos value
 * @param curval  - current value
 * @param dir     - direction (1 - increase, 0 - decrease)
 * @return new value
 */
static inline uint16_t binsrch(uint16_t oldval, uint16_t curval, uint8_t dir){
    if(oldval == curval){
        if(dir) oldval = 256;
        else oldval = 0;
    }else{
        if(dir){ // increase
            if(oldval == 0) oldval = 256;
            else if(oldval < curval){
                oldval = 2*curval - oldval;
            }
        }else{   // decrease
            if(curval == 0) oldval = 0;
            else if(oldval > curval){
                oldval = 2*curval - oldval;
            }
        }
    }
    oldval = (oldval + curval) / 2;
    if(oldval > 255) oldval = 0;
    return oldval;
}

// change PWM according to dir (1->up, 0->down)
static void change_heater_pwm(uint8_t dir){
    static uint16_t oldpwm = 0;
    uint16_t pwm = binsrch(oldpwm, GET_HEATER_PWM(), dir);
    if(pwm != GET_HEATER_PWM()){
        oldpwm = GET_HEATER_PWM();
        SET_HEATER_PWM(pwm);
        if(dir){ // up
            retstatus.heater_state = ST_FASTER;
        }else{ // down
            if(pwm == 0) retstatus.heater_state = ST_OFF;
            else retstatus.heater_state = 0; // "ST_SLOWER"
        }
    }
}
static void change_cooler_pwm(uint8_t dir){
    uint16_t pwm = GET_COOLER_PWM();
    if(dir){ // up
        if(pwm < 224) SET_COOLER_PWM(pwm + 32);
        else SET_COOLER_PWM(255);
        if(pwm != GET_COOLER_PWM())
            retstatus.cooler_state = ST_FASTER;
    }else{ // down
        if(pwm > MIN_COOLER_PWM + 31) SET_COOLER_PWM(pwm - 32);
        else SET_COOLER_PWM(0);
        if(pwm != GET_COOLER_PWM())
            retstatus.cooler_state = GET_COOLER_PWM() ? 0 : ST_OFF; // "ST_SLOWER" / ST_OFF
    }
}

/**
 * @brief get_critical - check device for critical errors
 * @return 1 if critical error occured
 */
static inline uint8_t get_critical(){
    uint8_t ret = 0;
    // critical state: heater can burn out!
    // turn off heater & make signal
    if(HEATER_TEMPERATURE > MAX_HEATER_T){
        // change heater state to CRIT_HOFF
        retstatus.heater_state = ST_CRITICAL;
        if(GET_HEATER_PWM()){
            SET_HEATER_PWM(0);
            retstatus.heater_state |= ST_OFF;
        }
        chiller_error |= CE_HEATER;
        ret = 1;
    }
    // very hot output: turn off heater, turn on cooler & make signal
    if(OUTPUT_TEMPERATURE > MAX_OUTPUT_T){
        // change chiller state to CRIT_HOT
        retstatus.common_state = ST_CRITICAL;
        if(GET_HEATER_PWM()){
            SET_HEATER_PWM(0);
            retstatus.heater_state = ST_OFF;
        }
        if(GET_COOLER_PWM() < 255){
            SET_COOLER_PWM(255);
            retstatus.cooler_state = ST_FASTER;
        }
        // if water @input is also too hot, turn pump to max speed
        if(INPUT_TEMPERATURE > MAX_OUTPUT_T){
            increase_pump_pwm();
        }
        chiller_error |= CE_OUTHOT;
        ret = 1;
    }
    // very cool output: turn on heater (max power), turn off cooler & make signal
    if(OUTPUT_TEMPERATURE < MIN_OUTPUT_T){
        retstatus.common_state = ST_CRITICAL|ST_FASTER;
        if(GET_HEATER_PWM() < 255){
            SET_HEATER_PWM(255);
            retstatus.heater_state = ST_FASTER;
        }
        if(GET_COOLER_PWM()){
            SET_COOLER_PWM(0);
            retstatus.cooler_state = ST_OFF;
        }
        chiller_error |= CE_OUTCOOL;
        ret = 1;
    }
    // check flow rate & pump working
    if(GET_PUMP_PWM() >= MIN_PUMP_PWM){ // pump working
        if(flow_rate < MIN_FLOW_RATE){ // check pump
            // change chiller state to CRIT_NOFLOW
            retstatus.common_state = ST_CRITICAL|ST_OK;
            // increase pump speed
            //increase_pump_pwm();
            retstatus.pump_state = ST_CRITICAL;
            chiller_error |= CE_NOFLOW;
            ret = 1;
        }
    }else{
        // turn ON pump if PWM < minimal
        // (pump should be never off!)
        SET_PUMP_PWM(MIN_PUMP_PWM);
        retstatus.pump_state = ST_FASTER;
    }
    return ret;
}

/**
 * @brief check_alarm - check device status and turn off alarm if it is on
 */
static inline void check_alarm(){
    if(!ALARM_STATE()) return;
    // check errors & turn alarm OFF if there's no critical situations
    if(chiller_error == CE_NOERROR){
        // turn off alarm if there's no more errors
        ALARM_OFF();
    }else{
        if(chiller_error & CE_HEATER){ // clear CE_HEATER if heater T is normal
            if(HEATER_TEMPERATURE < NORMAL_HEATER_T){
                chiller_error &= ~CE_HEATER;
            }
        }
        if(chiller_error & CE_OUTHOT){ // clear CE_OUTHOT if Tout is normal
            if(OUTPUT_TEMPERATURE < OUTPUT_T_H){
                chiller_error &= ~CE_OUTHOT;
            }
        }
        if(chiller_error & CE_OUTCOOL){ // clear CE_OUTCOOL if Tout is normal
            if(OUTPUT_TEMPERATURE > OUTPUT_T_L){
                chiller_error &= ~CE_OUTCOOL;
            }
        }
        if(chiller_error & CE_NOFLOW){ // clear CE_NOFLOW if there's flow pulses
            if(flow_rate > NORMAL_FLOW_RATE){
                chiller_error &= ~CE_NOFLOW;
            }
        }
    }
}

static inline void checkOutT(){
    // check that T is between limits
    int8_t hc = 0; // need heating or cooling?
    if(OUTPUT_TEMPERATURE > Tset + TEMP_TOLERANCE) hc = -1; // need cooling
    else if(OUTPUT_TEMPERATURE < Tset - TEMP_TOLERANCE) hc = 1; // need heating
    if(hc){// out of limits -> check
        if(hc > 0){ // need heating: turn off cooler & turn on heater
            if(GET_COOLER_PWM()){
                SET_COOLER_PWM(0);
                retstatus.cooler_state = ST_OFF;
            }
            if(GET_HEATER_PWM() < 255){
                SET_HEATER_PWM(255);
                retstatus.heater_state = ST_FASTER;
            }else{
                // bad situation: need MORE heating!
            }
        }else{ // need cooling: turn off heater & turn on cooler
            if(GET_HEATER_PWM()){
                SET_HEATER_PWM(0);
                retstatus.heater_state = ST_OFF;
            }
            if(GET_COOLER_PWM() < 255){
                SET_COOLER_PWM(255);
                retstatus.cooler_state = ST_FASTER;
            }else{
                // bad situation: need MORE cooling!
            }
        }
    }else{ // T inside borders -> correct heating/cooling speed
        // Tout > Tset -> heater PWM up & cooler PWM down
        // else -> vice versa
        uint8_t ht = 2; // don't need heater/cooler change
        if(OUTPUT_TEMPERATURE < Tset - DT_TOLERANCE) ht = 1; // need heating
        else if(OUTPUT_TEMPERATURE > Tset + DT_TOLERANCE) ht = 0; // need cooling
        if(ht != 2){
            change_heater_pwm(ht);
            change_cooler_pwm(!ht);
        }
    }
    // if all OK, make pump slower
    if(retstatus.pump_state == ST_OK){
        decrease_pump_pwm();
    }
}

/**
 * @brief mainloop - the main chiller loop
 * by timer check current states & change them
 */
chiller_state *mainloop(){
    static uint32_t lastTmeas = 0xffff; // Temperatures measurement time
    static uint32_t lastTchk = 0xffff;  // last state checking time
    retstatus.common_state = ST_OK;
    retstatus.heater_state = ST_OK;
    retstatus.cooler_state = ST_OK;
    retstatus.pump_state   = ST_OK;
    // 1. Get temperatures and check critical situations
    if(Tms - lastTmeas < TMEASURE_MS) return &retstatus;
    lastTmeas = Tms;
    for(int i = 0; i < 4; ++i) // refresh NTC values
        NTCval[i] = getNTC(i);
    uint8_t alrm = get_critical();
    // check cooler
    if(GET_COOLER_PWM() > MIN_COOLER_PWM){ // cooler working
        // air temperature is very hot - cooler useless
        if(AIR_TEMPERATURE > OUTPUT_TEMPERATURE + TEMP_TOLERANCE){
            // change cooler state to OFF
            if(GET_COOLER_PWM()){
                SET_COOLER_PWM(0);
                retstatus.cooler_state = ST_OFF;
            }
        }
    }else{
        if(GET_COOLER_PWM()){
            SET_COOLER_PWM(0);
            retstatus.cooler_state = ST_OFF;
        }
    }
    // check alarm
    if(alrm){
        ALARM_ON();
        return &retstatus;
    }
    // there wasn't critical cases in this iteration, go further
    check_alarm();
    // Now check thermal data and decide what to do
    if(Tms - lastTchk < TCHECK_MS) return &retstatus;
    lastTchk = Tms;
    checkOutT();
    return &retstatus;
}

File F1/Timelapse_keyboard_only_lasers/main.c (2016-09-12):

/*
 * main.c
 *
 * Copyright 2015 Edward V. Emelianov <eddy@sao.ru, edward.emelianoff@gmail.com>
 *
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
 * You should have received a copy of the GNU General Public License
 * along with this program; if not, write to the Free Software
 * Foundation, Inc., 51 Franklin Street, Fifth Floor, Boston,
 * MA 02110-1301, USA.
 */

#include "main.h"
#include "usbkeybrd.h"
#include "hardware_ini.h"
#include "uart.h"
#include "GPS.h"
#include "adc.h"
#include <libopencm3/stm32/iwdg.h> // independent watchdog

volatile uint32_t Timer = 0; // global timer (milliseconds)
volatile uint32_t msctr = 0; // global milliseconds for different purposes
volatile int32_t systick_val = 0;
volatile int32_t timer_val = 0;
volatile int need_sync = 1;
volatile uint32_t last_corr_time = 0; // time of last PPS correction (seconds from midnight)

// STK_CVR values for all milliseconds (RVR0) and last millisecond (RVR1)
volatile uint32_t RVR0 = STK_RVR_DEFAULT_VAL, RVR1 = STK_RVR_DEFAULT_VAL;

#define TMNOTINI  {25,61,61}
curtime current_time = TMNOTINI;

// 0 - Button, 1..4 - Lasers1..4
curtime trigger_time[5] = {TMNOTINI, TMNOTINI, TMNOTINI, TMNOTINI, TMNOTINI};
uint32_t trigger_ms[5] = {DIDNT_TRIGGERED, DIDNT_TRIGGERED, DIDNT_TRIGGERED, DIDNT_TRIGGERED, DIDNT_TRIGGERED};

void time_increment(){
	Timer = 0;
	if(current_time.H == 25) return; // Time not initialized
	if(++current_time.S == 60){
		current_time.S = 0;
		if(++current_time.M == 60){
			current_time.M = 0;
			if(++current_time.H == 24)
				current_time.H = 0;
		}
	}
}

int main(void){
	uint8_t *string; // string from UART2 & pointer to last full GPS answer
	uint8_t lastGPSans[UART_BUF_DATA_SIZE] = {0};
	int i;
	rcc_clock_setup_in_hse_8mhz_out_72mhz();
	// init systick (1ms)
	systick_set_clocksource(STK_CSR_CLKSOURCE_AHB_DIV8); // Systyck: 72/8=9MHz
	systick_set_reload(STK_RVR_DEFAULT_VAL); // 9000 pulses: 1kHz
	systick_interrupt_enable();
	systick_counter_enable();

	GPIO_init();
/*
	// if PC11 connected to usb 1.5kOhm pull-up through transistor
	rcc_periph_clock_enable(RCC_GPIOC);
	gpio_set(GPIOC, GPIO11);
	gpio_set_mode(GPIOC, GPIO_MODE_OUTPUT_2_MHZ,
		      GPIO_CNF_OUTPUT_PUSHPULL, GPIO11);
*/
	usb_disconnect(); // turn off USB while initializing all
	usbkeybrd_setup();
	UART_init(USART2); // init GPS UART

	usb_connect(); // turn on USB
	GPS_send_start_seq();
	init_adc_sensor();
	// time (in milliseconds from MCU start) for trigger, adc & power LED status; power LED blink interval
	// blink time: (1000ms - powerLEDblink) - LED ON
	// GPSstatus_tm - timer for blinking by GPS LED if there's no GPS after timer is good
	// powerLEDblink - LED blinking time (depends on power level)
	uint32_t usbkbrdtm = 0, trigrtm = 0, powerLEDtm = 0, GPSstatus_tm = 0, powerLEDblink = 1;
	// istriggered == 1 after ANY trigger's event (set it to 1 at start to prevent false events)
	// GPSLEDblink - GPS LED blinking
	uint8_t  istriggered = 1, GPSLEDblink = 0;
	iwdg_set_period_ms(50); // set watchdog timeout to 50ms
	iwdg_start();
	while(1){
		if(Timer == 500) // turn off PPS LED after 500ms
			gpio_set(LEDS_Y_PORT, LEDS_Y2_PIN);
		poll_usbkeybrd();
		if(usbkbrdtm != msctr){ // process USB not frequently than once per 1ms
			process_usbkbrd();
			usbkbrdtm = msctr;
		}
		if((string = check_UART2())){
			memcpy(lastGPSans, string, UART_BUF_DATA_SIZE);
			GPS_parse_answer(string);
		}
		if(GPIO_ODR(GPIOA) & GPIO0 || GPIO_ODR(GPIOA) & GPIO8 ){ // Laser 1/4 shines
			gpio_clear(LEDS_Y_PORT, LEDS_Y1_PIN);
		}else{
			gpio_set(LEDS_Y_PORT, LEDS_Y1_PIN);
		}
		if(GPIO_ODR(GPIOA) & GPIO1){ // Laser 2 shines
			gpio_clear(LEDS_R_PORT, LEDS_R1_PIN);
		}else{
			gpio_set(LEDS_R_PORT, LEDS_R1_PIN);
		}
		if(GPIO_ODR(GPIOA) & GPIO7){ // Laser 3 shines
			gpio_clear(LEDS_G_PORT, LEDS_G1_PIN);
		}else{
			gpio_set(LEDS_G_PORT, LEDS_G1_PIN);
		}
		if(istriggered){ // there was any trigger event
			if(msctr - trigrtm > TRIGGER_DELAY || trigrtm > msctr){ // turn off LED & beeper
				istriggered = 0;
				gpio_set(BEEPER_PORT, BEEPER_PIN);
				for(i = 0; i < 5; ++i){
					if(trigger_ms[i] != DIDNT_TRIGGERED){ // show all messages
						P("Event");
						put_char_to_buf('0' + i);
						P(" time: ");
						print_time(&(trigger_time[i]), trigger_ms[i]);
						trigger_ms[i] = DIDNT_TRIGGERED;
					}
				}
			}
		}else{
			for(i = 0; i < 5; ++i){
				if(trigger_ms[i] != DIDNT_TRIGGERED){ // Control Button pressed or Lasers shadows
					trigrtm = msctr;
					istriggered = 1;
					/*if(*lastGPSans){
						P("GPS last message: ");
						send_msg((char*)lastGPSans);
						newline();
					}*/
				}
			}
			if(istriggered){ // turn on beeper
				gpio_clear(BEEPER_PORT, BEEPER_PIN);
			}
		}
		// check 12V power level (once per 1ms)
		if(powerLEDtm != msctr){
			uint16_t _12V = ADC_value;
			if(_12V < GOOD_POWER_LEVEL){ // insufficient power? - blink LED R2
				// calculate blink time only if there's [was] too low level
				if(_12V < POWER_ALRM_LEVEL || powerLEDblink){
					powerLEDblink = GOOD_POWER_LEVEL - _12V;
					// critical level: power LED is almost OFF
					if(_12V < POWER_CRITICAL_LEVEL) powerLEDblink = 990;
				}
			}else{ // power restored - LED G2 shines
				if(powerLEDblink){
					gpio_clear(LEDS_G_PORT, LEDS_G2_PIN);
					powerLEDblink = 0;
				}
				powerLEDtm = msctr;
			}
			if(powerLEDblink){
				if(GPIO_ODR(LEDS_G_PORT) & LEDS_G2_PIN){ // LED is OFF
					if(msctr - powerLEDtm > powerLEDblink || msctr < powerLEDtm){ // turn LED ON
						powerLEDtm = msctr;
						gpio_clear(LEDS_G_PORT, LEDS_G2_PIN);
					}
				}else{
					if(msctr - powerLEDtm > (1000 - powerLEDblink) || msctr < powerLEDtm){ // turn LED OFF
						powerLEDtm = msctr;
						gpio_set(LEDS_G_PORT, LEDS_G2_PIN);
					}
				}
			}
		}
		// check GPS status to turn on/off GPS LED
		if(current_time.H < 24){ // timer OK
			if((GPS_status != GPS_VALID) || need_sync){
				GPSLEDblink = 1;
			}else{
				GPSLEDblink = 0;
				if((GPIO_ODR(LEDS_R_PORT) & LEDS_R2_PIN) == 0)
					gpio_clear(LEDS_R_PORT, LEDS_R2_PIN); // turn ON R2 LED
			}
			if(GPSLEDblink){
				if(msctr - GPSstatus_tm > 500 || msctr < GPSstatus_tm){
					GPSstatus_tm = msctr;
					if(GPIO_ODR(LEDS_R_PORT) & LEDS_R2_PIN){ // LED is OFF
						gpio_clear(LEDS_R_PORT, LEDS_R2_PIN);
					}else{
						gpio_set(LEDS_R_PORT, LEDS_R2_PIN);
					}
				}
			}
		}else{ // something bad with timer - turn OFF R2 LED
			if(!(GPIO_ODR(LEDS_R_PORT) & LEDS_R2_PIN)){
				gpio_set(LEDS_R_PORT, LEDS_R2_PIN);
			}
		}
	iwdg_reset(); // reset watchdog
	}
}


/**
 * SysTick interrupt: increment global time & send data buffer through USB
 */
void sys_tick_handler(){
	++Timer;
	++msctr;
	if(Timer == 999){
		STK_RVR = RVR1;
	}else if(Timer == 1000){
		STK_RVR = RVR0;
		time_increment();
	}
}
// STK_CVR - current systick val
// STK_RVR - ticks till interrupt - 1
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

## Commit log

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2015-09-14 Next iteration: some LEDs & beeper
    [LEDs.sch, diff_schematics.kicad_pcb]
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2016-04-21 fix error in 1-wire data conversion for DS18B20
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2017-01-10 Rebuild tree structure, add blink for STM32F042
    [LEDs.sch, diff_schematics.kicad_pcb]
2017-01-10 fix (git add -A)
    [LEDs.sch, diff_schematics.kicad_pcb]
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2018-06-21 loopback CAN mode
    [stm32-BOM.ods, stm32.kicad_pcb, stm32.sch]
2018-09-08 add CDC for STM32F042 (not working yet)
    [main.c]
2018-11-03 try to add STM32F1 nolib (not working yet)
    [main.c]
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2018-11-11 fix bug with receiving a lot of data from USB
    [stm32-2018-10-23-16-51-39.sch]
2018-12-20 add chiller
    [Chiller_control.kicad_pcb, Chiller_control.sch, Chiller_control_bom.ods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]
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2018-12-23 add PWM for chiller outputs
    [Chiller_control-2018-12-20-22-32-46.sch]
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2019-01-25 Chiller works
    [Chiller_control.sch]
2019-01-28 Change chiller schematics: fix bugs, prepare for manufacture production
    [Chiller_control-2018-12-20-22-32-46.sch, Chiller_control.csv, Chiller_control.kicad_pcb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]
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2019-04-25 little fixes in pl2303
    [Servo_control.kicad_pcb, Servo_control.sch, Servo_control_bom.ods]
2019-04-26 some fixes in pl2303
    [main.c]
2019-04-29 add USBHID (not working)
    [main.c]
2019-04-30 fix some bugs with USB HID; increase keyboard speed up to 950 symbols per minute
    [main.c]
2019-05-18 Working code for STM32F0x2 test board, development of the same code for STM32F103
    [stm32.kicad_pcb, stm32.sch]
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2019-06-27 add LIDAR chronometer (pre-alpha)
    [BOM_chrono.csv, chrono.kicad_pcb, chrono.sch]
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2019-08-07 fixed bug with systick correction
    [GPS.c, main.c]
2019-09-20 fix problem with LIDAR
    [GPS.c, main.c]
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2019-12-03 Add SPI DMA Tx example
    [chrono.kicad_pcb, chrono.sch]
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2020-01-29 CDC works @PC, not works @android
    [main.c]
2020-02-05 add kicad schematic of CANbus_stepper
    [stm32-B_Cu.gbr, stm32-B_Mask.gbr, stm32-B_SilkS.gbr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]
2020-02-07 Fixed chronometer
    [BOM_chrono.csv, chrono.kicad_pcb, chrono.sch]
2020-03-12 Add starting sources to CANbus_stepper
    [stm32.csv, stm32.sch]
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2020-04-05 Fix bugs in PL2303 emulation
    [main.c]
2020-04-05 Fix USB HID for F103
    [main.c]
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2020-04-29 Fix error in CAN speed calculation
    [main.c]
2020-05-23 Move usbcdc->usbcan, add schematic & PCB
    [stm32-B_Cu.gbr, stm32-B_Mask.gbr, stm32-B_SilkS.gbr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]
2020-07-27 DRV8825 works, PCB should be rebuild for ability of encoder connection
    [stm32.sch]
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2020-10-25 Add pre-alpha version of Socket_fans code
    [stm32-B_Cu.gbr, stm32-B_Mask.gbr, stm32-B_SilkS.gbr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]
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2020-11-02 Finished socket_fans, fixed bug with wrong piecewise approximation
    [main.c]
2020-11-02 fixed schematics of socket_fans
    [stm32.csv, stm32.kicad_pcb, stm32.sch]
2020-11-08 fixed CDC-ACM for F103: use only one EP
    [main.c]
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2021-02-18 fix negative numbers bug in dewpoint
    [BMP280.c, main.c]
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2021-02-18 fix I2C scan
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2021-06-23 Add F0-F1-F3 LQFP48 testboard schematic
    [stm32.csv, stm32.kicad_pcb, stm32.sch]
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2021-07-06 almost fix SPI in F0 testboard
    [main.c]
2021-07-23 nwxt appr. to canusbrelay
    [stm32 (2).csv]
2021-07-29 start 2 draw 3 steppers management board
    [stm32.kicad_pcb, stm32.sch]
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2021-10-03 fixed some bugs in 3steppersLB schematic
    [stm32-B_Cu.gbr, stm32-B_Mask.gbr, stm32-B_Paste.gbr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]
2021-10-22 add first approx to 3steppersLB
    [stm32-B_Cu.gbr, stm32-B_Mask.gbr, stm32-B_Paste.gbr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]
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2021-11-14 add some shit, but still have a problem
    [main.c]
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2021-12-02 fix problems with CANbus, add USB-dump of error & command codes for CAN
    [main.c]
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2022-02-12 fixed bug with zero float
    [main.c]
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2022-03-16 fixed trouble with sybolic links
    [main.c]
2022-06-10 fix some bugs in 3steppers
    [main.c]
2022-07-08 add SSI->SPI on NUCLEO042
    [stm32.kicad_sch]
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2022-07-21 change 3steppersLB schematic for kicad 6
    [stm32.csv, stm32.kicad_pcb, stm32.kicad_sch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]
2022-08-31 little fix in USB ringbuffer for STM32F103
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2022-09-23 fix some kicad
2022-09-23 add Canon managing device KiCAD schematic & PCB
    [Canon_manage-B_Cu.gbr, Canon_manage-B_Mask.gbr, Canon_manage-B_Paste.gbr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]
2022-09-23 add new PCB for CAN-USB adapter
    [Canon_manage.drl, stm32-B_Cu.gbr, stm32-B_Mask.gbr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]
2022-09-27 add CANbus4BTA KiCAD plots
    [optocouple.kicad_sch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]
2022-10-28 Modify usbcan for using ringbuffer, refresh kicad schematic & PCB
    [stm32-B_Cu.gbr, stm32-B_Mask.gbr, stm32-B_Silkscreen.gbr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]
2022-10-28 add/change README files, remove double of Canon management
    [stm32.kicad_pcb, stm32.kicad_sch, stm32.sch]
2022-11-11 fixed silkscreen bug in CANbus4BTA
    [stm32-B_Cu.gbr, stm32-B_Mask.gbr, stm32-B_Paste.gbr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]
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2022-11-22 fixed bug with dc-dc polarity in CANbus4BTA
    [stm32.kicad_pcb, stm32.kicad_sch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]
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2022-11-25 Multistepper PCB almost ready
    [ADC.kicad_sch, mcubase.kicad_sch, motors.kicad_sch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]
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2022-11-28 add BOM to multistepper
    [ADC.kicad_sch, BOM_ali.ods, BOM_full.ods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]
2022-11-30 F103 fix makefile
    [stm32.kicad_pcb, stm32.kicad_sch]
2022-11-30 fixed bug with multistepper schematic (forgot USB DP pullup)
    [mcubase.kicad_sch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]
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2022-12-05 fixed some bugs in canUART for F103, add some features to usbcan_ringbuffer for F0
    [main.c]
2022-12-27 start fixed F1 testboard for new board type
    [main.c]
2022-12-28 add simplest blink for STM32F407
    [stm32.kicad_pcb, stm32.kicad_sch]
2022-12-28 change 510R -> 5.1k on canon managin device
    [Canon_manage.kicad_sch]
2022-12-30 change Canon manage PCB (add CAN, USB pullup, small crystall)
    [Canon_manage-B_Cu.gbr, Canon_manage-B_Mask.gbr, Canon_manage-B_Paste.gbr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]
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2023-01-10 fixed i2c (internal pullup + right scan method)
2023-01-11 Add kicad schematic & PCB for nitrogen autoflooding machine
    [MCU.kicad_sch, nitrogen.csv, nitrogen.kicad_pcb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]
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2023-01-12 Some little fixes + add BOM
    [BOM.ods, MCU.kicad_sch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]
2023-01-13 multis. schematic in pdf
    [BOM_full.ods]
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2023-01-15 fixed bug with usblc6 on usbcan
    [stm32-B_Cu.gbr, stm32-B_Mask.gbr, stm32-B_Silkscreen.gbr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]
2023-01-16 fixed bug in multisteppers PCB
    [ADC.kicad_sch, BOM_ali.ods, BOM_full.ods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]
2023-01-17 fixed float printf for F303
    [main.c]
2023-01-18 change F303's Makefile to version control; fixed bugs in F303 usb ringbuffer, add two buffers like in F0x2
    [main.c]
2023-01-22 add I2C for F303, fix bug in USB (some variables wasn't volatile)
    [main.c]
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2023-01-24 Fixed ADC (bug in index of ADC2 + DAC works as constant val)
2023-01-30 add PCBs for pt1000 and heaters
    [BOM_need.ods, Heaters.dxf, Sensors.dxf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]
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2023-02-06 fixed USBDP pullup in `Multistepper` (it works always, so you can use DFU)
    [ADC.kicad_sch, BOM_full.ods, mcubase.kicad_sch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]
2023-02-06 Fixed USB, problems with CAN
    [main.c]
2023-02-21 some bugs fixed, but found new (e.g. ADC always give 4095)
2023-02-24 fixed bugs in multistepper: eeprom in flash + adc, tested on TMC2130, but don't work on TMC2230
    [main.c]
2023-03-02 fixed BOM, add pdf schematic to Canon and Nitrogen
    [BOM.ods, Canon_manage.csv]
2023-03-13 fixed Canon-manage PCB
    [Canon_manage-B_Cu.gbr, Canon_manage-B_Mask.gbr, Canon_manage-B_Paste.gbr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]
2023-03-14 Add power management to Canon managing device
    [Canon_manage-B_Cu.gbr, Canon_manage-B_Mask.gbr, Canon_manage-B_Paste.gbr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]
2023-03-14 fixed bug with USART2/3 pullup, `prog` moved to the edge of PCB
    [motors.kicad_sch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]
2023-03-15 fixed schematics @ canon managing, add initialization for absolute positioning, TODO: add CAN bus management
    [Canon_manage-B_Cu.gbr, Canon_manage-B_Mask.gbr, Canon_manage-B_Paste.gbr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]
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2023-04-10 fixed USB: add iInterface, remove trash
    [main.c]
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2023-04-23 still a lot of bugs
    [main.c]
2023-04-26 still have unknown problems
    [main.c]
2023-04-29 works, but still have a lot of bugzzz
    [main.c]
2023-05-02 change end-switches' connectors to 2mm
    [BOM_full.ods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]
2023-05-02 move all elements to one side, add 3 PWM channels
    [BOM.ods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]
2023-05-03 fixed PWM
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2023-05-10 add simple work with fonts (too small for this screen), still have some bugs with sprites in lower right corner
    [main.c]
2023-05-11 Add font scaling, fix trouble with sprites, fix trouble with blocking SPI read (DMA read non-fixing without reset SPI)
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2023-05-15 add calculations of T & P by ADC; Release mode still have problems
    [BMP280.c, main.c]
2023-07-02 add pre-pre-alpha of CAR-canbus for windglasses management
    [windshield.kicad_pcb, windshield.kicad_sch]
2023-07-03 continue of working on window
    [windshield.kicad_sch]
2023-07-10 start drawing a PCB
    [windshield.kicad_pcb, windshield.kicad_sch]
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2023-08-08 save under new version
    [MCU.kicad_sch, nitrogen.kicad_pcb, nitrogen.kicad_sch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]
2023-08-08 save under new kicad
    [Canon_manage.kicad_pcb, Canon_manage.kicad_sch, stm32.kicad_pcb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]
2023-08-10 add shutter PCB and schematics
    [shutter.kicad_pcb, shutter.kicad_sch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]
2023-09-11 fixed some problems with USART
    [main.c]
2023-09-12 add command reset, fix some troubles
    [main.c]
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2023-09-29 change to usb ringbuffer; still have veird bug using USART
    [main.c]
2023-10-02 fixed a very stupid bug
    [main.c]
2023-11-28 add readme and USB proto
    [BOM.ods, BOM_full.ods, optocouple.kicad_sch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]
2023-12-07 fixed bugs in shutter; need to check its work and finish readme
    [main.c]
2023-12-08 fixed bugs and update readme
    [main.c]
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2024-03-04 add buttons, not tested yet
    [windshield.kicad_pcb, windshield.kicad_sch]
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2024-03-06 sync with development PC; old -> kicad8
    [optocouple.kicad_sch, stm32.kicad_pcb, stm32.kicad_sch]
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2024-03-08 PEP emulation (didn't test yet)
    [main.c]
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2024-03-19 some code fixes, start to draw new schematic
    [optocouple.kicad_sch, stm32.kicad_pcb, stm32.kicad_sch]
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2024-03-25 seems like schematic is ready
    [optocouple.kicad_sch, stm32.kicad_sch]
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2024-04-05 change USB6B1 to USBLC6
    [BOM.ods, BOM_full.ods, stm32.kicad_pcb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]
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2024-06-03 Always working, but some of schematics was wrong
    [main.c]
2024-06-21 BOM fixed
    [BOM_full.ods, bom.csv, stm32.csv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]
2024-07-02 fixed bug with LEDs
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2024-08-15 start fixing of this shit
    [main.c]
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2024-09-02 hide deprecated code; make USB snippet common for F0/F1/F3
    [chrono.kicad_pcb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]
2024-09-26 almost ready but have IWDG reset when trying to send data over RS-232 in CANbus flooding
    [main.c]
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2024-10-03 KICAD schematic of UNI-stable shutter
    [shutter.csv, shutter.kicad_pcb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]
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2024-12-19 Add kicad schematic and PCB
    [Hall-B_Cu.gbr, Hall-B_Mask.gbr, Hall-B_Paste.gbr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]
2024-12-26 fixed PCB, add pre-alpha code
    [BOM.ods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]
2025-01-07 some fixes, now speed is big enough
    [main.c]
2025-02-03 fixed esw text
    [multistepper-B_Cu.gbr, multistepper-B_Mask.gbr, multistepper-B_Paste.gbr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]
2025-02-05 some fixes of old bugs
    [main.c]
2025-03-11 fix Canon managing to new USB (CDC ACM)
    [main.c]
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2025-04-04 add schematic and PCB
    [BOM.csv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]
2025-06-02 fix code for new PCB
    [main.c]
2025-08-24 add debug flag, remove one bug (echo to one interface in another's interrupt); still didn't found why there's a trash of output in input buffer of interface 0
    [main.c]
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2025-09-11 Add MLXtest, 4.8ms for parsing image in standard range
    [alpha.csv, eeprom.csv, frame0.csv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]
2025-09-13 seems like I2C start works right, need some fixes for large data amount
2025-09-14 Start fixing code for real usage
    [main.c]
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2025-11-11 add schematics, start drawing PCB
    [mainboard.kicad_pcb, mainboard.kicad_sch]
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2026-01-15 fixed bug with wrong DIAG output tracking
    [ADC.kicad_sch, mcubase.kicad_sch, motors.kicad_sch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]
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2026-03-06 starting CAN-GPIO, have a lot of errors
    [stm32.kicad_pcb, stm32.kicad_sch]
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2026-03-17 add SPI, not working yet (also need to set SPOL/SPHA etc)
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2026-03-23 remove flood in case of error
    [main.c]
2026-07-13 some minor bugs fixed
    [main.c]
2026-07-23 fixed -flto problem (usb_dev.c needs -fno-lto)
    [main.c]
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2026-10-01 fixed schematics
    [X_opto.kicad_sch, fx3u_24mr.kicad_sch]

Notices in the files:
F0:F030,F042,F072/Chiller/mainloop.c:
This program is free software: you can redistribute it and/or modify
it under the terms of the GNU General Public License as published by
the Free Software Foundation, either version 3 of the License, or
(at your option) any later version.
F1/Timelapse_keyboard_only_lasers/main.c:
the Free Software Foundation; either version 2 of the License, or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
